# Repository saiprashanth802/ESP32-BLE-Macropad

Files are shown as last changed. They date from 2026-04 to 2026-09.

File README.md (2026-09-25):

# ESP32 BLE HID MacroPad

> An open-source, battery-powered wireless BLE HID macro pad built on ESP32 with NimBLE stack. Hand-wired with a custom FDM-printed enclosure, fully self-contained shortcut controller with an on-device UI — no companion app required.



---

## Versions

Every version lives side by side in this repo — `firmware/v4/`, `firmware/v5/`,
`cad/stl/v5/` and so on. **`main` is always the latest working state**; released
versions are marked with **git tags**, so you can grab any of them:

```bash
git clone https://github.com/saiprashanth802/ESP32-BLE-Macropad.git
git checkout v4.1     # or v5.0 — see Releases for downloadable zips
```

| Version | Tag | Status | Description |
|---|-----|---|---|
| v3 | — | ✅ Complete | 8-button, ST7735 128×160, ESP32-BLE-Keyboard — flagship build |
| v4 | `v4.1` | ✅ Stable | NimBLE stack, ghost connection fix, BUILD MODE |
| v4 + Media Remote | — | 🔬 Testing | Wireless AS5600 scroll wheel via ESP-NOW |
| v5 | `v5.0` | ✅ Built & Running | 12-key MX matrix, ST7789 240×320, multi-host BLE, robot face, Windows companion app |
| v5.1 | `v5.1` | ✅ Current | Local-LLM rewrite menu driven from the pad, wireless encoder puck complete |

---

## v3 — Flagship Build

> Primary portfolio entry. 8-button macro pad with ST7735 display, NimBLE BLE HID, and on-device preset switching with BUILD MODE.

### Build Photos

| | |
|---|---|
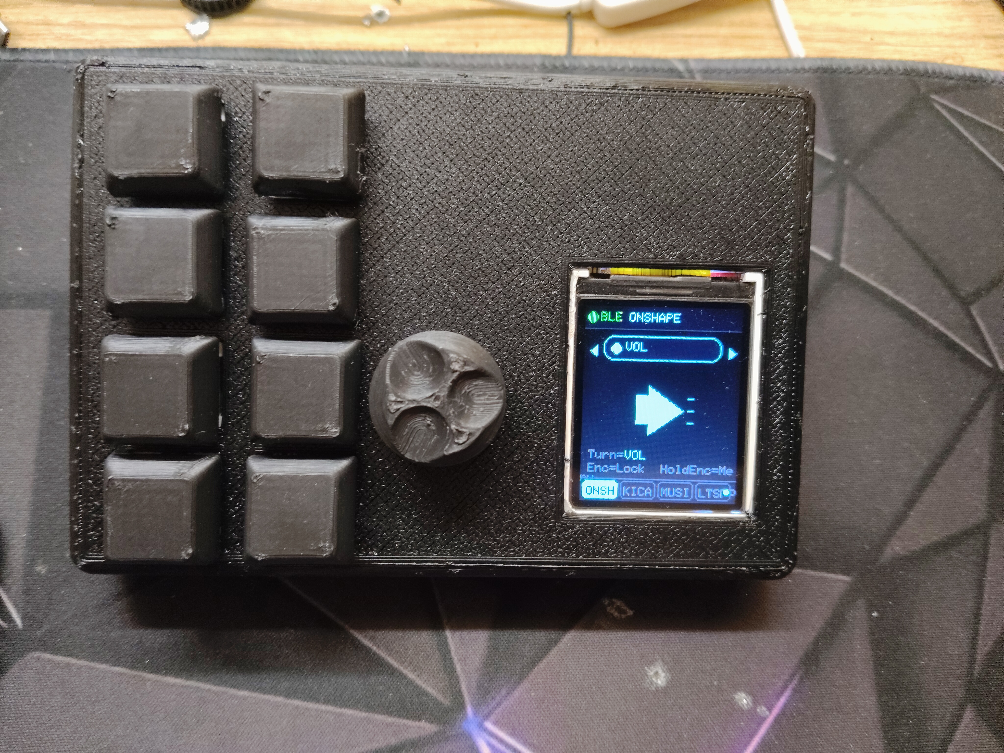
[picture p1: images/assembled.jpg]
Assembled
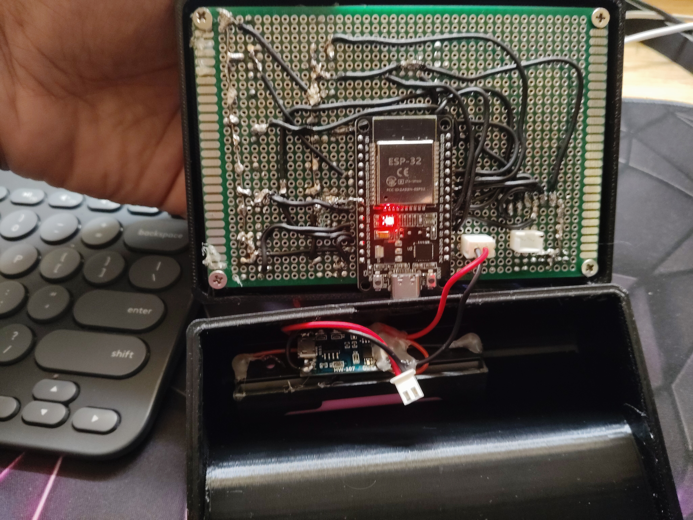
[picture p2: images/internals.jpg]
Internals
|  |  |
| Assembled v3 | Internal wiring |

| | |
|---|---|
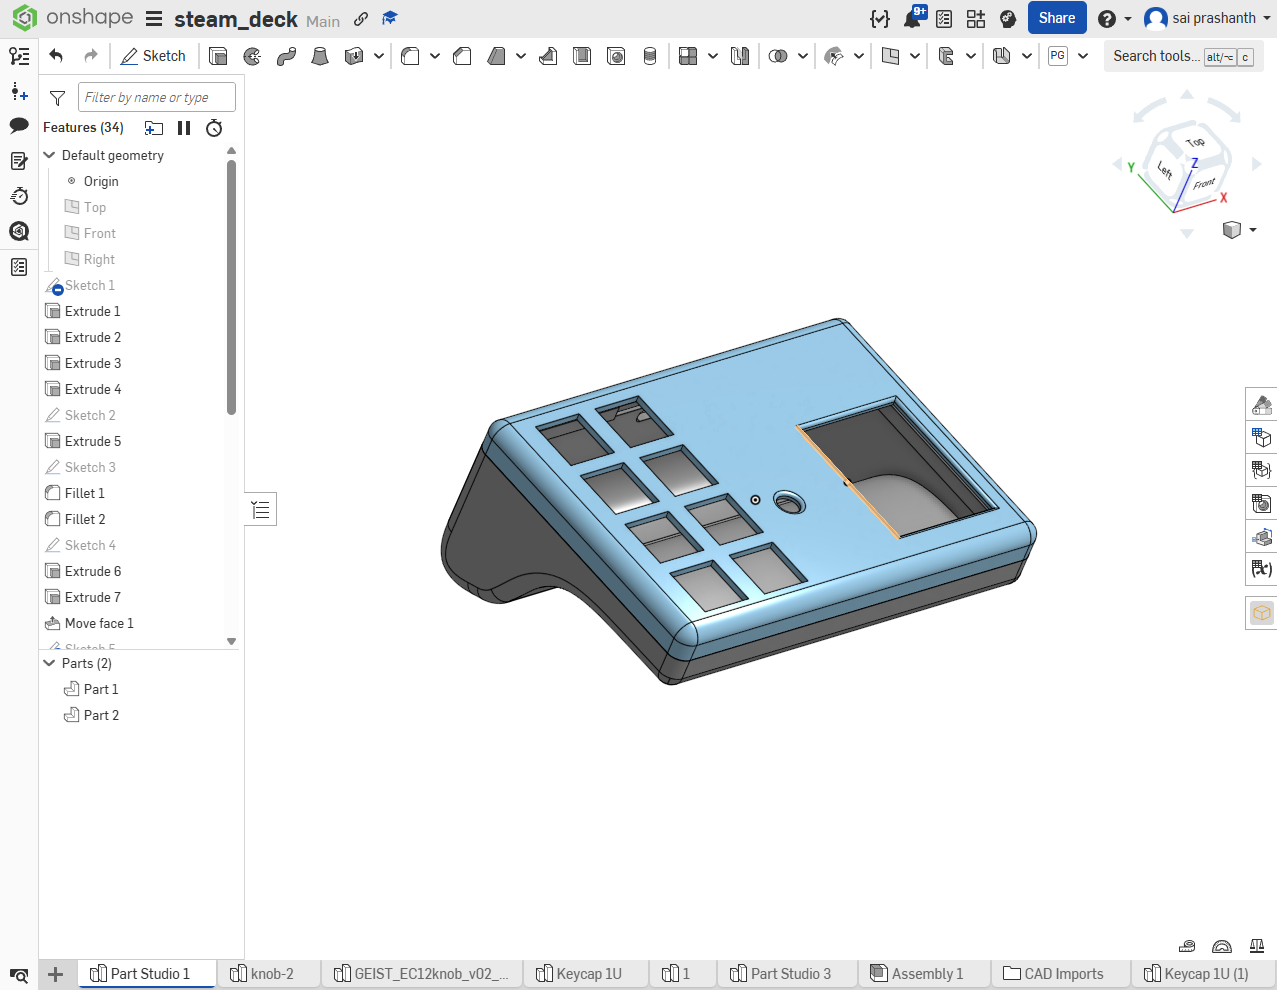
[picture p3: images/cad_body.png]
CAD Body
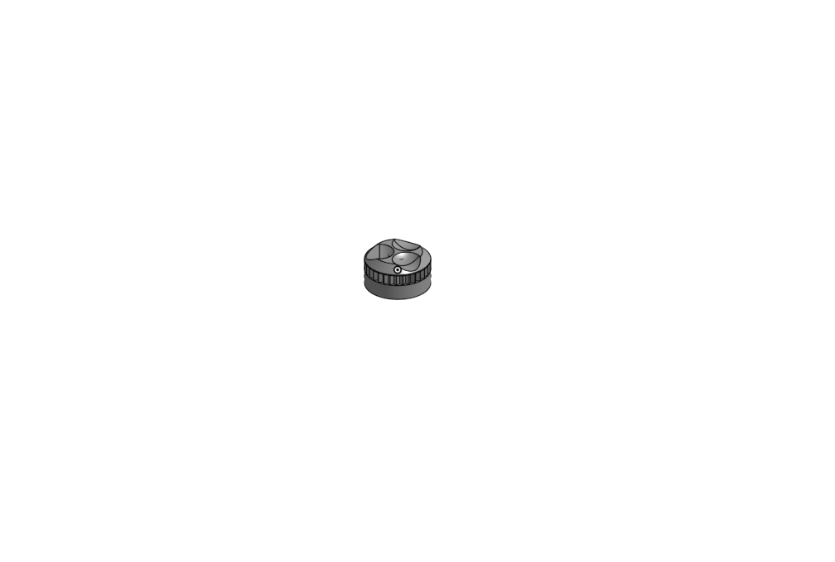
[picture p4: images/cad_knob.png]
CAD Knob
|  |  |
| Enclosure CAD | Encoder knob CAD |

### Hardware
- ESP32 WROOM-32
- ST7735 128×160 TN display
- 8× tactile switches in 4×2 layout
- EC11 rotary encoder + custom skull knob
- TP4056 + 18650 2600mAh battery
- M3 corner studs with heat-set inserts
- Hand-wired, FDM printed enclosure (PLA, 0.2mm, 20% gyroid)

### Features
- 8 presets: OnShape, KiCad, Music, Gaming, LTspice, SYS, DEV, EDIT
- BUILD MODE — remap any button live (hold encoder 1.5s)
- Encoder modes: VOL / SCROLL / ZOOM / ALT-TAB
- Settings menu: brightness, sleep timeout, sensitivity, OS layout
- OS Layout: Windows / Linux — remaps shortcuts live
- RTOS light-sleep with GPIO wakeup
- Wake-key buffer + reconnect HUD
- BLE bond clear (hold encoder 3s)
- Estimated battery life: 3–4 months typical desk use

### GPIO Allocation (v3/v4)

| GPIO | Function |
|---|---|
| 14,13,26,25,22,21,35,19 | 8× buttons |
| 2, 4 | Encoder CLK, DT |
| 15 | Encoder SW |
| 5, 17, 16, 12 | TFT CS, DC, RST, BL |
| 23, 18 | SPI MOSI, SCLK |

---

## v4 — Current Stable

> Migrated to NimBLE-Arduino to fix persistent BLE ghost-connection bug on Windows sleep/wake cycles.

### Key Changes from v3
- NimBLE-Arduino replaces ESP32-BLE-Keyboard
- GAP-layer callbacks for reliable connect/disconnect tracking
- 1N5819 Schottky diode on VIN rail isolating charger from USB supply
- `esp_sleep_disable_wakeup_source()` before re-arming GPIO wakeup each cycle
- `ledcAttach()` called on every wake to restore PWM backlight
- Firmware: `macropad_v4_nimble_espnow.ino`

### TFT_eSPI User_Setup.h

```cpp
#define ST7735_DRIVER
#define TFT_CS   5
#define TFT_DC   17
#define TFT_RST  16
#define TFT_WIDTH  128
#define TFT_HEIGHT 160
#define TFT_MOSI 23
#define TFT_SCLK 18
```

---

## Media Remote — Test Phase

> Standalone wireless scroll wheel using AS5600 magnetic encoder. Connects to v4 macropad via ESP-NOW or directly to PC via BLE HID. Designed for high-resolution smooth scrolling with velocity-based acceleration.

### Hardware
- ESP32 NodeMCU dev board
- AS5600 magnetic rotary encoder (I2C, 12-bit resolution, 4096 steps/rev)
- Custom 3D printed enclosure with bearing-mounted 50mm scroll wheel
- Diametrically magnetized cylinder magnet on axle
- 3× tactile buttons — Play/Pause, Next, Prev

### Design & Prototype

| | |
|---|---|
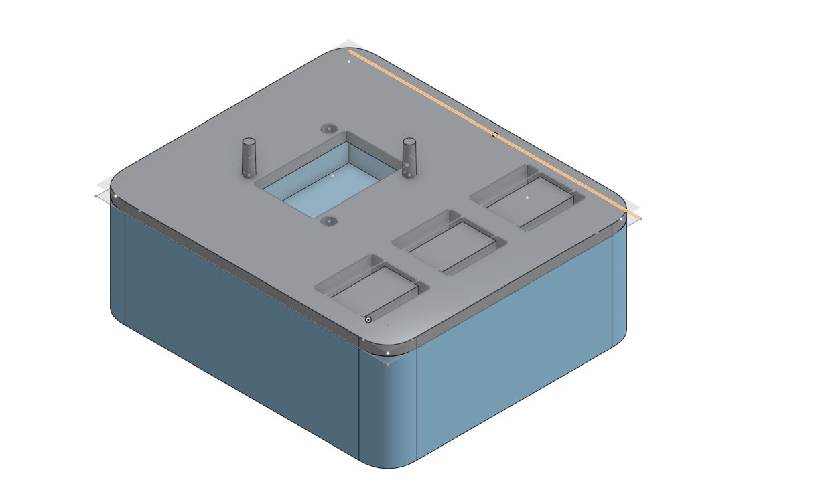
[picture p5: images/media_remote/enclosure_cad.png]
Enclosure CAD
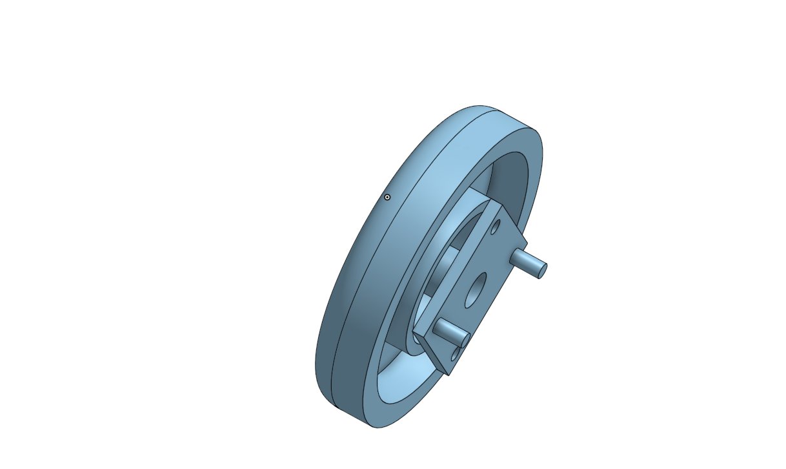
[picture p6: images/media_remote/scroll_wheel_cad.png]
Scroll wheel CAD
|  |  |
| Enclosure CAD | Scroll wheel with bearing mount CAD |

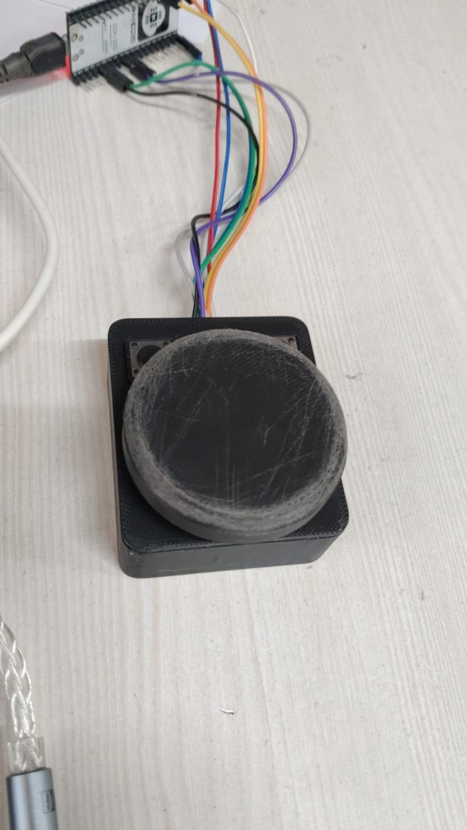
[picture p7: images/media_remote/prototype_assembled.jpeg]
Media remote prototype


*Prototype — printed enclosure with 50mm scroll wheel, AS5600 underneath, wired to NodeMCU ESP32S*

### Features
- Velocity-accelerated volume control — slow turn = fine steps, fast spin = large jumps
- Adjustable sensitivity 1–10, saved to NVS
- Hold Btn1 + turn wheel = adjust sensitivity live
- Hold Btn1 + Btn3 for 1.5s = toggle ESP-NOW ↔ BLE mode
- Mode and sensitivity persist across power cycles
- LED blink feedback: 1 blink = ESP-NOW, 3 blinks = BLE

### Modes

| Mode | Description |
|---|---|
| BLE HID | Connects directly to PC as "MediaRemote" |
| ESP-NOW | Sends to v4 macropad which relays via BLE to PC |

### Wiring

| Pin | GPIO | Function |
|-----|---|---|
| AS5600 SDA | 21 | I2C data |
| AS5600 SCL | 22 | I2C clock |
| BTN1 Play/Pause | 27 | INPUT_PULLUP → GND |
| BTN2 Next | 26 | INPUT_PULLUP → GND |
| BTN3 Prev | 25 | INPUT_PULLUP → GND |
| LED | 2 | Onboard LED |

---

## v5 — Built & Running

> Full redesign, **assembled and working**. 12-key MX mechanical switch matrix (4×3 landscape), ST7789 240×320 IPS display, **multi-host BLE with 3 device slots (Logitech Easy-Switch style)**, a state-reactive robot face with personalities, and a Windows companion app that turns the pad into a Stream Deck.

### Build Photos

| | |
|---|---|
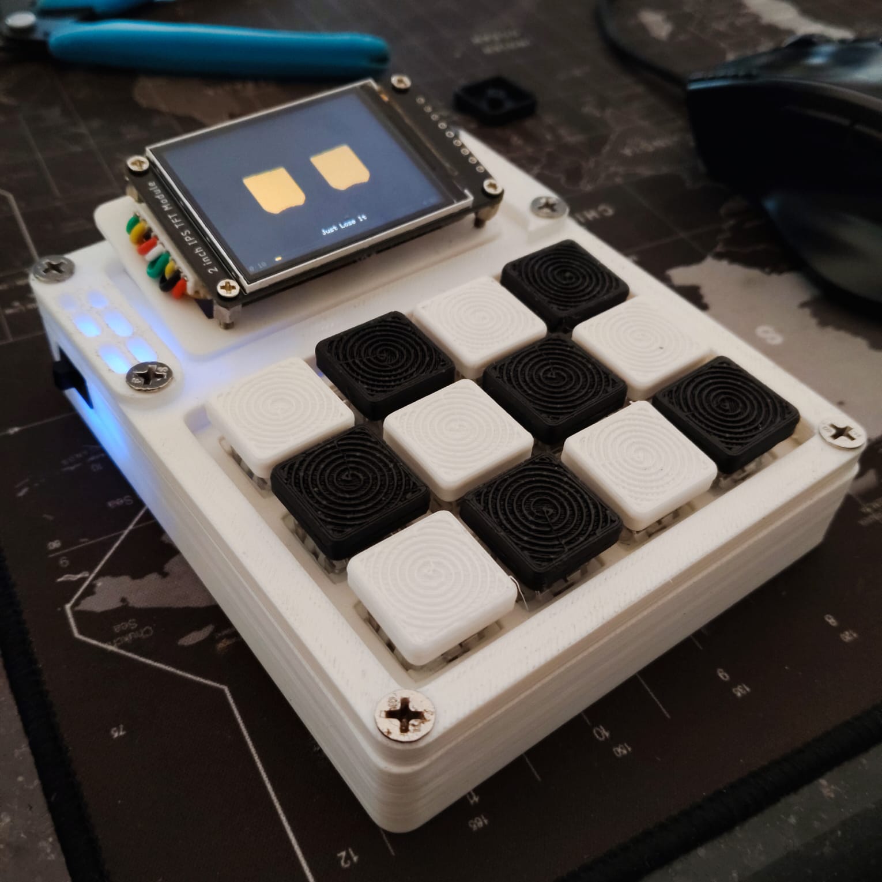
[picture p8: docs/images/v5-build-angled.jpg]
Assembled v5, angled
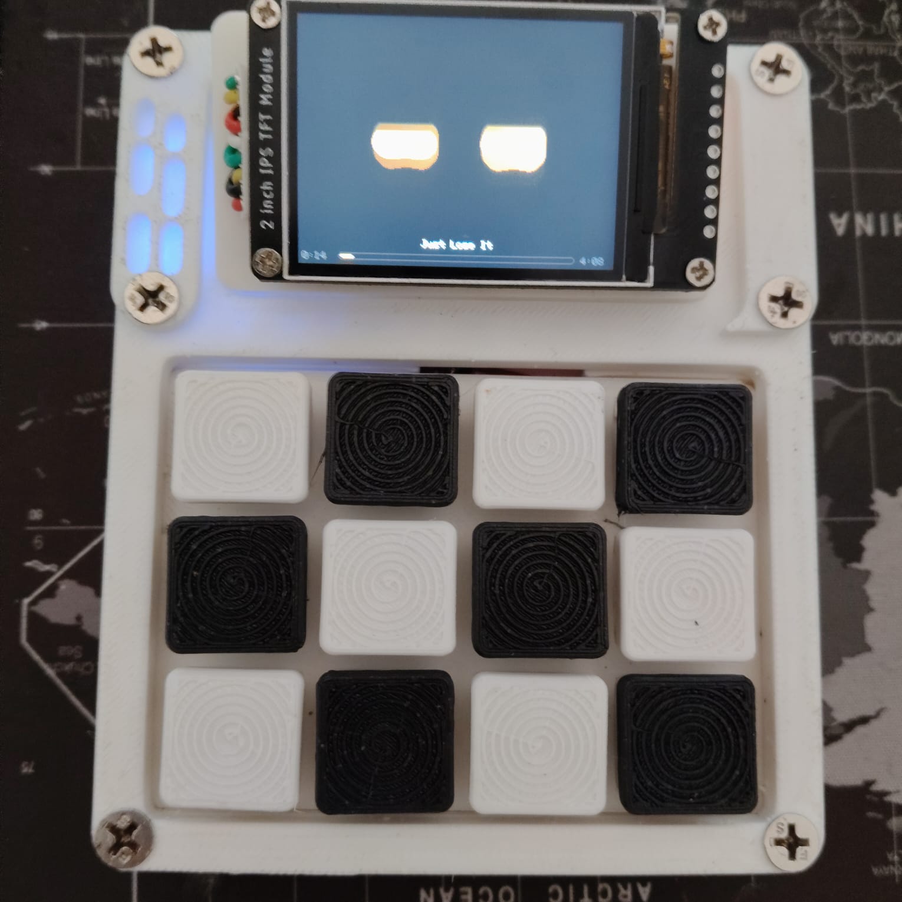
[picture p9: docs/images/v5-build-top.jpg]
v5 from above
|  |  |
| Assembled v5 — printed case, spiral-top keycaps, blue accent lighting | Top-down: 4×3 MX grid and the 2" IPS display |

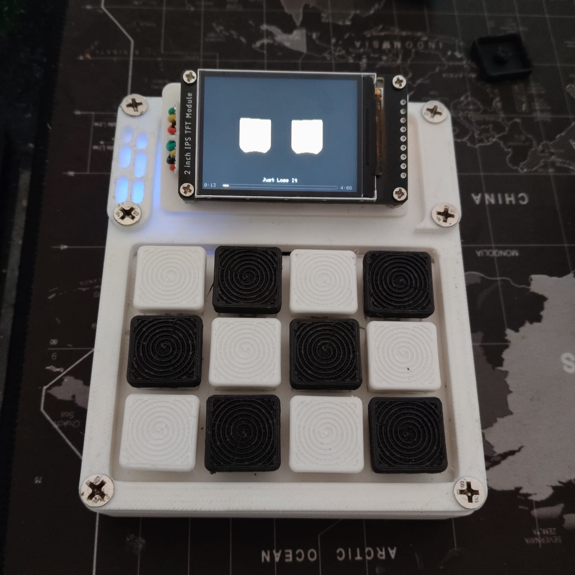
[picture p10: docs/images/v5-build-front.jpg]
v5 front view


*The screen shows the pad's two live features at once: the procedural robot eyes in
their default robotic blue, and the now-playing strip — track title with a progress
bar and elapsed/total time, streamed from the host by the companion app.*

**Print files:** [`cad/stl/v5/`](cad/stl/v5) — three case parts plus the switch plate.

### Multi-Host BLE — use it like a Pebble Keys
- 3 host slots, each remembers one bonded device (NVS persisted across power cycles)
- Hold **FN (K9) 1s** → tap **K1/K2/K3** to jump between paired devices
- Hold the slot key 1.5s instead to (re-)pair that slot with a new device
- **Each slot advertises its own static-random BLE address**, so every host stores an independent bond. This is what makes the slots real: with one shared identity, two OSes dual-booting the same machine present the *same* controller MAC, collapse onto one slot, and each re-pair overwrites the other's link key — the endless forget-and-re-pair loop
- Switching re-advertises **open** (no accept-list — whitelist filtering breaks reconnection from resolvable private addresses); a bonded host that belongs to a different slot is rejected in software
- Status bar shows the three slots like Easy-Switch LEDs (green = connected, amber = waiting, magenta = pairing)
- Firmware: `firmware/v5/macropad_v5.ino` (NimBLE 2.x API, single file)

### Face — state-reactive robot eyes / GIF screensaver
- Procedural eyes that react to device state: blink when idle-connected, dart when disconnected, widen in pairing mode, glance toward the slot on Easy-Switch, droop before sleep
- **Expression packs**: every eye parameter (color, geometry, blink/glance timing) is JSON in the config API — the companion app can generate personalities without reflashing
- Or upload a looping **GIF** (≤ ~700 KB) through the web UI as an ambient screensaver
- Settings → FACE (OFF/IDLE/ALWAYS) and STYLE (EYES/GIF); first press always just wakes, never types
- Custom partition table: dual 1.5 MB OTA slots + 896 KB SPIFFS for animations

### Rewrite Menu — local LLM text tools, driven from the pad
- Select text anywhere, press a key on the pad, pick a style — the pad rewrites it in place
- Styles: formalise, casualise, shorten, clarify, fix spelling/grammar, summarise, expand rough notes into an email, or treat the selection as a prompt and answer it
- Runs against a local **[Ollama](https://ollama.com)** instance, so **nothing leaves the machine** unless a style is deliberately pointed at a hosted model
- Prompts, temperature, reasoning and per-style model live in a **hot-reloaded `styles.json`** — tune them without a rebuild
- Pad shows the style picker, then ACCEPT / REGEN / CANCEL; the side-by-side preview on screen is editable before you accept
- Built entirely on the existing host-link opcodes — **no firmware changes required**
- A **fine-tuned FIX model** was trained for this and measured against the general-purpose
  one across two sizes and four epoch counts. It wins on corrections and speed and loses on
  restraint, which is the axis that decides — so it did not ship, and the lab is in the repo
  anyway: [`ml/`](ml) and [`docs/FIX_MODEL_FINETUNE.md`](docs/FIX_MODEL_FINETUNE.md)
- Full guide: [`docs/REWRITE_MENU.md`](docs/REWRITE_MENU.md) · Linux setup:
  [`docs/LINUX_REWRITE_SETUP.md`](docs/LINUX_REWRITE_SETUP.md)

### Companion App — Windows and Linux

> The pad works standalone. The companion turns it into a Stream Deck: it launches
> and focuses apps from a key press, streams now-playing to the pad's screen,
> switches presets to follow the foreground window, feeds the puck a real volume
> number, and drives the rewrite menu.

- Two front-ends over one shared **.NET 9** core — `MacroPadDeck.Core` holds the wire
  protocol, profiles and orchestration; `MacroPadDeck` is WinRT/SMTC/WPF, and
  `MacroPadDeck.Linux` is BlueZ/MPRIS/X11/GTK3
- **Install, build and run:** [`companion/README.md`](companion/README.md) — .NET 9 SDK
  per platform, the dependencies, pairing, the publish command, and what each failure
  in `deck.log` means

### Config Mode — wireless setup + OTA firmware update
- **Settings → CONFIG (WiFi/OTA)** suspends BLE and raises a WiFi hotspot (`MacroPad-Setup` / `macropad123`, `http://192.168.4.1`)
- Built-in web UI + JSON API to remap keys, edit presets, and change settings — no re-flash needed
- Every key can be a built-in action, an **arbitrary modifier+keycode chord**, a media code, a **type-a-string**, or a **multi-step macro** — the schema a companion app targets
- **OTA firmware update**: upload a new `.bin` from the browser; it flashes the inactive OTA partition and reboots (safe rollback if it fails)
- WiFi and BLE never run at once (WROOM-32 coexistence); entering/leaving Config Mode reboots cleanly
- Full contract: [`docs/CONFIG_API.md`](docs/CONFIG_API.md)

### Wireless Encoder Puck — a dial that isn't attached to anything

| | |
|---|---|
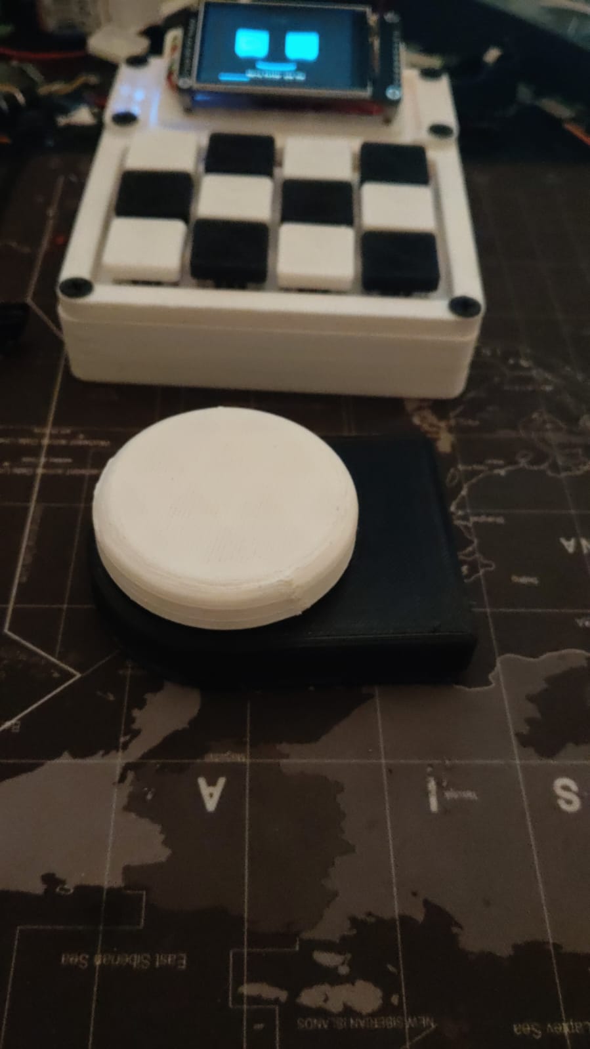
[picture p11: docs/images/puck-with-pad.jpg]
Puck beside the pad
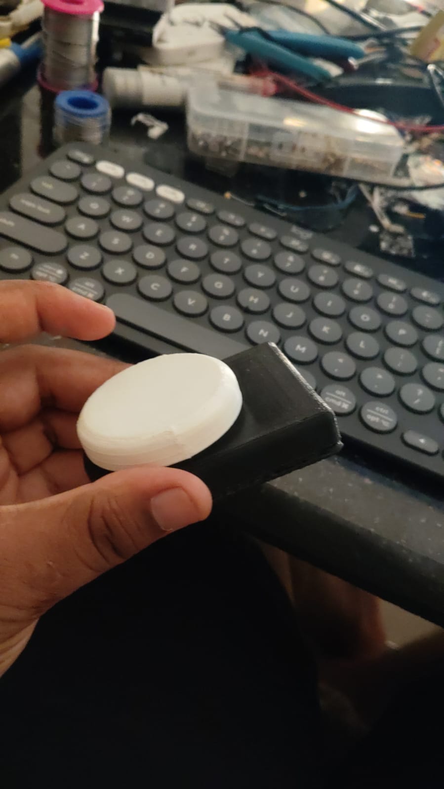
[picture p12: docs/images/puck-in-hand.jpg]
Puck in hand
|  |  |
| The puck beside the v5 — a separate battery-powered device, no cable between them | 50 mm dial in the two-part printed housing |

- **Separate device**, talks to the pad over **ESP-NOW** — no cable, no second BLE connection to manage
- **AS5600 magnetic angle sensor** — 12-bit, contactless, nothing mechanical to wear out. The magnet is diametrically magnetised and sits in a pocket in the dial
- **The pad owns the dial mode** (VOLUME / ZOOM). The puck renders whatever it's told and never self-changes, so a pad key and the puck can't disagree
- **Volume is pushed, never estimated.** BLE HID volume is relative — the pad sends up/down and is never told the level — so the companion reading Windows Core Audio is the only way either device knows a real number
- **Deep sleep when unlinked**, waking on rotation. The AS5600 has no motion interrupt, so waking is timer-poll-and-look with a movement threshold, which stops a knock or thermal drift waking it
- **Sealed housing with no reset button** — spinning the dial a few turns while unlinked reboots it. Gated strictly on being unlinked, since spinning hard is completely ordinary during normal volume use
- Wiring: [`hardware/puck_wiring.md`](hardware/puck_wiring.md) · Protocol: [`docs/PUCK_PROTOCOL.md`](docs/PUCK_PROTOCOL.md) · Print files: [`cad/stl/puck/`](cad/stl/puck)

### Hardware Spec
- NodeMCU ESP32-S V1.1 (WROOM-32) dev board
- ST7789 240×320 IPS display, landscape mount, glass flush-mounted (30.6×40.8mm active area)
- 12× MX compatible mechanical switches, plate mount, 4×3 landscape matrix, 19.05mm pitch
- 12× 1N4148 diodes for n-key rollover (cathode → row line — see `hardware/pin_reference_v5.md`)
- Wireless encoder puck: AS5600 + 50mm bearing-mounted dial, ESP-NOW (separate device — **built and working**; see [`hardware/puck_wiring.md`](hardware/puck_wiring.md) and [`docs/PUCK_PROTOCOL.md`](docs/PUCK_PROTOCOL.md))
- CKCS charge+boost module + 18650 cell
- Custom copper-tape ridge substrate PCB

### Enclosure
- 115×95×30mm main body
- Encoder dial lobe: half-proud right edge, 50mm diameter, 25mm proud (XP-Pen style)
- Screen: 31.0×41.2mm flush glass window, 35.2×48.4mm module ledge 2.1mm deep
- Bottom cover: M3 screws into brass heat-set inserts, 4× corners

### PCB Technique — Copper Tape Ridge Substrate
3D printed plate with elevated ridges as trace isolation guides. A single copper sheet is laid over the entire surface — the ridges act as cutting guides. Scalpel-cut along ridge edges isolates traces. Looks like a real PCB, built from scratch.

### v5 GPIO Allocation

| GPIO | Board Label | Function | Notes |
|---|---|---|---|
| 18 | P18 | TFT SCK | SPI clock |
| 23 | P23 | TFT MOSI | ST7789 SDA |
| 5  | P5  | TFT CS  | |
| 21 | P21 | TFT DC  | |
| 22 | P22 | TFT RST | |
| 19 | P19 | TFT BL  | PWM via LEDC |
| 25 | P25 | Matrix Row 1 | Driven LOW to scan |
| 26 | P26 | Matrix Row 2 | Driven LOW to scan |
| 27 | P27 | Matrix Row 3 | Driven LOW to scan |
| 32 | P32 | Matrix Row 4 | Driven LOW to scan |
| 33 | P33 | Matrix Col 1 | INPUT_PULLUP |
| 13 | P13 | Matrix Col 2 | INPUT_PULLUP |
| 14 | P14 | Matrix Col 3 | INPUT_PULLUP |

> Zero strapping pins used — clean boot every time, no pull resistors needed for boot. No I2C or encoder switch on the main board — the AS5600 puck is wireless. Full details + diode orientation: `hardware/pin_reference_v5.md`.

---

## Repository Structure

```
ESP32-BLE-MacroPad/
├── firmware/
│   ├── v4/macropad_v4_nimble_espnow.ino   — v4 + optional ESP-NOW
│   ├── v5/
│   │   ├── macropad_v5/                   — v5 multi-host firmware + partition table
│   │   ├── puck_encoder/                  — wireless encoder puck (ESP32)
│   │   ├── puck_encoder_8266/             — puck on ESP-12E
│   │   └── User_Setup.h                   — TFT_eSPI config for the ST7789
│   ├── media_remote/                      — BLE + ESP-NOW scroll wheel
│   └── tests/                             — per-peripheral bring-up sketches
├── companion/
│   ├── README.md                          — install / build / run — start here
│   ├── MacroPadDeck.Core/                 — protocol, profiles, controller (net9.0)
│   ├── MacroPadDeck/                      — Windows front-end (WinRT/WPF)
│   └── MacroPadDeck.Linux/                — Linux front-end (BlueZ/MPRIS/GTK3)
├── ml/                                    — the FIX fine-tune lab: data generator,
│                                            eval harness, training configs, runbook
├── cad/stl/                               — print files: v5 case, keycaps, puck
├── hardware/
│   ├── pin_reference_v5.md                — complete v5 GPIO table + diode orientation
│   ├── puck_wiring.md                     — encoder puck wiring
│   ├── kicad/                             — KiCad project + fab gerbers
│   ├── datasheets/                        — ESP-12E
│   └── ESP32_DevKitC_v4.kicad_mod         — custom KiCad footprint
├── docs/
│   ├── CONFIG_API.md                      — host-link opcodes and the JSON config API
│   ├── REWRITE_MENU.md                    — local-LLM text tools
│   ├── LINUX_REWRITE_SETUP.md             — ydotool / Wayland one-time setup
│   ├── FIX_MODEL_FINETUNE.md              — the fine-tune, measured, and why it lost
│   ├── PUCK_PROTOCOL.md                   — ESP-NOW protocol v3
│   └── ROADMAP.md · TESTING_LOG.md
├── scripts/setup-ydotool.sh
└── README.md
```

---

## Dependencies

| Library | Purpose |
|---|---|
| NimBLE-Arduino | BLE HID stack |
| TFT_eSPI | Display driver |
| Preferences | NVS persistent storage |
| Wire | I2C for AS5600 |
| esp_now | ESP-NOW for media remote |

Companion app (see [`companion/README.md`](companion/README.md)):

| Requirement | Purpose |
|---|---|
| .NET 9 SDK | Builds all three companion projects |
| BlueZ / WinRT | BLE host link to the pad |
| GTK3 + libayatana-appindicator | Linux tray and editor |
| MPRIS / SMTC | Now-playing source |
| Ollama (optional) | Local model behind the rewrite menu |

---

## Key Learnings

- **NimBLE vs ESP32-BLE-Keyboard** — NimBLE with GAP callbacks is required for reliable connect/disconnect tracking. The Arduino BLE stack returns false positives after Windows sleep/wake.
- **GPIO 12 strapping pin** — Must read LOW at boot. Avoided entirely in v5 by moving TFT backlight to GPIO 19.
- **LEDC + BLE init order** — BLE radio init resets the LEDC peripheral. Always call `ledcAttach()` after `NimBLEDevice::init()`.
- **WiFi + BLE coexistence** — ESP-NOW and NimBLE share the antenna. Made optional in v4 (toggle in settings) to avoid connection instability.
- **ST7789 RAM constraint** — Full 240×320 16-bit sprite = 153KB, too large for WROOM-32 with BLE active. Solution: direct TFT drawing with small reusable sprites.
- **Input-only GPIOs** — GPIO 34, 35, 36, 39 have no internal pullups. Always use external 10kΩ resistors.

---

## License

**CC BY-NC 4.0** — Free to use and modify for personal and non-commercial purposes only. Commercial use requires explicit written permission from the author.

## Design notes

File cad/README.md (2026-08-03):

# CAD — Print Files

All STL files are export-ready. Slice and print as-is.

## v5 — the built pad (current)

These are the parts in the photos in the main README — 12-key 4×3 layout with a
2" IPS TFT above the grid. **Use these for a v5 build**; the folders below are
the earlier encoder-based design.

```
cad/stl/v5/
├── v5_case_bottom.stl        ← bottom shell (ESP32 + wiring bay)
├── v5_case_top_plate.stl     ← top plate (key openings + display shelf)
├── v5_display_mount.stl      ← display mount (2" IPS TFT carrier)
├── v5_switchplate.stl        ← switch plate (12 × MX cutouts, 19.05mm pitch)
└── v5_keycap_low_profile.stl ← low-profile keycap, print 12×
```

**Stack-up, bottom to top:** case bottom → switch plate (switches clip in) →
top plate → display mount carrying the TFT on the raised shelf. M3 screws pass
through the corner bosses to hold the sandwich together.

### Print settings (as actually printed)

| Part | Qty | Layer | Walls | Infill |
|---|-----|---|---|---|
| Case parts, switch plate | 1 each | 0.2 mm | 3 | 30% adaptive cubic |
| `v5_keycap_low_profile.stl` | 12 | 0.12 mm | 3 | 100% |

White PLA for the case; the build in the photos alternates black and white
keycaps in a checkerboard. The fine layer height plus solid infill is what gives
the keycaps their crisp concentric spiral top surface — the pattern is the
slicer's top-surface path, so **keep the 100% infill and 0.12 mm layers if you
want that look**. The assembled unit is lit by a blue LED strip behind the
left-hand vent slots.

## Encoder puck (wireless dial)

The standalone ESP-NOW knob — see `docs/PUCK_PROTOCOL.md` for the firmware side
and `hardware/puck_wiring.md` for the electronics.

```
cad/stl/puck/
├── puck_dial.stl               ← the knob itself        50 × 50 × 12 mm
├── puck_dial_counterpart_1.stl ← housing body           73 × 55 × 17 mm
└── puck_dial_counterpart_2.stl ← housing lid / plate    73 × 55 ×  7 mm
```

The two counterpart parts share a 73 × 55 mm footprint and stack to 24 mm; the
50 mm dial seats into them. The three files are a **matched set** — don't mix
them with an earlier counterpart export.

> ✅ **Printed and test-fitted (2026-08-03).** The dial spins freely with no
> wobble, both counterpart halves mate, and the **AS5600 magnet pocket worked
> first time** — no tolerance iteration was needed, despite the gap being the one
> dimension the sensor is genuinely fussy about (diametrically magnetised magnet,
> centred on the chip, **0.5–3 mm**). A radial or axially magnetised magnet will
> not work at any gap.

| | |
|---|---|
| Printed puck beside the pad | Printed puck in hand |
| The printed puck beside the v5 | Dial seated in the two-part housing |

The dial is sealed in the housing with no reachable reset button, by design — the
firmware reboots on a fast spin gesture instead. See
[`hardware/puck_wiring.md`](../hardware/puck_wiring.md).

## Earlier design (v2/v3, encoder-based)

```
cad/stl/
├── enclosure/
│   ├── enclosure_top.stl    ← top shell  (buttons + display + encoder cutouts)
│   └── enclosure_base.stl   ← base tray  (PCB + 18650 cell bay)
├── keycap/
│   ├── keycap_v1.stl        ← keycap body (main variant, high detail)
│   ├── keycap_v2.stl        ← keycap variant 2
│   ├── keycap_v3.stl        ← keycap variant 3 (minimal)
│   └── keycap_v4.stl        ← keycap variant 4
└── knob/
    └── encoder_knob.stl     ← EC12 encoder knob (GEIST KLOTZ v4, press-fit D-shaft)
```

## 🖨 Print Settings

| Part | Qty | Layer  | Walls | Infill | Supports |
|---|-----|---|---|---|---|
| enclosure_top.stl | 1 | 0.2mm  | 3 | 20% gyroid | Yes (TFT overhang) |
| enclosure_base.stl | 1 | 0.2mm  | 3 | 20% gyroid | No |
| keycap_v*.stl | 8x  | 0.15mm | 3 | 15% | No |
| encoder_knob.stl | 1 | 0.15mm | 4 | 20% | No |

- Material: PLA (PETG also works for keycaps)
- Bed adhesion: Brim for enclosure parts, Skirt for keycaps/knob
- Keycaps are press-fit over 12x12mm tact switches — no hardware needed
- Encoder knob is press-fit on the EC11/EC12 6mm D-shaft

## 🔧 Assembly Notes

- Print 8 keycaps (same file, plate them in your slicer)
- Enclosure top and base friction-fit or secure with M3 screws through corner bosses
- The TFT module slots into the rectangular window in enclosure_top.stl
- Encoder shaft passes through the circular hole beside the TFT window

## 🛠 CAD Source

Modelled in Onshape (browser-based, free for public projects).
Project name: steam_deck

## v2 -> v3 CAD Improvements Planned
- [ ] Snap-fit lid clips (replace friction fit)
- [ ] Internal standoffs for PCB screw mounting
- [ ] Tighter TFT window clearance
- [ ] Dedicated 18650 retainer in base tray
- [ ] Cable channel for battery wires

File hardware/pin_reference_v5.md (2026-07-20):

# MacroPad v5 — Pin Reference (multihost wiring)

Board: **NodeMCU ESP32-S V1.1** (WROOM-32, no PSRAM). P-label = GPIO number (P18 = GPIO18).
13 pins used: TFT SPI (6) + 4×3 matrix (7). The AS5600 encoder is now a
**separate wireless puck** (ESP12-E + ESP-NOW) — no I2C or encoder switch on
the main board anymore.

## ESP32 GPIO Allocation

| GPIO | Board Label | Function | Direction | Notes |
|---|---|---|---|---|
| 18 | P18 | TFT SCK  | OUTPUT | SPI clock |
| 23 | P23 | TFT MOSI | OUTPUT | SPI data (ST7789 SDA) |
| 5  | P5  | TFT CS | OUTPUT | HIGH at boot — fine |
| 21 | P21 | TFT DC | OUTPUT | |
| 22 | P22 | TFT RST  | OUTPUT | |
| 19 | P19 | TFT BL | OUTPUT | PWM via LEDC (sketch-driven) |
| 25 | P25 | Matrix Row 1 (top) | OUTPUT | driven LOW one at a time |
| 32 | P32 | Matrix Row 2 (mid) | OUTPUT | driven LOW one at a time |
| 33 | P33 | Matrix Row 3 (bot) | OUTPUT | driven LOW one at a time |
| 26 | P26 | Matrix Col 1 | INPUT | INPUT_PULLUP |
| 14 | P14 | Matrix Col 2 | INPUT | INPUT_PULLUP, JTAG-shared (fine) |
| 27 | P27 | Matrix Col 3 | INPUT | INPUT_PULLUP |
| 13 | P13 | Matrix Col 4 | INPUT | INPUT_PULLUP, JTAG-shared (fine) |
| VIN | 5V | Power in  | POWER | From CKCS 5V out |
| 3V3 | 3V3 | 3.3V out | POWER | To TFT VCC |

All matrix inputs use internal pullups — no external resistors needed
(GPIO 34/36/39 input-only pins are no longer used).

## Key Matrix (3 rows × 4 cols = 12 keys) — AS BUILT

**Verified on hardware 2026-07-20 with a pairwise conduction probe** — this
supersedes every earlier pin grouping. The 3 physical rows are the driven
lines; the 4 physical columns are read with `INPUT_PULLUP`.

```
           Col1(26)  Col2(14)  Col3(27)  Col4(13)
Row1(25)     K1        K2        K3        K4
Row2(32)     K5        K6        K7        K8
Row3(33)     K9(FN)    K10       K11       K12
```

Logical key index in firmware: `idx = row*4 + col` — identical to the
landscape grid the display shows. K9 (bottom-left) = FN.

### Diode orientation (verified)

Each switch has a 1N4148 with the **cathode (band) toward the ROW line**
(P25/P32/P33); current flows column → switch → row. The firmware's
row-driven scan matches this as-built orientation.

## Strapping Pins — Avoided

| GPIO | Issue | Status |
|---|---|---|
| 0, 2, 12, 15 | Boot mode / flash voltage | **Not used at all** |

If your board has PSRAM, GPIO 16/17 are reserved — this pinout avoids them
too (standard NodeMCU-32S WROOM-32 has no PSRAM).

## TFT_eSPI configuration

Copy `firmware/v5/User_Setup.h` over
`<Arduino sketchbook>/libraries/TFT_eSPI/User_Setup.h`. It contains the pins
above, `ST7789_DRIVER`, 40MHz SPI and the font loads (`LOAD_GLCD` is
mandatory — text renders blank without it).

## Flashing this specific board (bench NodeMCU-32S, MAC 84:1F:E8:2B:33:48)

Its Boya flash chip (mfr 0x68) **cannot run at the default 80MHz flash clock**
— the 2nd-stage bootloader crash-loops printing only `entry 0x4008059c`.
In Arduino IDE set:

- **Tools → Flash Frequency → 40MHz**  (mandatory)
- **Tools → Upload Speed → 115200**  (921600 aborts with
  "Packet content transfer stopped" on this board/cable)

Also disconnect the display while flashing, and power it from **3V3, never
5V** — an overdriven backlight sags the rail enough to kill flash writes.

## Power Chain

```
USB-C socket → CKCS module USB-C pads (wired)
CKCS B+ / B- → 18650 cell
CKCS 5V out  → ESP32 VIN
ESP32 3V3    → TFT VCC
```

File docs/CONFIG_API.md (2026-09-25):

# MacroPad v5 — Config & OTA API

The device exposes a small HTTP + JSON API used to change layouts, key
assignments, shortcuts and to push firmware updates over the air. This is the
stable contract a companion app or script targets.

## Entering Config Mode

On the device: **Settings → CONFIG (WiFi/OTA)**. This:

1. Tears down BLE (frees the radio + RAM — WiFi and BLE don't coexist well on
   the WROOM-32).
2. Starts a WiFi SoftAP:
   - SSID: `MacroPad-Setup`
   - Password: `macropad123`
   - Device IP: `http://192.168.4.1`
3. Serves a built-in web UI at `/` and the JSON API below.

Exit: tap **Exit** in the web UI (`POST /api/exit`) or **hold FN (K9)** on the
device for ~1.5 s. Either way the device reboots back into keyboard mode.

> While in Config Mode the macropad is **not** a keyboard — it's a WiFi access
> point. This is by design.

## Endpoints

| Method | Path | Purpose |
|---|---|---|
| GET  | `/` | Built-in web config UI (HTML) |
| GET  | `/api/info` | Device/firmware/capability info |
| GET  | `/api/actions`  | Built-in action library (id + label) |
| GET  | `/api/config` | Full config (settings + presets + face) |
| POST | `/api/config` | Apply + persist config (JSON body) |
| POST | `/api/update` | OTA firmware upload (multipart `.bin`) |
| POST | `/api/exit` | Save nothing, reboot to keyboard mode |
| GET  | `/api/anim` | List uploaded GIF animations + storage usage |
| POST | `/api/anim` | Upload a `.gif` (multipart; ≤ ~700 KB free space) |
| POST | `/api/anim/select` | `{"name":"/x.gif"}` — set as active face animation |
| POST | `/api/anim/delete` | `{"name":"/x.gif"}` — delete from storage |

### `GET /api/info`
```json
{ "device":"ESP32 MacroPad", "fw":"v5-multihost", "api":3,
  "keys":12, "presets":8, "slots":3, "macroMax":6, "heap":123456 }
```

### `GET /api/config` / `POST /api/config`
```json
{
  "api": 2,
  "settings": { "brightness":180, "sleepMin":5, "linux":false, "activePreset":0 },
  "presets": [
    { "name":"ONSHAPE", "keys": [ /* exactly 12 key objects */ ] }
  ]
}
```
POST may send a partial document — only the `settings` fields and `presets`
entries present are applied; the rest are left unchanged. Presets and keys are
matched positionally (preset 0..7, key 0..11). Saved to NVS immediately.

### Key object — one of five `type`s

```jsonc
// built-in action from /api/actions (OS-layout aware)
{ "label":"Fit", "type":"builtin", "id":140 }

// arbitrary key chord: mod is a bitmask Ctrl=1 Shift=2 Alt=4 Gui=8
{ "label":"SaveAs", "type":"key", "mod":3, "key":22 }         // Ctrl+Shift+S

// media / consumer usage code
{ "label":"Play", "type":"consumer", "consumer":205 }

// type an ASCII string (max 23 chars)
{ "label":"email", "type":"text", "text":"me@example.com" }

// macro: up to 6 steps, each a chord OR a consumer, with a post delay (×10ms)
{ "label":"Run", "type":"macro", "steps":[
    { "mod":8, "key":21, "delay":30 },   // Gui+R, wait 300ms
    { "mod":0, "key":40 }                // Enter
]}

// host: notify the companion app over the host-link GATT service instead of
// typing. mod/key is an OPTIONAL fallback chord sent when no app is listening.
{ "label":"Steam", "type":"host", "mod":0, "key":0 }
```

- `mod` bitmask: `Ctrl=1 Shift=2 Alt=4 Gui(Win/Cmd)=8` (combine by OR).
- `key` is a **USB HID keyboard usage code** (decimal). e.g. A=4 … Z=29,
  1=30 … 0=39, Enter=40, Tab=43, F11=68, arrows Right/Left/Down/Up=79/80/81/82.
- `consumer` is a **USB HID consumer usage code**: Play/Pause=205, Next=181,
  Prev=182, Mute=226, Vol+=233, Vol−=234.
- An **empty** slot is `{ "label":"", "type":"builtin", "id":0 }` (id 0 = A_NONE).

### `POST /api/update` — OTA
Multipart/form-data with the compiled `firmware.bin` as the file part. On
success the device flashes the inactive OTA partition and reboots into it; on
failure the running firmware is untouched. Build the `.bin` with the exact
board options below or the device won't boot it.

## Face / screensaver ("expression packs")

The device shows a state-reactive robot-eyes face (blinks when idle-connected,
darts when disconnected, widens in pairing, winks toward a slot on Easy-Switch,
droops before sleep) or an uploaded looping GIF. Everything is controlled from
the `face` object in `/api/config`:

```jsonc
"face": {
  "mode":  "idle",        // "off" | "idle" (screensaver) | "always"
  "style": "eyes",        // "eyes" (procedural) | "gif" (uploaded loop)
  "gif":   "/idle.gif",   // active animation (from /api/anim)
  "personality": "calm",  // "calm" | "playful" | "grumpy" | "sleepy"
  "dance": 60,            // face v3: 0 still … ~30 nod … 100 full party
  "flairBars": 8,         // face v3: bars between flair-emote chances, 0 = never
  "eyes": {               // timing + colour; face v3 ignores the size fields
    "color": 0,           // RGB565 eye color; 0 = follow active preset color
    "eyeW": 64, "eyeH": 84, "gap": 44, "round": 18,   // kept for old blobs, unused
    "blinkMinS": 3,  "blinkMaxS": 6,      // idle blink interval (s)
    "glanceMinS": 7, "glanceMaxS": 15,    // idle glance interval (s)
    "pairScalePct": 115,                  // wide-eye scale in pairing mode
    "idleS": 12                           // IDLE: seconds before the face shows
  }
}
```

All eye fields are clamped device-side to renderable bounds. A companion app
"generates a personality" by POSTing a new `eyes` object — no reflash needed.

### Face v3: one visor face, emotes, dance

One look only: glowing eyes and mouth on the dark screen. Both are
signed-distance shapes rendered into a single 240×150 4-bit sprite with a
16-level glow palette, and every shape number is a spring, so any expression
morphs smoothly into any other. `firmware/v5/tools/face-preview.html` runs the
same maths in a browser: tune expressions there, *Copy as C*, paste into
`EXPR[]`.

**Expressions / emote ids** (wire order): `0` neutral, `1` happy, `2` joy,
`3` love, `4` surprised, `5` angry, `6` sad, `7` tired, `8` sleepy,
`9` focused, `10` wink, `11` skeptical, `12` vibing, `13` dizzy. `0xFF` in the
emote map = a random flair emote.

**Resting face** is a point on a valence × arousal mood map: nine cells, each an
expression at a strength (`MOOD_GRID`), blended bilinearly. The pad's own mood
comes from typing rate and link health; the companion leans it with `setMood`
(`0x8D`) and drives the dance with `setBeat` (`0x8E`).

**Pad-side triggers** (wire order, the pad fires these itself): `0` boot,
`1` connect, `2` disconnect, `3` typing burst, `4` idle ≥ 60 s, `5` wake press,
`6` preset picked on the pad, `7` host slot switch, `8` new track, `9` track
favourited, `10` music paused, `11` dance flair. Each has an emote, a chance and
a cooldown; the cooldown is spent on every attempt, won or lost. The table
lives in NVS `emap`, written only when `setEmoteMap` asks to persist.

**Dance** runs on the beat clock while music plays: bob, sway, tilt, side-step,
bounce, and a headbang when arousal is high. `dance` (NVS `dlvl`) picks how
much: 0 still, < 35 bob only, < 70 adds sway and tilt, above that every move.
Moves change every 4 bars; every `flairBars` bars (NVS `dflr`) the flair
trigger gets a roll.

### Personality

`eyes` sets how the face *looks*; `personality` sets how it *behaves*. Each
persona is a tuning table baked into firmware that scales blink and glance
intervals, emote intensity and length, micro-behaviour rates, and a resting mood
bias (face v3 no longer uses the persona rest pose — the mood map owns posture):

| Persona | Feel |
|---|---|
| `calm` | Steady, slightly heavy lids, unhurried glances (default) |
| `playful` | Fast blinks, frequent glances and saccades, big reactions |
| `grumpy`  | Slow, inward-slanted lids, damped reactions |
| `sleepy`  | Half-lidded, rare glances, yawns often |

POST accepts the name (case-insensitive) or the index `0..3`. Unknown names are
ignored rather than clamped, so a typo can't silently change the persona.

On top of the persona, a **mood** drifts on a minutes-long clock: energy tracks
how much you have been typing, valence tracks whether the BLE link is healthy.
Mood biases lid weight and lid angle, so a busy pad looks alert and a neglected
one looks bored, without the persona changing.

The face also **emotes** on events: waking up at boot, a happy bounce when a
host connects, a sad look-around on disconnect, a wink toward the slot on
Easy-Switch, an excited wobble during a fast typing burst, a glance toward the
key you just pressed, and an occasional yawn after a long idle. Emotes are
time-boxed and always yield to pairing mode and the pre-sleep droop, which
report real device state.

### Mode differences

In `"idle"` mode the face is a screensaver: the first press only wakes it and is
never typed. In `"always"` mode the face *is* the main screen — keys type
straight from it with normal tap/hold behaviour, the grid never flashes, and
holding FN opens the SYSTEM menu.

> **Face mode and face screen are different things.** `faceMode` decides whether
> the pad *returns* to the face; `currentScreen` decides what is drawn right now.
> Setting mode `0` over the host link therefore also forces the pad off the face
> screen — without that, a host that turned the face off in order to show the key
> grid would draw its labels behind the eyes, and in `"always"` mode nothing would
> move off the face until a wasted key press woke it. `setPreset`, `setColor` and
> `setStatus` all guard their redraw on the grid being visible, so they are silent
> no-ops while the face is up.

GIF notes: hardware cannot decode MP4/H.264; convert to GIF first
(`ffmpeg -i in.mp4 -vf "fps=12,scale=320:-1" out.gif`). Playback is centered,
looped, ~10–25 fps depending on GIF complexity. While `style` is `"gif"` the
face does not react to state (a canned loop can't); `"eyes"` is the reactive
mode.

On-device controls: **Settings → FACE** cycles OFF/IDLE/ALWAYS, **Settings →
STYLE** toggles EYES/GIF, **Settings → PERSONA** cycles the four personalities.
The config web UI has a Face personality dropdown.

## "Launching apps" — the host-link GATT service

True app-launch happens on the host, not the keyboard. The pad carries a
custom GATT service alongside HID (same bond, same connection) that a
companion app uses for two-way communication. Keys of `type":"host"` send an
*event* over this service instead of typing; the companion decides what to do
(launch, focus, run a script). If no app is subscribed, the key falls back to
its embedded `mod`/`key` chord (if any), so the pad degrades gracefully.

**Service** `6d616372-6f70-6164-0000-000000000001` (ASCII "macropad"):

| Characteristic | UUID suffix | Props | Direction |
|---|---|---|---|
| Events | `...0002` | Notify | device → host |
| Commands | `...0003` | Write (encrypted) | host → device |

Wire format both ways: `[opcode:1][len:1][payload:len]`.

**Events (device → host):**

| Op | Name | Payload |
|----|---|---|
| `0x01` | hello  | `[fwMajor][keys][presets][activePreset][faceMode][persona][faceCaps]` — sent on subscribe; `faceCaps` bit `0x80` = face v3 (understands `0x91`–`0x93`). Face v2 builds sent their feature bitmask here |
| `0x02` | key | `[preset][keyIdx]` — a `host` key was tapped |
| `0x03` | preset | `[preset]` — active preset changed (either side) |
| `0x04` | actions | `[page][totalPages][count]` + `count` × `[id lo][id hi][label 9, null-padded]` — one page of `ACTION_LIB`, in reply to `0x8C` |

**Commands (host → device):**

| Op | Name | Payload | Effect |
|----|---|---|---|
| `0x81` | setLabel  | `[preset][key][utf8 ≤8]` | Live label override (RAM only; persists only if the user saves on-device) |
| `0x82` | setStatus | `[utf8 ≤23]` | Status-bar line on the main grid; empty clears |
| `0x83` | setPreset | `[preset]` | Foreground-follow: switch the pad's preset; echoed back as event `0x03` |
| `0x84` | setFace | `[mode 0-2][persona 0-3]` | Face mode / personality override (RAM only). **Mode 0 also leaves the face screen immediately** — see below |
| `0x8B` | setVolume | `[level 0-100 \| 0xFF unknown][flags: bit0 muted]` | True system volume, relayed to the encoder puck. BLE HID volume is relative, so this is the only way the pad can know the real level |
| `0x8C` | getActions | `[page]` | Ask for one page of the builtin action library; answered with event `0x04` |
| `0x8D` | setMood | `[valence i8 ±100][arousal i8 ±100][weight 0-100][ttl s][flags]` | Face v2: the companion's mood opinion. The pad blends toward it by `weight` over its own mood (typing rate, link health) and eases back to autonomous when `ttl` lapses; weight 0 releases at once. Flags: bit0 late-night (more yawns), bit1 focused (fewer glances, more squints). RAM only |
| `0x8E` | setBeat | `[bpm×10 lo][hi][ms since last beat lo][hi][confidence 0-100]` | Face v2: tempo + phase for the pad's own beat clock (nod on the beat, sway over two). Sent on drift, never per beat. bpm outside 40-240 or no update for 8 s → back to the free-running bob |
| `0x8F` | *(retired)* | — | Face v2 feature bits. Face v3 has one look and ignores it |
| `0x90` | enterConfig | `['C']['F']` | Enter WiFi config mode (BLE drops, `MacroPad-Setup` hotspot up) so the companion's *Update firmware…* can OTA unattended. The two magic bytes stop a stray write from knocking the pad off Bluetooth |
| `0x91` | playEmote | `[emote id][intensity 0-100][hold ×100 ms, 0 = default]` | Face v3: play an emote now (host-side events: music drop, app context, late night; the editor's ▶ buttons). Intensity scales its motion |
| `0x92` | setEmoteMap | `[persist][n]` + n × `[trigger][emote \| 0xFF][chance %][cooldown s]` | Face v3: the pad-side trigger table. ≤ 6 entries per write (the command queue caps a payload at 26 bytes); send `persist=1` only on the last chunk, which writes NVS `emap` |
| `0x93` | setDance | `[level 0-100][flair every N bars, 0 = never][persist]` | Face v3: dance level and flair spacing. `persist=1` writes NVS `dlvl` / `dflr`; the editor's sliders send `persist=0` while dragging |

### Builtin actions over the host link

`setKey` (`0x86`) with `kaType = 0` (`KA_BUILTIN`) **reuses the consumer field as
the action id** — that is how the companion binds a key to one of the pad's own
actions.

The id list is not duplicated in the companion. It is pulled from the firmware's
`ACTION_LIB` with `getActions`, 8 entries per page, because an 86-entry copy in C#
would drift the moment an action is added to the sketch and the failure mode is a
key silently bound to the wrong action.

Notes: commands are queued in the firmware and applied by the display-owning
loop (bursts of 12 `setLabel`s are fine). `setPreset`/`setLabel` deliberately
do **not** write NVS — the companion pushes state every session, and flash
wear matters. Old alternative for scripts without BLE access: bind a
distinctive `key` chord and use a global-hotkey listener.

### Building on the host link

The **rewrite menu** ([`REWRITE_MENU.md`](REWRITE_MENU.md)) is worth reading as a
worked example: it turns a preset into a transient menu using nothing but the
opcodes above — `setKey` without `commit` to claim the keys in RAM, `setLabel` to
switch the menu between stages, `setFace` 0 to make the grid visible, and `0x02`
key events to drive the state machine. No firmware changes were needed to build
it beyond the `setFace` behaviour documented above.

## Build options for OTA `.bin`

The firmware **must** be compiled with these or OTA images won't match the
partition layout / boot:

```
Board:            ESP32 Dev Module   (esp32:esp32:esp32)
Partition Scheme: CUSTOM — firmware/v5/macropad_v5/partitions.csv is picked up
                  automatically by the esp32 core (dual 1.5MB OTA slots +
                  896KB SPIFFS for GIF animations). The menu setting is
                  ignored when that file is present.
Flash Frequency:  40MHz    (this bench board's Boya flash needs it)
Upload Speed:     115200   (USB flashing only; OTA ignores this)
```

> ⚠️ The switch TO this custom table had to be done once over USB — OTA can
> never change the partition table. After that one flash, OTA works normally
> and images must fit the 1.5MB slot.

arduino-cli one-liner (produces `build/.../macropad_v5.ino.bin`):
```
arduino-cli compile \
  --fqbn "esp32:esp32:esp32:FlashFreq=40,PartitionScheme=min_spiffs" \
  --output-dir build firmware/v5/macropad_v5
```
Upload that `.bin` via `POST /api/update`.

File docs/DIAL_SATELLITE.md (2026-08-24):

# Dial Satellite — Design Spec & Link Protocol

Wireless rotary-dial satellite for the MacroPad, linked over ESP-NOW.

- **Status:** design frozen for v1; firmware not yet written.
- **Date:** 2026-07-27
- **Scope of v1:** bare ESP-12E (ESP8266) + AS5600 magnetic encoder, one-way
  link to the pad, volume by default, mode changed from a pad key.
- **Deliberately deferred:** OLED, on-satellite buttons, potentiometer slider,
  battery power.
- **Dropped, not deferred:** microphone — not achievable on the ESP8266. It
  returns only if the satellite moves to the ESP32-S3 (§9).

This document is the stable contract. The slider and mic are expected later and
the packet format is versioned and type-tagged so they can be added without
changing the pad's receive path.

---

## 1. Why a satellite at all

The pad is a 4×3 matrix with no rotary input. A dial is the natural control for
continuous quantities (volume, zoom) that keys handle badly. Putting it on a
separate board rather than on the pad is a deliberate repeat of the decision
already made for the AS5600 puck: different duty cycle, independent failure
domain, and it can sit somewhere on the desk that the pad does not.

## 2. Architecture

```
┌────────────────────────────┐          ┌──────────────────────────────┐
│  Satellite (ESP-12E/8266)  │          │  MacroPad (ESP32 WROOM-32)   │
│                            │  ESP-NOW │                              │
│  AS5600 ──I2C──> tick      │ ───────> │  RX callback → mailbox       │
│           accumulator      │  ch 1    │            ↓                 │
│           ≤40 Hz send slot │  bcast   │  loop(): dialTick()          │
│                            │          │            ↓                 │
│  (no display, no buttons)  │          │  handleDialTicks(delta)      │
└────────────────────────────┘          │            ↓                 │
                                        │  sendConsumer() / sendKey()  │
                                        │            ↓ BLE HID         │
                                        └──────────────────────────────┘
                                                     ↓
                                                    Host
```

The satellite is a dumb sensor. It holds no mode, no configuration, and nothing
worth persisting. **All interpretation lives on the pad.** This is what allows
the dial's behaviour to be changed from a pad key without any back-channel, and
it is why v1 needs no pad→satellite path at all.

### Why one-way

A pad→satellite channel would only be needed to drive a display on the
satellite. v1 has no display, so the link is strictly one-way. Adding the
reverse direction later is additive: it does not invalidate anything here.

## 3. Hardware

### 3.1 Satellite — bare ESP-12E (ESP8266)

**ESP-12E module** + AS5600 (Robu 23×23 mm breakout). USB-powered for the
prototype; battery is out of scope for v1 and must not gate the link working.

The ESP-12E was chosen over the ESP32-S3 SuperMini on cost, and it is the
module the original `CONTEXT.md` puck plan already specified. The trade is
explicit and accepted: **the ESP8266 has one ADC (A0, 0–1 V) and no practical
microphone path.** A slider remains possible on A0 with a divider; a mic does
not. If the mic becomes a real requirement the satellite moves to the S3 — see
§9, where that swap costs one sketch and nothing else.

**Bare module, not a dev kit.** There is no USB, no regulator and no
auto-reset circuit on board; a programming jig has to be built. The module is
also **2 mm pitch**, so it needs an ESP-12 adapter PCB or hand-soldered wires —
it will not sit in a breadboard. Jig wiring, flash procedure and IDE settings
are in `firmware/tests/esp12e_bringup.ino`, which is the first thing flashed.

**Boot-pin biasing (from `CONTEXT.md` §2, unchanged):** EN, RST, GPIO0 and
GPIO2 pulled **up** through 10 kΩ; GPIO15 pulled **down** through 10 kΩ.
**Confirmed unusable:** GPIO9, GPIO10, and the flash-bus SCLK pin.

**Pin map (proposed, pending bench confirmation):**

| AS5600 pin | ESP-12E | Notes |
|---|---|---|
| VCC | 3V3 | **Not 5V.** AS5600 is a 3.3 V part. |
| GND | GND | |
| SDA | **GPIO 4** | `Wire.begin(4, 5)` — software I2C on the ESP8266. |
| SCL | **GPIO 5** | |
| DIR | GND | Fixes rotation polarity. Floating ⇒ direction undefined. |
| OUT | — | Unconnected; the analog/PWM output is unused. |

GPIO 4 and 5 are the conventional ESP8266 I2C pair, have no boot-strapping
role, and are the only two free pins that are unambiguously safe. This is a
deliberate deviation from `CONTEXT.md`, which put the AS5600 on GPIO 12/13 and
reserved 4/5 for the puck's two buttons — v1 has no buttons, so the safer pins
are now free and are used instead. GPIO 12/13/14 remain available if bench
testing gives a reason to move.

I2C on the ESP8266 is bit-banged in software rather than a hardware peripheral.
It is entirely adequate for polling one AS5600, but it is not free: the poll
loop in §4.4 competes with the WiFi stack for CPU, which is a reason to keep
the poll rate modest and let §7.1 confirm it rather than assume.

If the breakout has no onboard I2C pull-ups, add 4.7 kΩ (or the 10 kΩ parts
already on hand) from SDA and SCL to 3V3.

**Power.** Do not run the module from a USB-TTL adapter's 3.3 V pin — those
supply 50–100 mA against an ESP8266 that spikes to 300–500 mA on radio TX. Use
an AMS1117-3.3 off the adapter's 5 V rail, with 10 µF + 100 nF decoupling close
to the module. Brownout presents as random resets and corrupt serial, which is
easily mistaken for a firmware bug; `esp12e_bringup.ino` prints the reset reason
specifically so this gets diagnosed correctly.

**Magnet:** diametrically magnetised, 0.5–3 mm above the AS5600 die, centred on
it. The AS5600 `STATUS` register (0x0B) reports MD/ML/MH — magnet detected, too
weak, too strong. Bench validation must read it rather than assume placement.

Per the project's hardware-first workflow this pin map is **proposed, not
locked**. It is confirmed by the bench step in §7.1 before any link firmware is
written.

### 3.2 Pad

No hardware change. The existing ESP32 WROOM-32 gains a WiFi/ESP-NOW radio path
alongside NimBLE — see §6 for why that is the main risk and how it is bounded.

## 4. Link protocol

### 4.1 Radio configuration

Both ends run `WiFi.mode(WIFI_STA)` with no AP association, on a channel fixed
to **1**. ESP-NOW peers must agree on channel; pinning it removes a whole class
of intermittent-link bugs.

**The two ends use different APIs — this link is cross-family.** The satellite
is an ESP8266 and the pad is an ESP32, so the ESP-NOW setup is not symmetric:

| | Satellite (ESP8266 / ESP-12E) | Pad (ESP32 WROOM-32) |
|---|---|---|
| Header | `espnow.h` (ESP8266 core) | `esp_now.h` (ESP-IDF) |
| Channel | `wifi_set_channel(1)` | `esp_wifi_set_channel(1, WIFI_SECOND_CHAN_NONE)` |
| Role | `esp_now_set_self_role(ESP_NOW_ROLE_CONTROLLER)` | no role call needed |
| Peer | `esp_now_add_peer(mac, ESP_NOW_ROLE_SLAVE, 1, NULL, 0)` | `esp_now_peer_info_t` |
| Callback | `esp_now_register_recv_cb` — not used, TX only | `esp_now_register_recv_cb` |

Cross-family ESP-NOW is supported and works, but it is fussier than
ESP32↔ESP32, and the ESP8266's explicit **role** concept is the usual thing
that gets missed — a controller that never had its self-role set transmits
nothing, silently. Channel disagreement is the second. §7.1 step 3 exists to
prove this link before anything is built on it.

The 12-byte `SatPacket` in §4.3 is well within the ESP-NOW payload limit on
both families, so the packet format itself carries no interop risk.

### 4.2 Addressing — broadcast, not paired MAC

The satellite transmits to the broadcast address `FF:FF:FF:FF:FF:FF`. The pad
accepts any packet whose `magic` and `ver` fields match and ignores everything
else.

This is chosen over hardcoding the pad's MAC because there is no display and no
button on the satellite, so there is no way to run a pairing UI on it, and
hardcoding would require reflashing the satellite whenever the pad changes.
The cost is that the link is unauthenticated and unencrypted — ESP-NOW cannot
encrypt broadcast traffic. For a personal desk peripheral carrying volume ticks
this is an acceptable trade; it is recorded here so the decision is not
mistaken for an oversight. If it ever matters, the upgrade path is a shared
4-byte link ID stored in NVS on both ends, not a change to the packet layout.

### 4.3 Packet format

Fixed 12 bytes, little-endian, ESP-NOW payload. Version 1.

```c
// Sent satellite → pad. Never sent in the other direction in v1.
typedef struct __attribute__((packed)) {
  uint32_t magic;    // 0x3153504D  ('MPS1' LE) — link filter
  uint8_t  ver;      // protocol version; 1
  uint8_t  type;     // SAT_DIAL = 0x01
  uint8_t  seq;      // rolling 0..255, increments per packet
  uint8_t  flags;    // bit0 reserved (low battery), bit1 = first packet since boot
  int16_t  delta;    // signed detent ticks accumulated since last packet
  uint16_t value;    // 0 for SAT_DIAL; absolute value for future sensors
} SatPacket;         // sizeof == 12
```

**Type codes.** `0x01` dial. Reserved for later: `0x02` slider (uses `value` as
absolute 0–1000, `delta` unused), `0x03` mic control events. Codes the pad does
not recognise are dropped silently — that is what makes adding the slider a
satellite-only change.

**`seq`** lets the pad drop duplicates. ESP-NOW does not retransmit at this
layer, but a repeated `seq` with identical contents indicates a duplicate and is
discarded; a gap simply means a lost packet and is not corrected. Losing a
packet costs a few ticks of dial movement, which is not worth retransmitting.

**`flags` bit1** marks the first packet after the satellite boots, so the pad can
reset link state and show a toast rather than treating a large first `delta` as
real movement.

### 4.4 Transmit policy — the rate cap

This is the single most important behavioural rule in the design, for the reason
in §6.

- The satellite polls the AS5600 at ~200 Hz and accumulates detent ticks
  locally. Polling is local I2C traffic and costs the radio nothing.
- It transmits **at most once every 25 ms (≤40 packets/s)**, and only when the
  accumulated tick count is non-zero. The accumulator is zeroed on send.
- **Spinning the dial faster increases `delta`, never the packet rate.** This is
  the property that keeps the link away from the failure mode recorded in
  `ROADMAP.md:79`.
- An idle dial transmits **nothing at all** — no keepalive, no heartbeat.

### 4.5 Tick derivation

The AS5600 reports a 12-bit absolute angle (0–4095) from register 0x0E/0x0F. The
satellite tracks the previous raw angle, computes the shortest-path signed
difference (handling the 4095→0 wrap), accumulates it, and emits one detent tick
per `TICK_THRESHOLD` raw counts. Threshold and any acceleration curve are
satellite-side tuning constants, established on the bench in §7.1 — the pad must
work correctly for any `delta` it receives and must not encode assumptions about
the dial's physical resolution.

## 5. Pad-side integration

### 5.1 Dial modes

```
DIAL_VOL     (default)  ticks → consumer VOLUME_UP / VOLUME_DOWN
DIAL_ZOOM               ticks → Ctrl +  /  Ctrl −      (OS-layout aware)
DIAL_ALTTAB             ticks → Alt+Tab / Alt+Shift+Tab
```

**SCROLL is deliberately absent from v1.** The pad's HID report map is keyboard
(Report ID 1) + consumer control (Report ID 2) only — there is no mouse report,
so there is no wheel to drive. Adding one changes the HID report descriptor,
which risks invalidating existing bonds across all three host slots. That is a
larger change than this feature justifies and is tracked separately.

`dialMode` is a single global, persisted to NVS through the existing
`saveSettings()` path. It is not per-preset: the user asked for volume by
default with the mode changed explicitly, and a global mode means the dial does
not silently change meaning when a preset switches.

### 5.2 Changing the mode

A new entry in `ACTION_LIB`:

```c
{"Dial Mod", A_DIAL_MODE},
```

Tapping a key bound to it cycles VOL → ZOOM → ALT-TAB → VOL and shows a toast
naming the new mode.

This reuses the existing per-preset key assignment, BUILD MODE, and companion
`HCMD_KEY` machinery wholesale. **No new settings screen, no new UI state, no
new persistence path.** The user binds it to whichever key in whichever presets
they want.

### 5.3 Receive path and task safety

The ESP-NOW receive callback runs in the WiFi task. The project's existing rule
— established for `pendingBleEvent` and the `hostCmdQ` mailbox — is that only
the loop task touches the TFT. The dial path follows it exactly:

1. `onEspNowRecv()` validates `magic`/`ver`/`type`/`seq`, adds `delta` into a
   `volatile int16_t` accumulator, stamps `lastDialPacketMs`, and returns. It
   draws nothing and calls no BLE function.
2. `dialTick()`, called from `loop()`, drains the accumulator and calls
   `handleDialTicks(delta)`.
3. `handleDialTicks()` emits HID via the existing `sendConsumer()` / `sendKey()`
   and calls `recordActivity()` so the dial defers the sleep timer.

Output is rate-limited on the pad as well: a large `delta` is emitted as a
bounded burst rather than an unbounded loop, so one lost second of packets
cannot stall the loop task or flood the host.

### 5.4 Link state

`lastDialPacketMs` drives a small indicator in the existing status bar. No
packet for 5 s ⇒ shown as idle. This is presence, not health: an idle dial is
indistinguishable from an absent one by design, since §4.4 forbids keepalives.

### 5.5 Settings toggle

Settings gains **Dial link ON/OFF**, persisted, default ON. Turning it off calls
`esp_now_deinit()` and `WiFi.mode(WIFI_OFF)`, fully releasing the radio and its
RAM.

Note the deliberate difference from v4, which defaulted ESP-NOW **off**
(`TESTING_LOG.md:40`). Here the rate cap in §4.4 is the primary mitigation, so
the link is expected to be safe to leave on; the toggle exists as a one-tap
recovery for a user hitting instability, not as the mitigation itself. If §7.1
step 4 shows BLE disconnects with the cap in place, the default flips to OFF and
the rate cap has failed as a strategy.

## 6. The coexistence risk

The pad's ESP32 has one 2.4 GHz radio shared by BLE and WiFi. The project has
already been here and the evidence is on record:

- `docs/TESTING_LOG.md:39` — "BLE connection instability when WiFi (ESP-NOW)
  active simultaneously." Mitigated in v4 by defaulting ESP-NOW off.
- `docs/ROADMAP.md:79` — "Coexist but cause connection instability **at high
  packet rates**."
- `docs/CONFIG_API.md:11` — Config Mode tears BLE down entirely before starting
  WiFi, because "WiFi and BLE don't coexist well on the WROOM-32."

Two things follow.

**The failure mode is rate, not coexistence per se.** v4's sender transmitted one
packet per tick, so a fast spin produced a burst at whatever rate the encoder
could generate. §4.4 caps the rate at 40 Hz independent of dial speed and sends
nothing when idle. That is the primary mitigation and the reason the transmit
policy is specified as a requirement rather than left to the implementation.

**Heap is the second constraint.** The WiFi stack costs roughly 40–50 KB on top
of NimBLE, and `macropad_v5.ino:845` already notes that a full 320×240 sprite is
"impossible with BLE active". Whether the remaining headroom absorbs WiFi is
unknown and cannot be settled by reading code.

**Therefore §7.1 step 2 is a hard gate.** No feature code is written until a
minimal spike shows the pad can hold a BLE HID connection with ESP-NOW
initialised, with the free-heap numbers recorded. If it fails, the fallback is
decided before any further work. The fallback is routing the satellite to the
**companion app** instead of the pad: the satellite joins WiFi and talks to the
Fedora companion, which drives volume over the existing host-link. This costs
the "works on any paired host" property and only functions where the companion
runs, which is why it is the fallback and not the design.

(An earlier draft named a second ESP8266 as a pad-side ESP-NOW→UART
co-processor. That option is now spent — the ESP-12E on hand is the satellite,
per §3.1.)

## 7. Validation plan

Every step below produces a dated entry in `docs/DIAL_SATELLITE_BUILDLOG.md`
with the actual serial output, not a summary.

### 7.1 Bench sequence

0. **ESP-12E bring-up.** Flash `firmware/tests/esp12e_bringup.ino` over the jig
   in §3.1. Pass = steady 1 Hz heartbeat, and a reset reason of "Power on" or
   "External System" — never WDT or Exception. **This proves the jig and the
   supply before any peripheral is attached**, so later faults can be blamed on
   the right thing. Record the printed STA MAC.
1. **AS5600 read on the ESP-12E.** Adapt `firmware/tests/AS5600_test.ino` to the
   ESP8266 and the §3.1 pin map. Pass = stable angle across a full rotation,
   `STATUS` reporting MD set with ML and MH clear. **This locks the pin map.**
2. **Coexistence gate.** Add `WiFi.mode(WIFI_STA)` + `esp_now_init()` to the
   live v5 firmware and nothing else. Record free heap before and after init.
   Pass = BLE HID still types reliably and heap headroom is sufficient. **No
   further work if this fails** — see §6.
3. **Link up.** Satellite transmits, pad logs `delta` to serial. Pass = ticks
   arrive with correct sign and no duplicates.
4. **Rate ceiling.** Spin the dial as fast as possible for 30 s. Pass =
   measured packet rate stays at or below 40 Hz and BLE stays connected.
5. **Volume end to end.** Pass = host volume tracks the dial with no runaway and
   no stuck keys.
6. **Mode cycling.** Bind `A_DIAL_MODE` to a key; verify all three modes and
   that the mode survives a reboot.
7. **Sleep interaction.** Confirm the documented behaviour in §8 — dial input
   while the pad sleeps is lost, and the pad wakes normally on a key press with
   the dial working immediately after.

### 7.2 Recorded measurements

The build log must carry actual numbers for: free heap before/after ESP-NOW
init, measured peak packet rate, dial-to-host latency, and BLE disconnect count
over a 30-minute soak with the dial in active use.

## 8. Known limitations of v1

These are accepted, not defects.

- **Dial input while the pad is asleep is lost.** Light sleep powers down the
  radio, so a tick cannot wake the pad. Press any key to wake; the dial works
  immediately after. Keeping WiFi alive through sleep would defeat the pad's
  power design.
- **No SCROLL mode** — see §5.1.
- **Link is unauthenticated** — see §4.2.
- **No battery telemetry.** `flags` bit0 is reserved for it; the satellite is
  USB-powered in v1.
- **Lost packets are not retransmitted** — see §4.3.

## 9. Extension path

Nothing here needs revisiting to add the deferred hardware:

- **Slider:** satellite sends `type = 0x02` with `value` = absolute 0–1000. The
  pad adds a handler; the packet layout, addressing and rate cap are unchanged.
  Absolute position has no HID equivalent, so a per-preset assignable slider
  will likely drive the companion app over the existing host-link GATT — a new
  `HEV_` opcode in `CONFIG_API.md`, not a change to this protocol.
- **OLED on the satellite:** requires a pad→satellite path, which is additive.
  The `SatPacket` layout is reusable in reverse with new type codes.
- **Microphone:** not achievable on the ESP8266 and therefore out of scope while
  the ESP-12E is the satellite. Control events would fit `type = 0x03`, but
  **audio streaming does not fit this protocol at all** — 12-byte control
  packets at 40 Hz and an audio stream are different problems. Do not attempt to
  extend this format for it.

- **Swapping the satellite to the ESP32-S3 SuperMini:** the intended path if the
  mic or a second analog input becomes real. Cost is **one sketch**: the pad,
  the packet format, the addressing and the rate cap are all unchanged, because
  §2 puts every decision on the pad and leaves the satellite a dumb sensor. The
  S3 changes are the pin map (`SDA GPIO 8 / SCL GPIO 7` — GPIO 9, the usual S3
  default for SCL, is outside the SuperMini's twelve boot/flash-free pins
  `IO1, IO2, IO4, IO5, IO6, IO7, IO8, IO15, IO16, IO17, IO18, IO21`), hardware
  rather than bit-banged I2C, and the ESP32 ESP-NOW API — which makes the link
  same-family and removes the §4.1 interop risk entirely.

## 10. Deliverables

| Document | Purpose |
|---|---|
| `docs/DIAL_SATELLITE.md` | This spec — frozen decisions and the link contract. |
| `docs/DIAL_SATELLITE_BUILDLOG.md` | Dated engineering log: every bench test, measurement, failure and fix, with real serial output. |
| `docs/DIAL_SATELLITE_BUILD.md` | User-facing build guide: BOM, wiring, flashing, first-run, troubleshooting. |
| §7 results in the build log | Bench validation record: pass/fail per subsystem with numbers. |

## 11. Decision log

| Decision | Rationale |
|---|---|
| Satellite is a dumb sensor; pad owns all interpretation | Lets a pad key change dial behaviour with no back-channel. |
| One-way link in v1 | Nothing on the satellite needs to display state. |
| Broadcast addressing | No display or button on the satellite, so no pairing UI is possible. |
| Rate cap as a spec requirement | v4's per-tick sending is the recorded cause of BLE instability. |
| Global `dialMode`, not per-preset | The dial should not silently change meaning on a preset switch. |
| `A_DIAL_MODE` as an `ACTION_LIB` entry | Reuses all existing assignment/persistence machinery; no new UI. |
| SCROLL deferred | Needs a mouse HID report, which risks existing bonds. |
| ESP-12E as the satellite, not the ESP32-S3 | Cost, and it is the module `CONTEXT.md` already planned for. Accepts losing the mic; §9 keeps the S3 swap to one sketch. |
| AS5600 on GPIO 4/5, not `CONTEXT.md`'s 12/13 | v1 has no buttons, so the conventional boot-free I2C pair is free and is the safer choice. |
| Coexistence spike as a hard gate | Prior bench evidence says this may not work; find out before building on it. |
| Bring-up sketch before any peripheral | A bare module with a hand-built jig fails at the supply far more often than at the code; prove power first so later faults are attributed correctly. |

## 12. History

- 2026-07-27 — spec written. Scope set to dial-only after OLED, slider,
  satellite buttons and mic were deferred out of v1. Rate cap promoted to a
  requirement on the strength of the v4 findings in `TESTING_LOG.md` and
  `ROADMAP.md`. Firmware not yet written.
- 2026-07-27 — **satellite changed from ESP32-S3 SuperMini to bare ESP-12E** on
  cost. Consequences: mic dropped from the roadmap entirely (§9), pin map moved
  to GPIO 4/5 with software I2C (§3.1), a programming jig and bring-up step
  added (§3.1, §7.1 step 0), and cross-family ESP-NOW promoted from a fallback
  caveat to the **primary link path** with an explicit API table (§4.1). The
  pad-side design in §5 is untouched by the swap — which is the intended
  property of §2.

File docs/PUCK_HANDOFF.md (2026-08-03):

# Encoder Puck — Handoff

**Date:** 2026-08-03 · **Branch:** `linux-companion` · **Head `8ce6627`, pushed, tree clean.**

Supersedes the 2026-08-01 handoff, which described the ESP-12 as the active puck,
the C3 as dead, and the AS5600 as never wired. All three are now wrong.

---

## Status in one line

**The puck is finished.** Printed, assembled, and working on hardware — dial,
magnet, sleep cycle, spin-to-reboot and OTA all verified. What remains is a
better power board and one cosmetic check.

---

## Hardware inventory

| Thing | Identity | State |
|---|---|---|
| MacroPad v5 | STA `84:1F:E8:2B:33:48` · BLE `…:4A` · AP `…:49` | Working, current firmware |
| **ESP32-C3 puck** | MAC `88:56:A6:2B:ED:7C`, COM8 | **Active**, in the printed body |
| ESP-12E puck | MAC `E8:68:E7:81:9B:07`, COM15 | Spare. Protocol-synced, no OTA support |
| AS5600 | addr `0x36` | **Wired and working** |
| OLED | SSD1306 128×32 | **Dropped from the design** (`PUCK_OLED 0`) |

### The C3 is not dead

It was written off on 2026-07-31 after a lost decoupling cap left an apparent
0 Ω short on 3V3. That verdict was wrong, or the fault cleared: it enumerated,
flashed, and has been the working puck ever since. Ignore any older note saying
otherwise — including the ESP-12 power-board blocker, which is moot.

---

## Verified on hardware

- **Protocol v3 both directions** — mode switching, and the full volume path
  (Core Audio → companion → GATT → pad → ESP-NOW → puck) tracking in 2% steps
- **Rotation** — the AS5600 drives the whole chain; `PUCK_DIR_INVERT 0` is correct
- **Light sleep genuinely enters** — the C3 fully detaches from USB when no
  monitor is attached, which is the tell
- **Wake on movement** — the pad reads `LINKED` after a turn
- **Spin-to-reboot** and the **sleep cycle** behave on the real device
- **The puck OTA round trip** (2026-08-03), after four separate bugs — below
- **The printed enclosure** — the `(3)` STL set fits: the dial spins freely with
  no wobble, both counterpart halves mate, and the stack matches 24 mm. **The
  AS5600 magnet pocket worked first time**, despite being flagged throughout as
  the fussy dimension

## Not yet verified

- **The face-screen mode label** on the pad — flashed, never eyeballed
- **Any battery figure.** Every runtime number here is modelled, not measured.
  A meter in series with the cell is the only way to settle it, and it cannot be
  done over USB: an attached host suppresses CPU sleep by design

---

## Protocol v3

`docs/PUCK_PROTOCOL.md` is the source of truth. 9-byte struct, duplicated in
three sketches (Arduino folders cannot share a header), all marked `KEEP IN SYNC`.
**Not wire-compatible with v2** — the length check drops short packets before the
version check runs, so a mismatch is total silence with no error at either end.

The pad owns everything stateful: mode, and dial feel. The puck holds no
persistent copy — it boots on compiled defaults and adopts the pad's values on
the first `PK_STATE`.

**Sensitivity** rides as *detents per revolution*, not a raw threshold. Windows
moves volume 2% per `CONSUMER_VOL_UP`, so **50 ticks is the entire range** — which
makes the default of 50/turn "one turn, one sweep", and is the sanity check for
any retuning. `Settings → PUCK` has its own screen with live-pushing SPEED and
ACCEL sliders.

---

## Sleep architecture

Two states in `puck_encoder.ino`:

- **ACTIVE** — radio up, 10 ms encoder polling, 40 ms send coalescing
- **DOZE** — WiFi driver stopped, CPU light-sleeping in 50 ms slices, waking to
  poll the AS5600 over I2C. One full detent promotes back to ACTIVE

An unassociated STA cannot use WiFi modem sleep (no AP beacon to sync against),
so stopping the driver outright is the only way to put the radio down.

The AS5600 drops to **LPM2** while dozing (6.5 mA → 1.8 mA). Its 20 ms internal
polling is still faster than our 50 ms wake, so nothing is lost. `CONF` is
read-modify-written — that register also holds hysteresis and filtering.

`sleepGraceMs` is 30 s after a power-on reset so a serial monitor can attach, and
**0 after a software reset** — a watchdog reboot that then sat awake 30 s would
burn ~1 mAh each time.

### Recovery layers

| Trigger | Response |
|---|---|
| 5 min unlinked | `rebuildEspNow()` — full deinit/stop/start/init/re-peer |
| 30 min unlinked | `ESP.restart()` |
| 1 h unlinked | Deep sleep; spin ~10 s to wake |
| **Spin 2–3 turns while unlinked** | **Immediate reboot** |
| OTA with no upload for 5 min | Restart back into normal ESP-NOW |

**Spin-to-reboot exists because the puck is sealed in a printed body with no
reachable reset** — a hard spin *is* the reset button. Gated strictly on being
unlinked (30 s quiet), because spinning hard is completely ordinary during normal
volume use; that gate is the only thing making it safe.

Deep sleep wakes on a 3 s timer and needs `WAKE_MOVES_NEEDED` (3) consecutive
samples of ≥200 counts (~18°) before booting for real, so a knock or thermal
drift cannot wake it. **The AS5600 has no movement interrupt** — it is a plain
I2C angle sensor — which is why waking on rotation must be timer-poll-and-look.

---

## Power

**Current wiring is a stopgap:** the cell feeds the SuperMini's `5V` pin and its
onboard ME6211-class LDO makes 3V3. The CKCS boost module does charging only.

That change exists because the original chain — LiPo → 5 V boost → AMS1117 — had
two faults:

1. **~57% efficiency.** Boost at ~85%, then a linear regulator at 3.3/5 = 66%.
   Nearly half the pack became heat.
2. **Minimum-load shutdown.** Power-bank boost modules cut output below ~40–70 mA.
   A dozing puck draws single-digit mA, so the module decided nothing was plugged
   in and shut down. **There is no firmware recovery** — with the output off the
   C3 has no power at all, so it cannot pulse the module's button pad or signal
   anything. The interim workaround was a keepalive load pulse (10 s, then 5 s);
   the rewire removed the need and `DOZE_HELLO_MS` is back to 60 s.

⚠ **Two hazards of the direct tap.** Do not leave USB connected with the battery
on the `5V` pin — it ties to VBUS with no isolation on most SuperMini boards; fit
a Schottky (BAT54/1N5819) in the battery lead or unplug the cell to flash. And
confirm the LiPo has its own protection PCB, since tapping B+ may bypass whatever
the CKCS board provided. The C3's brownout detector (~2.98 V) is a crude backstop,
not protection.

### Planned board

One small PCB: **TP4056 (+DW01A/FS8205A protection) + SL7333 or AP2112K 3V3**,
removing the power-bank module entirely.

- `Rprog` 4 kΩ → 300 mA charge (0.5C on a 600 mAh cell)
- **1000 µF low-ESR** on the LDO output — the C3's TX peaks exceed a 250–300 mA
  LDO's rating and the cap rides them out
- **Verify the SOT-23-3 pinout against the vendor datasheet.** Three-pin LDO
  pinouts are not consistent between manufacturers
- **Run the AS5600's VCC from a GPIO.** It draws 6.5 mA, which the C3 sources
  easily, and it is what stops deep sleep being worthwhile today

TX power is capped at 11 dBm (`PUCK_TX_POWER_QDBM 44`) to keep peaks under the
LDO rating. **It resets on every `esp_wifi_start()`**, so it is re-applied in
`setupEspNow()`, `radioOn()` and `rebuildEspNow()`.

### Runtime model

Calibrated against the one real measurement — the original always-on build died
in 3 h on 600 mAh, which the model reproduces at ~200 mA.

| Configuration | Idle | Runtime |
|---|---|---|
| Always-on radio | ~200 mA | 3 h (measured) |
| + sleep firmware | ~39 mA | ~15 h |
| + BMS LEDs killed | ~15 mA | ~37 h |
| + battery-direct (current wiring) | ~2 mA | days |

⚠ **Deep sleep is barely a power win as wired.** C3 deep sleep is ~5 µA, but the
AS5600 still draws ~1.5 mA in LPM3 — the sensor dominates and the CPU being off
hardly registers. Its value today is behavioural. GPIO-powering the AS5600 is
what would turn it into a real saving.

---

## Gotchas that will recur

**A dozing C3 cannot be auto-flashed.** Light sleep powers down USB Serial/JTAG.
Windows keeps the cached descriptor so the port still *appears* and reports
Status OK, but opening it fails with *"A device attached to the system is not
functioning"* and esptool's DTR/RTS reset never lands. **Recovery: unplug, hold
BOOT, plug in, release.** A reset alone is often not enough — the physical
disconnect is what clears the stale device node. Set `PUCK_SLEEP 0` for bench
work if this gets tiresome.

**`RTC_DATA_ATTR` does not survive a software reset** — only deep sleep. The
bootloader reinitialises `.rtc.data` from flash. Use `RTC_NOINIT_ATTR`, and only
trust it when the reset reason is `ESP_RST_SW` or `ESP_RST_DEEPSLEEP`; it is
garbage after a power cycle.

**Never mix raw `esp_wifi_*` with the Arduino `WiFi` wrapper.** The doze cycle
uses `esp_wifi_stop()`/`esp_wifi_start()`; `WiFi.softAP()` goes through
`WiFiGeneric`, which tracks its own idea of whether the driver is started.
Changing that behind its back makes `softAP()` **silently no-op** — ESP-NOW tears
down but no AP appears. OTA reboots into AP mode via an RTC flag so the stack is
cold and coherent.

**`RADIO_LISTEN_MS` must outlast the pad's turnaround.** At 80 ms the pad's reply
routinely arrived after the radio was already down, silently dropping *every*
`PK_STATE` — mode, speed, accel and the OTA request with it. Now 400 ms with an
early exit the moment a reply lands. **If pad→puck settings ever appear to be
ignored, check this first.**

**`PUCK_OTA_PEND_MS` must outlast the puck's keepalive.** A dozing puck is quiet
by design, so "the puck went silent, therefore it acted on the request" is a
false inference — it dropped the latch ~10 s after the keypress, long before the
puck woke. Expiry is time-based only.

**The puck cannot wake a sleeping pad.** `esp_light_sleep_start()` powers down
WiFi on the pad too; packets during its sleep are lost.

**Pad STA MAC ≠ BLE address.** The puck targets `84:1F:E8:2B:33:48`, not the
`…:4A` the companion uses. Wrong one fails completely silently.

**Debug vs Release trap.** A running MacroPadDeck locks its Debug exe, so
`dotnet build` fails MSB3027 and only `-c Release` succeeds; relaunching Debug
then runs stale code and new features look missing.

### The OTA saga — four attempts, four different causes

All fixed, recorded because each presented identically ("no `Puck-Setup` AP"):

1. `RADIO_LISTEN_MS` 80 ms — pad→puck replies dropped wholesale
2. `WiFi.softAP()` silently no-opping from wrapper state desync
3. `RTC_DATA_ATTR` not surviving a software reset, which combined with the pad
   re-asserting its latch produced an **infinite reboot loop**
4. The pad clearing its latch ~10 s in, before a dozing puck could hear it

**Pull the puck's serial log first next time.** It identified causes 2, 3 and 4
within seconds each; re-triggering blind cost a round. The `[PAD]` diagnostic now
prints `ota=` so "did the flag arrive" is a glance, not a round trip.

---

## Build & flash

```bash
arduino-cli compile --fqbn "esp32:esp32:esp32c3:CDCOnBoot=cdc" --libraries C:/Users/gsaip/Documents/Arduino/libraries --output-dir build_puck_c3 firmware/v5/puck_encoder
```

```bash
arduino-cli upload -p COM8 --fqbn "esp32:esp32:esp32c3:CDCOnBoot=cdc" --input-dir build_puck_c3 firmware/v5/puck_encoder
```

```bash
arduino-cli compile --fqbn "esp32:esp32:esp32:FlashFreq=40,UploadSpeed=115200,PartitionScheme=min_spiffs" --libraries C:/Users/gsaip/Documents/Arduino/libraries --output-dir build firmware/v5/macropad_v5
```

Pad OTA: `Settings → CONFIG`, join `MacroPad-Setup` / `macropad123`, then

```bash
curl -s -F "f=@build/macropad_v5.ino.bin;filename=firmware.bin" http://192.168.4.1/api/update
```

Puck OTA: `Settings → PUCK → OTA` on the pad, join `Puck-Setup` / `puck12345`,
then POST the puck binary to `192.168.4.1/api/update`. A dozing puck can take up
to `DOZE_HELLO_MS` to notice. **The AP disappearing is the success signal**, for
both devices.

**Always flash the C3 with `CDCOnBoot=cdc`** — the core defaults to routing
`Serial` to UART0, and the board then runs perfectly while printing nothing.

⚠ Joining `MacroPad-Setup` disconnects Windows from the real network, and it does
**not** auto-reconnect after the pad reboots. Restore with
`netsh wlan connect name="AirFiber-SvnePP"`.

Sizes: puck 79% flash / 11% RAM · pad 69% / 28%.

---

## CAD

`cad/stl/puck/` — revision `(3)`, pushed 2026-08-03, printed and fitted.

| File | Size | Role |
|---|---|---|
| `puck_dial.stl` | 50 × 50 × 12 mm | the knob |
| `puck_dial_counterpart_1.stl` | 73 × 55 × 17 mm | housing body |
| `puck_dial_counterpart_2.stl` | 73 × 55 × 7 mm | housing lid |

The counterparts share a footprint and stack to 24 mm with the dial seating into
them. Binary STL headers are all-zero, so no CAD metadata travels with the files —
**check export timestamps rather than trusting a folder suffix** when a new
revision arrives.

---

## Next steps

1. **Measure the battery** with a meter in series. Every number above is modelled.
2. **Build the power board** — TP4056 + LDO, and put the AS5600 on a GPIO so deep
   sleep is worth having.
3. **Eyeball the face-screen mode label** — the last unexercised feature.
4. Optional: **high-res scrolling**. Answered but not built — needs the HID
   Resolution Multiplier (usage `0x48`) in a logical collection plus a Feature
   report, since the plain wheel field's unit *is* one detent. Costs a Bluetooth
   off/on per host to clear the GATT wedge from adding Report ID 3.

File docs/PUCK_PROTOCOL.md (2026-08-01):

# Encoder Puck — ESP-NOW Protocol

The puck is a standalone wireless knob: an **AS5600** magnetic encoder, a **128×64
SSD1306 OLED**, and a push button on an ESP32-C3/S3. It talks to the MacroPad v5 over
**ESP-NOW**; the pad translates puck input into BLE HID and sends it to whichever host
is currently active.

The pad is the only BLE endpoint. The puck never pairs with a computer.

```
  ┌──────────┐   ESP-NOW    ┌──────────────┐   BLE HID   ┌──────┐
  │  Puck    │ ───────────► │  MacroPad v5 │ ──────────► │ Host │
  │ AS5600   │ ◄─────────── │  (slot 1-3)  │             └──────┘
  │ + OLED   │   PK_STATE   └──────────────┘
  └──────────┘
```

## Wire format

One fixed 9-byte struct, used in both directions. **This table is the source of
truth** — the struct is duplicated in three sketches, because Arduino sketch folders
cannot share a header. All carry a `KEEP IN SYNC` marker:

| Sketch | Chip | Role |
|---|---|---|
| `firmware/v5/macropad_v5/macropad_v5.ino` | ESP32 WROOM-32 | pad (receiver) |
| `firmware/v5/puck_encoder/puck_encoder.ino` | ESP32-C3 / S3 | puck |
| `firmware/v5/puck_encoder_8266/puck_encoder_8266.ino` | ESP-12E / ESP8266 | puck |

The two puck sketches share the protocol and tuning. Only the radio API and pin
numbers differ — plus OTA, which is C3-only. **ESP-NOW interoperates between ESP8266
and ESP32 over the air**, so either puck talks to the same pad firmware.

```c
struct PuckMsg {
  uint8_t ver;    // PUCK_PROTO_VER — receiver drops anything else
  uint8_t type;   // PK_*
  uint8_t mode;   // PM_VOLUME / PM_SCROLL / PM_ZOOM
  int8_t  ticks;  // signed detents in this packet, + = clockwise
  uint8_t btn;    // BTN_NONE / BTN_SHORT / BTN_DOUBLE / BTN_LONG
  uint8_t flags;  // pad → puck only (see below)
  uint8_t vol;    // pad → puck only: 0-100, or 0xFF unknown
  uint8_t speed;  // pad → puck only: detents per revolution, 8-128
  uint8_t accel;  // pad → puck only: acceleration cap, 1 = off, max 8
};
```

`PUCK_PROTO_VER` is currently **3**. Bump it on any field change; both sides reject
mismatched versions rather than misparsing. **v3 is not compatible with v2** — the
struct grew, and the length check drops short packets before the version check ever
runs. Flash both devices together, or the link goes silent with no error anywhere.

v2 added `vol` and moved mode ownership from the puck to the pad.
v3 added `speed`/`accel` and `PK_OTA`, moving dial feel to the pad as well.

| Type | Name | Direction | Meaning |
|---|---|---|---|
| `0x01` | `PK_HELLO` | puck → pad | Sent on boot and every 5 s while idle. Registers the puck and keeps the link indicator alive. |
| `0x02` | `PK_INPUT` | puck → pad | Rotation and/or a button event. `ticks` and `btn` may both be set. |
| `0x03` | `PK_STATE` | pad → puck | Reply to any received packet. Carries `flags`, `vol`, `speed`, `accel`. |
| `0x04` | `PK_OTA` | pad → puck | Tear down ESP-NOW and raise the OTA access point. One-way — see below. |

### Sensitivity (`speed` / `accel`)

Both are owned by the pad, stored in its NVS (`pspd` / `pacc`), and pushed in every
`PK_STATE`. The puck holds no persistent copy: it boots on the compiled defaults and
adopts the pad's values on the first packet. One source of truth, same as mode.

`speed` is **detents per revolution**, not a raw threshold — that is the number a
human can reason about, and it keeps the AS5600's 4096-count resolution an
implementation detail of the puck. The puck derives `threshold = 4096 / speed`.

> **The sanity check that matters:** Windows moves volume **2% per
> `CONSUMER_VOL_UP`**, so **50 ticks is the entire 0→100% range**. That makes
> `speed = 50` "one full turn, one full sweep", and it is why the default is 50.
> Any tuning that puts far more than ~50 ticks in a comfortable revolution feels
> broken. Ticks per revolution is `speed × mult`, so `accel` multiplies this.

`accel` caps the velocity multiplier; `1` disables acceleration entirely. The
multiplier is `constrain(velocity × ACCEL_FACTOR, 1, accel)` with velocity in
counts/ms and `ACCEL_FACTOR = 1.0`, so it reads as "multiplier at 1 count/ms"
(≈90°/sec, a slow deliberate turn, = 1×).

⚠ There was once an extra `× 80.0f` in that expression. It pinned the multiplier at
the cap for **every** human-speed turn — reaching 1× needed a turn slower than
0.55°/sec — and combined with a 20-count threshold it swept the whole volume range
in about 11° of rotation. If the dial ever feels violently oversensitive again, that
expression is the first place to look.

### OTA (`PK_OTA`) — ESP32-C3 only

Sent from `Settings → PUCK → OTA` on the pad. On receipt the puck deinits ESP-NOW,
raises a SoftAP `Puck-Setup` / `puck12345`, and serves an upload page plus
`POST /api/update` at `192.168.4.1`.

**This is a one-way door.** ESP-NOW runs as an unassociated STA pinned to channel 1
and an AP will not come up cleanly underneath it, so the radio is torn down for good;
the only way back to normal operation is the reboot after flashing, or a power cycle.
The pad therefore refuses to send it unless the puck is currently linked, and sends
it three times, because a lost packet here is invisible — the user just sees no AP.

As with the pad's own OTA, **the access point disappearing is the success signal.**

The ESP-12 build has no OTA (no native USB, and the pad's trigger would strand it);
it logs a line to serial and carries on. Flash that board over USB.

### `flags` (pad → puck)

| Bit | Meaning |
|-----|---|
| 0 | Pad's BLE link is up — input will actually reach a host |
| 1 | Pad was built with mouse HID, so `PM_SCROLL` is supported |
| 2 | Pad has the puck **disabled** in Settings (input is being discarded) |
| 3 | `vol` is a real level (the companion app is feeding it) |
| 4 | System is muted |

The puck renders these on the OLED, so a dead knob explains itself instead of just
doing nothing.

## Modes

The knob is modal; a long button press cycles the mode. Which modes actually work
depends on the pad's HID descriptor:

| Mode | Rotation sends | HID used | Works today? |
|---|---|---|---|
| `PM_VOLUME` (0) | Volume up/down | Consumer (Report ID 2) | **Yes** |
| `PM_ZOOM` (2) | `Ctrl` + `+` / `Ctrl` + `-` | Keyboard (Report ID 1) | **Yes** |
| `PM_SCROLL` (1) | Mouse wheel | Mouse (Report ID 3) | **Only if `PUCK_MOUSE_HID 1`** |

Volume and zoom need **no change to the pad's HID descriptor** — they reuse the
keyboard and consumer reports the pad already advertises.

Scroll needs a third HID report. Adding it changes the GATT database, and on Windows
that reliably wedges service discovery with `0x8000FFFF` until you toggle Bluetooth
off and on (see `HARDWARE_HANDOFF.md`). So it is compiled out by default:

```c
#define PUCK_MOUSE_HID 0   // 1 = add Report ID 3 and enable PM_SCROLL
```

With the flag at 0, the pad reports scroll as unsupported via `flags` bit 1 and the
puck skips `PM_SCROLL` when cycling modes, so the knob never lands in a dead mode.

## Mode ownership — the pad decides

**The pad owns the dial mode.** The puck renders whatever arrives in `PK_STATE` and
never changes mode on its own; `m->mode` on a puck→pad packet is deliberately
ignored. This exists so a pad key and the puck's (optional) button can both drive
mode without two copies of the state drifting apart.

- Pad key: bind the **`PuckMode`** action (`A_PUCK_MODE`, id 132) to any key. It
  cycles the mode, toasts the new one, and pushes it down immediately. It works
  with no BLE host connected, since it is a pad-local setting rather than a
  keystroke.
- Puck button: a long press sends `BTN_LONG`, which is a *request*. The pad cycles
  and the new mode comes back in the next `PK_STATE`.

`PM_SCROLL` is skipped while `PUCK_MOUSE_HID` is 0, so cycling can never land on a
mode that silently does nothing.

## Volume readout

`vol` carries the **true system volume**, which neither device can otherwise know:
BLE HID volume is relative, so the pad sends "up"/"down" usages and is never told
the resulting level.

The path is `Windows Core Audio → companion app → HCMD_VOLUME (0x8B) → pad →
PK_STATE → puck`. The companion polls every 150 ms and writes only on change, so a
steady volume produces no BLE traffic. The pad relays immediately on receipt, so the
readout tracks the Windows slider even when the change came from somewhere else.

Without the companion running, `PF_VOL_KNOWN` stays clear and the puck simply shows
the mode name instead of a bar. The puck deliberately does **not** estimate a level
from its own tick count — that desyncs the first time volume changes from anywhere
else, and a confidently wrong number is worse than none.

The puck shows the bar only while the dial is in use (`BAR_HOLD_MS`, 1.5 s after the
last detent) and then reverts to the mode name.

## Button

| Gesture | Action |
|---|---|
| Short click | Play / pause |
| Double click | Next track |
| Long press (≥ 600 ms) | Cycle mode |

Button actions are consumer-control usages and are mode-independent.

## Pairing

The puck hardcodes the pad's **station MAC**. On the v5 bench board that is the base
MAC as printed by `WiFi.macAddress()`:

```
84:1F:E8:2B:33:48
```

Note this is *not* the BLE address the companion app connects to — that one is base
MAC **+ 2** (`84:1F:E8:2B:33:4A`). The two radios have different addresses on the same
chip; using the BLE address here is a silent failure mode.

The pad does **not** hardcode the puck's MAC. It learns the address from
`esp_now_recv_info_t->src_addr` on the first packet and adds it as a peer so it can
reply. Reflashing or replacing the puck therefore needs no pad-side change.

## ESP8266 vs ESP32 — API differences

Both chips speak the same ESP-NOW over the air, but the Arduino APIs are not
source-compatible. If you port changes between the two puck sketches, these are the
four places they diverge:

| | ESP32-C3 | ESP8266 |
|---|---|---|
| Header | `esp_now.h` | `espnow.h` |
| Init success | `== ESP_OK` | `== 0` |
| Role | n/a | `esp_now_set_self_role(ESP_NOW_ROLE_COMBO)` — **required**, and the link silently fails without it |
| Recv callback | `(const esp_now_recv_info_t*, const uint8_t*, int)` | `(uint8_t* mac, uint8_t* data, uint8_t len)` |
| Add peer | `esp_now_add_peer(&peer_info_struct)` | `esp_now_add_peer(mac, role, channel, key, keylen)` |
| Set channel | `esp_wifi_set_channel()` | `wifi_set_channel()` (from `user_interface.h`) |

`COMBO` is the role to use on the 8266: the puck both sends input and receives
`PK_STATE`, and `CONTROLLER`/`SLAVE` are each one-directional.

Pins differ too — the ESP-12 uses `SDA=GPIO4`, `SCL=GPIO5`, `BTN=GPIO13`. GPIO 0, 2
and 15 are strapping pins and are deliberately unused; a peripheral holding one at
the wrong level stops the module booting at all.

## Channel

Both ends pin themselves to **channel 1** (`PUCK_WIFI_CHANNEL`). ESP-NOW peers must
share a channel, and an unconnected station defaults to 1 on both chips — pinning it
explicitly just removes the ambiguity.

## Radio coexistence

This is the one genuine risk in the design. The pad runs **NimBLE and WiFi at the same
time** to receive ESP-NOW, sharing a single antenna. `docs/ROADMAP.md` records this
causing connection instability at high packet rates on v4.

Mitigations, all in the puck:

- Rotation is coalesced and sent at most once per `SEND_INTERVAL_MS` (40 ms), so a
  fast spin is a handful of packets, not hundreds.
- `PK_HELLO` heartbeats stop while the knob is active.
- The pad-side receiver is off by default (`Settings → PUCK`) and stored in NVS, so a
  pad with no puck never brings up the WiFi stack at all.

If BLE gets flaky, raise `SEND_INTERVAL_MS` before suspecting anything else.

## Sleep — a real limitation

**The puck cannot wake a sleeping pad.** The pad's idle timeout calls
`esp_light_sleep_start()`, which powers the WiFi radio down; ESP-NOW packets sent
during that window are simply lost. Waking is GPIO-only, from the key matrix.

So: press any pad key first, then use the knob. Or set `Settings → SLEEP` to `OFF`
if the puck is your main input.

This is not fixable without giving up light sleep. ESP-NOW has no low-power receive
mode in station-idle — staying reachable means keeping the radio on, which is most of
the idle current the sleep timeout exists to save.

On wake, the pad tears ESP-NOW down and re-initialises it rather than trusting state
that survived a radio power cycle. The puck is re-learned from its next packet, which
is at most one heartbeat (5 s) away, or immediate if you touch the knob.

## Config Mode interaction

The pad's Config Mode (`Settings → CONFIG`) tears down BLE and raises a SoftAP for
OTA. ESP-NOW is stopped and the station interface dropped before the AP comes up —
the two cannot share the interface, and leaving ESP-NOW running makes `softAP()` fail
to come up cleanly. Leaving Config Mode reboots the pad, which restores ESP-NOW from
NVS on the next boot.

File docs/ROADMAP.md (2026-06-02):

# MacroPad — Development Roadmap

## v3 (Complete)
- 6→8 button design
- ST7735 128×160 TN display
- ESP32 WROOM-32 bare module
- TP4056 + 18650 battery
- BLE via ESP32-BLE-Keyboard library
- Hand wired, direct GPIO

## v4 (Complete — current stable)
- 8-button layout
- Migrated to NimBLE-Arduino stack
- Fixed ghost BLE connection bug (Windows sleep/wake)
- M3 corner studs with heat-set inserts
- 1N5819 Schottky diode on VIN rail
- `macropad_v4_nimble.ino`

### v4 + ESP-NOW extension (In Testing)
- Optional media remote via AS5600 magnetic encoder
- ESP-NOW receiver built into v4 firmware
- Toggle in settings menu — saves to NVS
- Media remote: play/pause, next, prev, volume wheel
- Dual mode: ESP-NOW (relay via macropad) or direct BLE HID
- Velocity-accelerated smooth scrolling
- Adjustable sensitivity saved to NVS

## v5 (In Development)

### Hardware
- ESP32 WROOM-32 dev board (NodeMCU-32S)
- ST7789 240×320 IPS display (30.6×40.8mm active area)
- 3×4 MX mechanical switch matrix with 1N4148 diodes
- AS5600 magnetic encoder on custom bearing mount (50mm dial)
- EC12 encoder (button only — push switch)
- CKCS charge+boost module
- 18650 cell
- Custom copper-tape ridge substrate PCB
- 3D printed enclosure: 115×95×30mm body + encoder lobe

### Enclosure Design
- Landscape orientation
- Main body: 115×95mm
- Encoder dial lobe: half-proud right edge, 50mm diameter, 25mm proud
- Screen flush-mounted: 31.0×41.2mm glass window, 35.2×48.4mm module ledge
- Bottom cover: M3 screws into brass inserts, 4× corners
- Component cavity on underside: ESP32, CKCS, 18650

### PCB
- Copper tape ridge substrate (top face) — key matrix traces
- KiCad schematic complete
- Gerbers exported
- Ordered from JLCPCB

### Firmware (Planned)
- v5 modular architecture: config.h, types.h, matrix.h, encoders.h, display.h
- NimBLE-Arduino BLE stack
- 4×3 matrix scan with diodes (n-key rollover)
- AS5600 velocity-scaled smooth scrolling
- Settings menu via 12-key grid (each key = one setting)
- Full-screen editors per setting
- NVS persistence for all settings and custom presets
- Direct TFT drawing (no full-screen sprite — RAM constraint)
- Small sprites: 240×24 status bar, 72×60 key cells

### GPIO Allocation (v5)
- Cols: GPIO 13, 14, 25
- Rows: GPIO 26, 32, 33, 34
- EC12 SW: GPIO 39
- AS5600 SDA/SCL: GPIO 21, 22
- ST7789: MOSI=23, SCLK=18, CS=27, DC=17, RST=16, BL=19
- Zero strapping pins used

## Key Learnings

- **NimBLE vs ESP32-BLE-Keyboard**: NimBLE with GAP callbacks is required for reliable connect/disconnect tracking. The Arduino BLE stack returns false positives after Windows sleep/wake.
- **GPIO 12 strapping pin**: Must read LOW at boot. Used as TFT backlight in v4 — requires INPUT_PULLDOWN and active-HIGH wiring. Avoided entirely in v5.
- **LEDC + BLE init order**: BLE radio init resets LEDC peripheral. Always call `ledcAttach()` AFTER `NimBLEDevice::init()` — otherwise PWM backlight control is lost.
- **WiFi + BLE coexistence**: ESP-NOW (WiFi) and NimBLE (BT) share the antenna but use different protocols. Coexist but cause connection instability at high packet rates. Mitigated by making ESP-NOW optional (off by default).
- **ST7789 RAM constraint**: Full 240×320 16-bit sprite = 153KB — too large for WROOM-32 with BLE active. Solution: direct TFT drawing with small reusable sprites (status bar 240×24, key cell 72×60).
- **Input-only GPIOs**: GPIO 34, 35, 36, 39 have no internal pullups. Always use external 10kΩ resistors on these pins.
- **NVS via Preferences**: Use for all persistent settings — survives power cycles and firmware updates (unless flash is erased).

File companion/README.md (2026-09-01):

# MacroPad Deck — the companion app

The pad works on its own. The companion is what turns it into a Stream Deck: it
launches and focuses apps from a key press, pushes now-playing to the pad's
screen, follows the foreground window to switch presets, feeds the encoder puck
a real volume number, drives the local-LLM rewrite menu, and gives you a GUI
editor instead of hand-editing JSON.

Two front-ends over one shared core:

| Project | Target | What it is |
|---|---|---|
| `MacroPadDeck.Core` | `net9.0` | Wire protocol, profiles, Feishin client, `DeckController`, the platform interfaces. **No OS-specific code goes here.** |
| `MacroPadDeck` | `net9.0-windows10.0.19041.0` | Windows front-end — WinRT/SMTC, Core Audio, Win32, WPF |
| `MacroPadDeck.Linux` | `net9.0` | Linux front-end — BlueZ, MPRIS, X11/Wayland, GTK3 |

`GattSpike/` is a throwaway BLE probe, not part of the solution.

---

## 1. Install the .NET 9 SDK

The SDK, not just the runtime — you are building from source.

**Fedora / RHEL**
```bash
sudo dnf install -y dotnet-sdk-9.0
```

**Debian / Ubuntu**
```bash
sudo apt update && sudo apt install -y dotnet-sdk-9.0
```
On older releases that package does not exist; add Microsoft's feed first
(`packages-microsoft-prod.deb` from `packages.microsoft.com`) or use the
[install script](https://dot.net/v1/dotnet-install.sh).

**Arch**
```bash
sudo pacman -S dotnet-sdk
```

**Windows** — `winget install Microsoft.DotNet.SDK.9`, or the installer from
<https://dotnet.microsoft.com/download/dotnet/9.0>.

**Any OS, no root** — `curl -sSL https://dot.net/v1/dotnet-install.sh | bash -s -- --channel 9.0`,
then put `~/.dotnet` on your `PATH`.

Verify — the first line of output must start with `9.`:

```bash
dotnet --list-sdks
```

## 2. Install the platform dependencies

### Linux

```bash
# Fedora
sudo dnf install -y bluez NetworkManager gtk3 libayatana-appindicator-gtk3 \
                    wmctrl xdotool

# Debian / Ubuntu
sudo apt install -y bluez network-manager gtk3 libayatana-appindicator3-1 \
                    wmctrl xdotool

# Arch
sudo pacman -S bluez bluez-utils networkmanager gtk3 libayatana-appindicator \
               wmctrl xdotool
```

On GNOME the tray needs the AppIndicator host extension — KDE needs nothing:

```bash
sudo dnf install -y gnome-shell-extension-appindicator
gnome-extensions enable appindicatorsupport@rgcjonas.gmail.com
```

`wmctrl` and `xdotool` are X11-only; window-snap actions and foreground-follow
do nothing under Wayland without them, and foreground-follow needs a further
step there (see §6).

### Windows

Nothing beyond the SDK. WinRT, SMTC and Core Audio ship with the OS.

## 3. Pair the pad — do this before the first run

The host-link command characteristic is an **encrypted** write, so a BLE bond
must already exist. This is the single most common first-run failure: the app
connects, then every write silently fails.

```bash
bluetoothctl
  power on
  scan on          # wait for the pad to appear, then:
  pair  <MAC>
  trust <MAC>
  scan off
  quit
```

The pad advertises on its **base MAC + 2**. On Windows, pair it once through
Settings → Bluetooth as an ordinary keyboard.

## 4. Build and run

**Build the project, not the solution.** `dotnet build MacroPadDeck.sln` fails
on Linux with `error NETSDK1100: To build a project targeting Windows on this
operating system…` — the Windows front-end cannot be built there at all.

**Linux**
```bash
cd companion/MacroPadDeck.Linux
dotnet run
```

**Windows**
```powershell
cd companion\MacroPadDeck
dotnet run
```

First run writes `~/MacroPadDeck/profiles.json` (`%USERPROFILE%\MacroPadDeck\`
on Windows) and logs to `deck.log` beside it. Keep the log open — it is how you
debug everything:

```bash
tail -f ~/MacroPadDeck/deck.log
```

Set `deviceAddress` in `profiles.json` to your pad's address **without colons**
and restart.

Useful flags:

```bash
dotnet run -- --editor      # open the GTK editor directly, no tray
```

That is the way in on GNOME/Wayland before the AppIndicator extension is
registered, since without it there is no tray icon to click.

## 5. Install it properly

Publish a self-contained single file — no SDK needed on the target, and nothing
to break when a runtime updates.

**Linux**
```bash
cd companion/MacroPadDeck.Linux
dotnet publish -c Release -r linux-x64 --self-contained true \
               -p:PublishSingleFile=true -o out
./out/MacroPadDeck.Linux
```

**Windows**
```powershell
cd companion\MacroPadDeck
dotnet publish -c Release -r win-x64 --self-contained true `
               -p:PublishSingleFile=true -o out
```

> **Stop the running instance before republishing.** A live process holds the
> executable open and the publish fails, or worse, half-succeeds.

To start it at login on Linux, drop a `.desktop` file in
`~/.config/autostart/` pointing at the published binary.

## 6. Optional — the local-LLM rewrite menu

Select text anywhere, press a pad key, pick a style, and the rewrite is pasted
back over the selection. It needs a local model server, and on Linux it needs
one more thing.

```bash
# a model server
sudo dnf install -y ollama          # or your distro's package
sudo systemctl enable --now ollama
ollama pull qwen3:8b                # whatever `model` in styles.json names
```

On Linux the app has to synthesise Ctrl+C and Ctrl+V *into another application*.
Wayland forbids that by design and no compositor flag changes it, so both X11
and Wayland go through `ydotool` and a `/dev/uinput` virtual device:

```bash
sudo ./scripts/setup-ydotool.sh     # from the repo root; read it first
# then log out and back in for the new group to apply
```

Skip this and the rest of the app is unaffected — pressing a rewrite key just
reports `NOTHING SELECTED`.

Full guides: [`../docs/REWRITE_MENU.md`](../docs/REWRITE_MENU.md) ·
[`../docs/LINUX_REWRITE_SETUP.md`](../docs/LINUX_REWRITE_SETUP.md) ·
model choice and the fine-tune that did not ship:
[`../docs/FIX_MODEL_FINETUNE.md`](../docs/FIX_MODEL_FINETUNE.md)

## 7. Verify it works

| # | Check | Expected | Log line |
|---|---|---|---|
| 1 | Tray icon | keyboard icon in the top bar | `tray: no libayatana…` if the lib is missing |
| 2 | Pad connects | top menu item reads "● Pad online (fw v5…)" | `ble: UP`, then a hello |
| 3 | Key press | an app launches or focuses | `action: …` |
| 4 | Foreground-follow | focusing a mapped app switches preset | (preset echo) |
| 5 | Now-playing | title and progress appear on the pad | `mpris: push '…'` / `media: push …` |
| 6 | Editor | tray → Open editor → change a colour → Save | `editor: … pushed` |
| 7 | Firmware update | tray → Update firmware… (pad in CONFIG mode only) | `firmware: …` |

## Troubleshooting

**`ble: UP` but no hello, and nothing the app writes lands.** The bond is
missing or BlueZ never fired the pad's subscribe. Re-pair (§3); if it persists,
cycle notifications off and on after subscribing.

**`ble: device … not known yet`.** BlueZ has no cached record — it is not
paired. Back to §3.

**No tray icon.** In order: is `libayatana-appindicator3` installed
(`ldconfig -p | grep appindicator`), is the GNOME extension **enabled**
(`gnome-extensions list --enabled`), and did you log out and back in. Meanwhile
use `--editor`.

**Presets do not follow focus.** `x11: XOpenDisplay failed` means you are on
Wayland; that watcher is X11-only. The Wayland path polls the Focused Window
D-Bus GNOME extension instead, and either way it stays inert until each
profile's `appMatch` in `profiles.json` is actually filled in — an empty
`appMatch` matches nothing.

**Window-snap keys do nothing.** `wmctrl` / `xdotool` / `xrandr` missing, or
Wayland.

**Media never appears on Linux.** Check what your player exposes with
`playerctl metadata`; MPRIS variant unboxing is the fragile part.

**Firmware update cannot join the pad's hotspot.** SSID `MacroPad-Setup`,
password `macropad123`. Join it once by hand; the saved connection makes it
reliable afterwards.

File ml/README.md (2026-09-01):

# `ml/` — the FIX fine-tune lab

The pad's rewrite menu has a **FIX** style: select text, press the key, get the
spelling and grammar corrected in place and nothing else touched. It runs on a
local model. This directory is the experiment that asked whether a small
fine-tuned model should replace the general-purpose one, and answered it with
numbers.

**Verdict: it should not — keep `qwen3:8b` with `"think": false`.** The full
argument and every measurement is in [`../docs/FIX_MODEL_FINETUNE.md`](../docs/FIX_MODEL_FINETUNE.md).
Read that first; this file is only how to re-run the work.

---

## What is here

| | |
|---|---|
| `make_fix_data.py` | Builds the train/eval pairs — takes clean sentences and corrupts them, deterministically |
| `check_data.py` | Pre-flight: leakage between splits, near-duplicate overlap, clean-pair share |
| `score_fix.py` | Scores any Ollama model against the frozen eval — corrections, spurious changes, exact match, latency |
| `build_real_eval.py` | Builds a second eval from hand-written real-register snippets |
| `configs/` | Soup training configs — the sweep that was actually run |
| `RUNBOOK.md` | The raw lab record: every command, every result table, every dead end |
| `HANDOFF.md` | The problem statement and design rationale written before the sweep |

## What is deliberately not here

**The corpus, the datasets, the scored results and the model weights.** The
training pairs were generated from the author's private hardware-handoff notes,
so `data/`, `results/`, `output/` and `corpus/` are gitignored. The generator is
committed and deterministic, which is the part that matters: give it your own
documents and it rebuilds an equivalent set.

The exported GGUFs are ~1–3 GB each and belong nowhere near a git repo.

## Rebuilding the data

Any directory tree of `.md` files works as a corpus. Prose beats reference
tables — the generator mines sentences, so bullet soup gives it little to work
with.

```bash
cd ml
python make_fix_data.py --docs-root ~/my-notes --docs-root ~/more-notes
python check_data.py
```

Defaults: 6 documents held out **whole** for the eval split (never sentence-wise
— an eval sentence must not have a near-twin in training), 3 corrupted variants
per clean segment, 5% clean pairs, `seed=20260816`. Same inputs give the same
files.

`check_data.py` is the go/no-go. It fails on exact leakage and reports the worst
near-duplicate overlap; the original run passed at 14%.

> **Freeze the eval before you look at a single result.** `data/fix-eval.jsonl`
> was pinned at `cdbfa3a0…` and every number in the runbook is against that
> hash. If the eval changes after results have been seen, the scoreboard is void
> — regenerate everything or change nothing.

## Training

The training stack needs Python 3.12 and a CUDA GPU. On 8 GB you are limited to
4-bit; see the VRAM section of `RUNBOOK.md` for why bf16 does not fit a 1.5B
here despite the arithmetic suggesting it should.

```bash
curl -LsSf https://astral.sh/uv/install.sh | sh
uv venv --python 3.12 .venv && source .venv/bin/activate
uv pip install soup-cli
uv pip install "soup-cli[train]"
soup doctor                                   # only meaningful after [train]
soup train --config configs/probe-1.5b-4bit-e6.yaml --yes
```

`--yes` is not optional in a non-interactive shell. Without it `soup train`
prints `Start training? [Y/n]: Aborted.` and **exits 0**, so a backgrounded run
looks like it started and silently did nothing.

`configs/probe-1.5b-4bit-e6.yaml` is the best model this project produced.
`soup-0.5b.yaml` / `soup-1.5b.yaml` are the original pair and the 1.5B one does
not run on 8 GB — they are kept because the runbook's early tables refer to them.

## Scoring

`score_fix.py` talks to Ollama at `temperature: 0`, so runs are greedy and
repeatable.

```bash
python score_fix.py --model qwen3:8b --think off --out results/baseline.json
python score_fix.py --model soup-macropad-fix-1.5b-4bit-e6:latest --out results/ft-e6.json
```

It reports four things. Only one of them decides anything:

- **corrections** — of the errors that were planted, how many came back fixed
- **spurious changes** — edits made that the reference did not ask for. **This is
  the ship criterion.** A FIX key that quietly rephrases your sentence is worse
  than one that misses a typo, because you will not notice
- **exact match** — whole output identical to the reference
- **latency** — median and p95, per case

## Using a fine-tune anyway

Nothing stops you. Export to GGUF, register it with Ollama, and name it in the
FIX entry of `~/MacroPadDeck/styles.json` (`%USERPROFILE%\MacroPadDeck\` on
Windows) — that file hot-reloads, so the pad picks it up in under a second with
no rebuild. See [`../docs/REWRITE_MENU.md`](../docs/REWRITE_MENU.md).

Set `"think": false` on the FIX style whichever model you use. That one line was
worth more than the entire training sweep.

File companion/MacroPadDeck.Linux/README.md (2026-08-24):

# MacroPad Deck — Linux

The Linux front-end of the MacroPad companion. It shares all wire-protocol,
profile, Feishin and orchestration logic with the Windows build via
`MacroPadDeck.Core`; only the platform edges differ.

| Concern | Windows | Linux (this project) |
|---|---|---|
| Pad link (BLE GATT) | WinRT | **BlueZ** over D-Bus (`Linux.Bluetooth`) |
| Now-playing | SMTC | **MPRIS** over D-Bus (`Tmds.DBus`) |
| Foreground-follow | `SetWinEventHook` | **X11** `_NET_ACTIVE_WINDOW` polling |
| Key actions / window snap | Win32 | **wmctrl / xdotool / xdg-open** |
| Master volume (puck readout) | Core Audio | **pactl** (PulseAudio / PipeWire) |
| Rewrite: key injection | `SendInput` | **ydotool** (uinput) — X11 *and* Wayland |
| Rewrite: clipboard | WinForms Clipboard | **wl-clipboard** / **xclip** |
| Rewrite: preview window | WPF | **GTK3**, non-focusable under Wayland |
| Firmware Wi-Fi join | `netsh` | **nmcli** |
| Tray | WinForms NotifyIcon | **Ayatana AppIndicator** (SNI) + GTK3 menu |
| Editor | WPF | **GTK3** (`GtkSharp`) |
| Autostart | Run registry key | `~/.config/autostart/*.desktop` |

Everything else — pad protocol, profiles, presets, Feishin, the encoder puck's
volume stream, the pad-fetched action picker, and the whole rewrite state
machine — is shared `MacroPadDeck.Core` code, identical on both platforms.

## Requirements

**Display server:** works under both, with one gap. Foreground-follow (profile
auto-switching) and the window actions (snap/maximise/next-monitor) use
X11/EWMH, so they are inert under Wayland; everything else — pad link, key
launches, media, volume, editor, firmware, and the rewrite menu — works on
either. Run an Xorg session if you want profile auto-follow.

**Runtime libraries / tools** (install names shown for Debian/Ubuntu):

- .NET 9 runtime (`dotnet-runtime-9.0`) — or publish self-contained
- `bluez` + a working BLE adapter, and the pad **paired once** so BlueZ knows it
- GTK3 runtime + **libayatana-appindicator3** (the tray). Fedora:
  `sudo dnf install gtk3 libayatana-appindicator-gtk3`
- `wmctrl`, `xdotool`, `xrandr` — window actions
- `pactl` (`pulseaudio-utils` / `pipewire-pulse`) — master volume for the puck
- `NetworkManager` (`nmcli`) — firmware-update hotspot join
- An MPRIS-capable player for now-playing (Spotify, most browsers, native players)
- **Rewrite menu only:** `ydotool` + a running `ydotoold`, and `wl-clipboard`
  (Wayland) or `xclip` (X11), plus a local Ollama. One-time setup:
  `sudo ./scripts/setup-ydotool.sh` — see
  [docs/LINUX_REWRITE_SETUP.md](../../docs/LINUX_REWRITE_SETUP.md). Skipping this
  leaves every other feature working; `write` keys just report
  `NOTHING SELECTED`.

> **GNOME note (Fedora Workstation default):** the tray uses AppIndicator/SNI,
> which GNOME shows only via an extension. Install and enable it once:
> ```bash
> sudo dnf install gnome-shell-extension-appindicator
> gnome-extensions enable appindicatorsupport@rgcjonas.gmail.com   # then log out/in
> ```
> KDE Plasma shows SNI tray icons natively — no extension needed.

## Build & run

```bash
cd companion/MacroPadDeck.Linux
dotnet run
```

Self-contained single build to copy to another machine:

```bash
dotnet publish -c Release -r linux-x64 --self-contained true \
  -p:PublishSingleFile=true -o out
./out/MacroPadDeck.Linux
```

## Configuration

Same as Windows: `~/MacroPadDeck/profiles.json`, hot-reloaded on save, log at
`~/MacroPadDeck/deck.log`. First run writes a starter config (edit the `firefox`/
`code` sample bindings in the DECK preset to taste). Set `deviceAddress` to the
pad's BLE address (base MAC **+2**). Edit via the tray's **Open editor**, or
**Edit profiles.json**, or any text editor.

Rewrite styles live alongside it in `~/MacroPadDeck/styles.json` (tray → **Edit
styles.json**), same format and defaults as Windows.

The editor's key types include `padAction` — the pad's own builtin actions,
fetched live over the link, so the picker always matches the firmware actually
flashed — and `write`, which opens the rewrite menu.

## Troubleshooting

Things to watch for in `deck.log`:

- `ble: device … not known yet — scanning` → pair the pad once (`bluetoothctl`)
- `x11: XOpenDisplay failed` → you're on Wayland; profile auto-follow and window
  actions are inert, everything else still works
- window actions doing nothing → install `wmctrl`/`xdotool`
- `volume: pactl …` → no `pactl` on PATH; the puck falls back to showing mode only
- `capture: could not synthesise Ctrl+C — is ydotoold running?` →
  `systemctl --user status ydotoold`, and check you logged out and back in after
  `setup-ydotool.sh` added you to the `ydotool` group
- `capture: preview window took focus` → you clicked the preview; under Wayland
  that costs the paste target, so the paste is refused rather than misaimed

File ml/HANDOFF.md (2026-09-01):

# soup-lab — fine-tuning a local FIX model for the macropad

Handoff written 2026-08-16. **Updated 2026-08-16 (later, on Linux): both models are
now trained, exported, deployed and scored. The result is negative — do not ship.**
See the RESULT section at the top of `RUNBOOK.md` for the numbers; the summary is:

- ft 1.5B-4bit ties the incumbent on corrections (78.6% vs 79.1%) and is 1.8x faster,
  but **doubles the spurious-change rate (0.50 vs 0.26/case)** — the metric this
  document names as the one that decides shipping. ft 0.5B-4bit is worse still (0.70).
- **Then epochs turned out to be a real lever** (2026-08-17). At **6 epochs** the 1.5B
  reaches **82.4% corrections — beating the incumbent's 79.1%** — with spurious down to
  0.38; at 12 epochs, 81.3% / 0.36 / 64.0% exact (vs the incumbent's 63.0%), ~2x faster
  throughout. The trend plateaus at ~6; **do not escalate epochs further.** The
  `epochs: 2  # 3 overfits` comment in the shipped configs is refuted — it was an
  assumption and it cost performance.
- So the fine-tune now **wins on corrections, ties on exact match, wins on speed, and
  loses only on restraint** (0.36 vs 0.26 spurious, 3/5 vs 5/5 clean left alone).
  Narrow enough that this is no longer a dead end — but restraint is the ship
  criterion, so the recommendation still holds.
- Both regress on leaving clean text alone (3/5 vs the incumbent's 5/5).
- **The recommendation is unchanged and is now the measured best option: keep
  `qwen3:8b` and flip `"think": false`.** No training required.
- The open question below about loss masking is **resolved: masking works** (verified
  directly — only the assistant response is in the loss). It is not the explanation
  for the spurious-change rate.

Everything else below is as originally written — either measured on hardware or
explicitly marked as unverified.

Source of truth for commands: `RUNBOOK.md` beside this file.

---

## Problem

The pad's rewrite menu sends every style to `qwen3:8b` via Ollama except EMAIL and
ASK, which go to `gpt-oss:120b-cloud`. FIX was believed to be the slowest style at
~17 s, because it runs `"think": true` in `styles.json`.

The goal was a small task-specific model that does FIX offline in well under a
second, and — more importantly — a proving run for a pipeline that later covers a
router, the tone styles, and distilling the cloud model.

FIX was chosen first because it is the **only** style whose training data can be
generated programmatically with perfect ground truth: corrupt clean text, and
`(corrupted → clean)` is the pair. No hand-written judgement calls.

## Constraints

- **Windows box cannot train.** Default Python is 3.14 (too new for the stack); the
  only other interpreter is a Microsoft Store 3.12, a poor venv base. Hence Linux.
- Laptop RTX 4060, **8 GB VRAM**, 74 GB free on C:.
- Deployment must not require an app rebuild — rebuilds are the risky path.
  `styles.json` has a per-style `model` field and hot-reloads, so the ship step is
  one line and the rollback is `"model": ""`.
- The corpus is the user's own private prose (`hardware-handoffs`, memory files,
  `project-ideas`). It stays local. Generated pairs are the only thing training needs.

## Investigation

### What was built (all verified working)

| File | What it does |
|---|---|
| `make_fix_data.py` | Corruption generator. Stdlib only, deterministic (`seed=20260816`). Runs fine on Python 3.14. |
| `check_data.py` | Pre-flight: schema, exact leakage, shingle near-dup leakage, clean-pair share, eval hash. |
| `score_fix.py` | Eval harness against Ollama. Reports corrections and spurious changes **separately**. |
| `soup-0.5b.yaml` / `soup-1.5b.yaml` | Training configs. Differ **only** in `base` and `output`. |

Output: **1074 train rows, 100 eval rows.** Pre-flight PASS.
Hashes — eval `cdbfa3a074cff0a3…`, train `2ff886e51138743b…`.

### The leakage trap in this corpus, and the fix

Splitting train/eval **by document is not sufficient here.** The memory files are
mirrors of the handoff docs (that is what `sync-memory.sh` does), the two copies
have drifted by a few words, and exact-match dedup lets the near-twins through.

`check_data.py` caught it on the first run: one eval row shared >50% of its 5-word
shingles with training. `drop_leaks()` now filters eval segments against training
text at a 0.3 threshold; worst remaining overlap is 14%.

**This will recur** if the corpus is extended. Always run `check_data.py`.
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

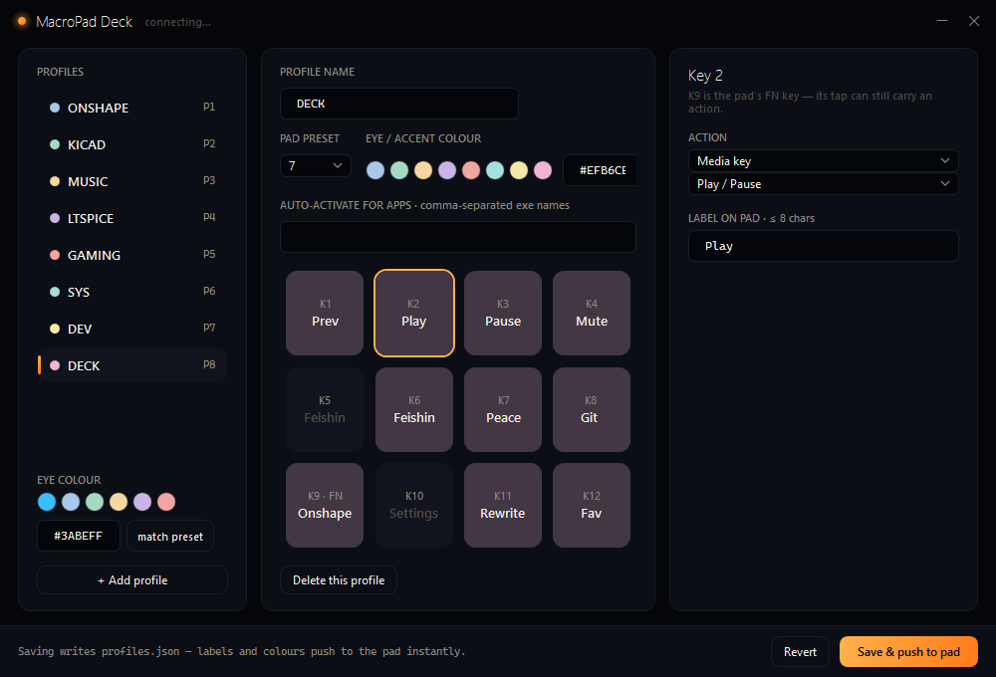
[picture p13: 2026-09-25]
companion/screenshots/void-deck-editor-2026-09-15.png

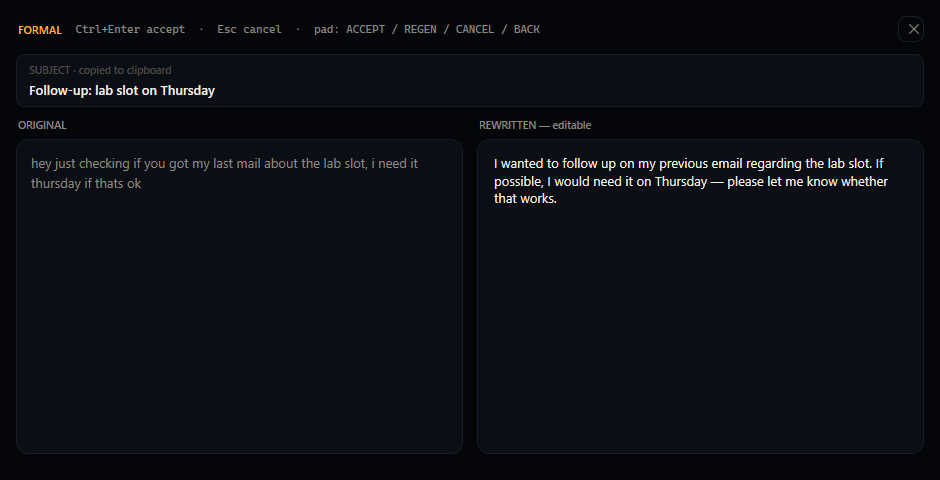
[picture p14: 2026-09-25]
companion/screenshots/void-deck-rewrite-2026-09-15.png

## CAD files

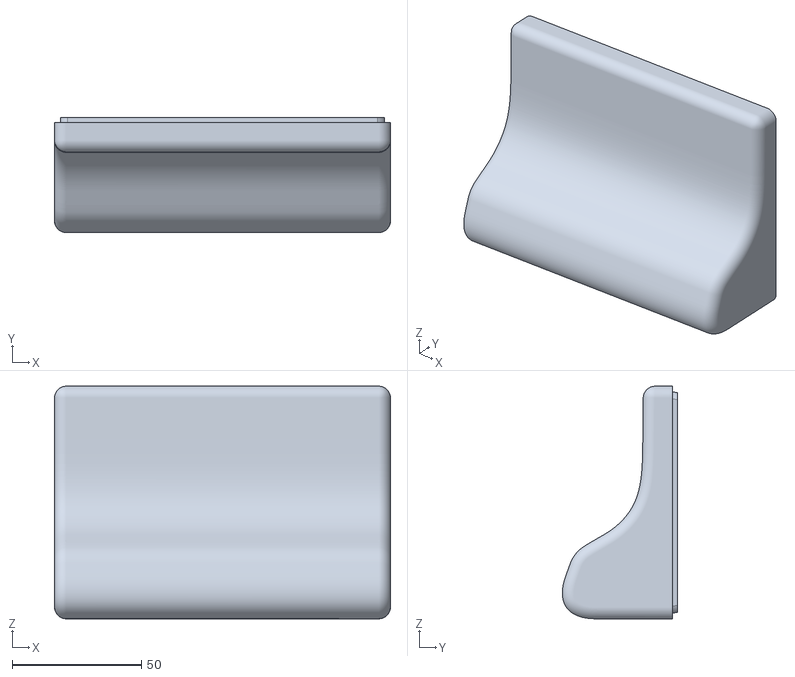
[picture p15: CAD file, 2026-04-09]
cad/stl/enclosure/enclosure_base.stl
130.0 x 44.6 x 90.0

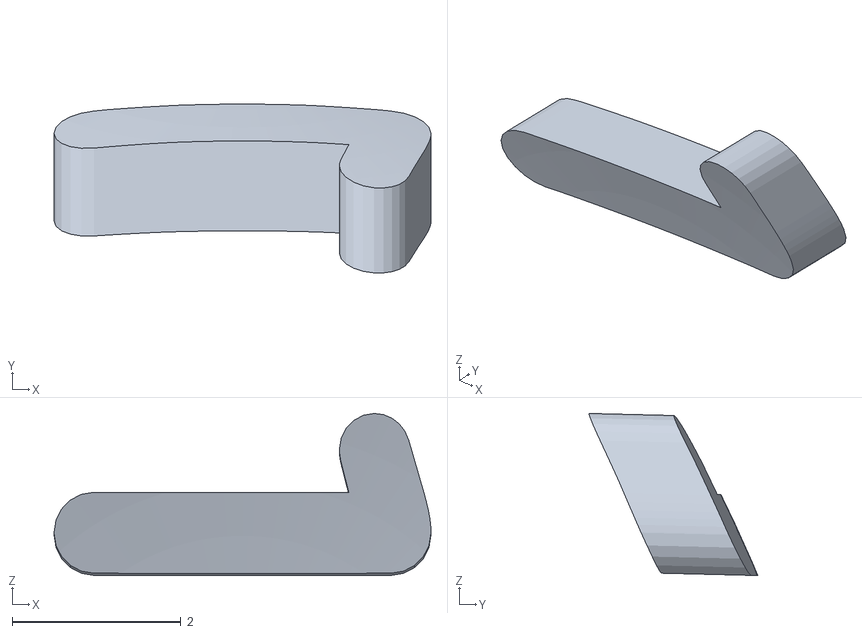
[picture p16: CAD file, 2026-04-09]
cad/stl/keycap/keycap_v4.stl
4.47 x 2.00 x 1.92

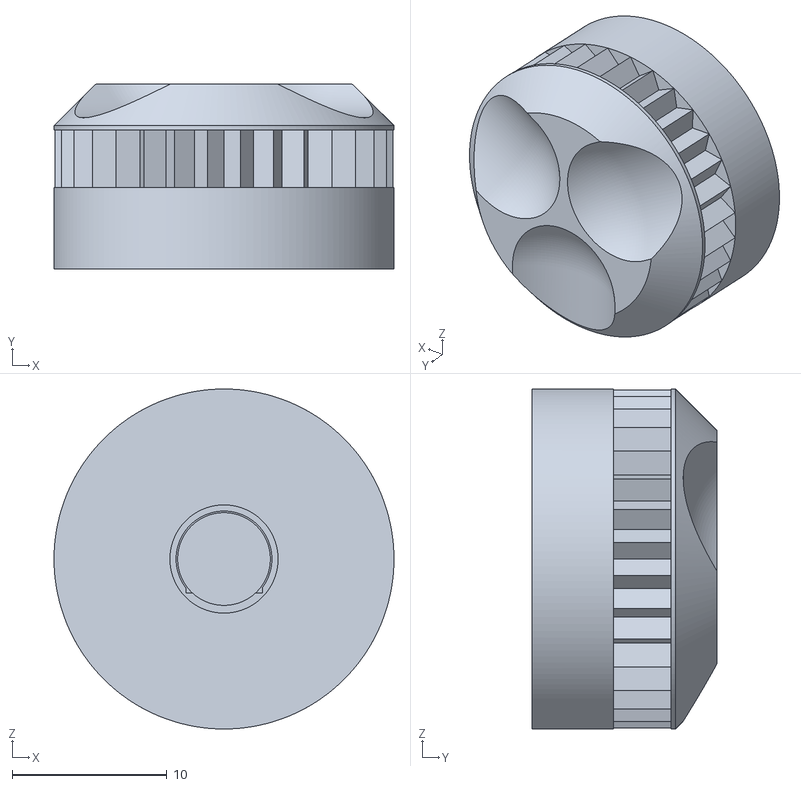
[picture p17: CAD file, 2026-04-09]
cad/stl/knob/encoder_knob.stl
22.0 x 12.0 x 22.0

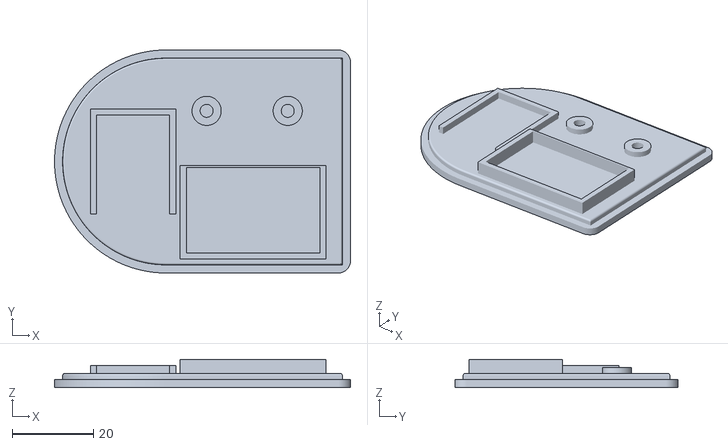
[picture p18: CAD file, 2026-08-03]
cad/stl/puck/puck_dial_counterpart_2.stl
73.0 x 55.0 x 7.00

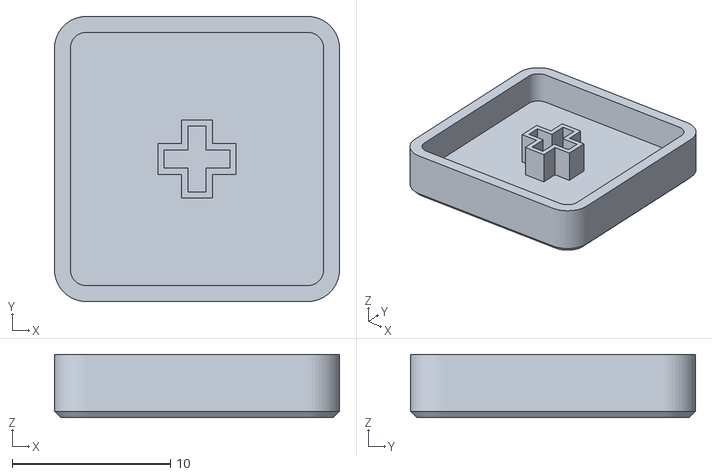
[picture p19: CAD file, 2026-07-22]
cad/stl/v5/v5_keycap_low_profile.stl
18.0 x 18.0 x 4.00

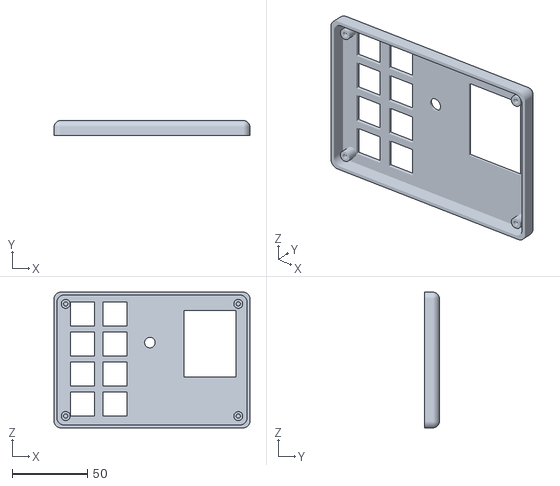
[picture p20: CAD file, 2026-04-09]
cad/stl/enclosure/enclosure_top.stl
130.0 x 10.0 x 90.0

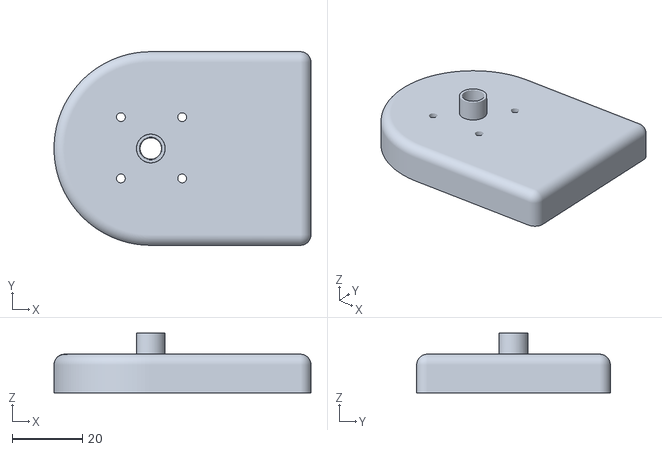
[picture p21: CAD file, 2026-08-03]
cad/stl/puck/puck_dial_counterpart_1.stl
73.0 x 55.0 x 17.0

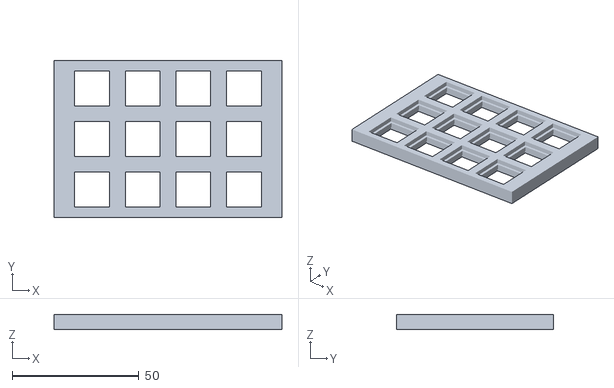
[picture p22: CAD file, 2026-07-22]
cad/stl/v5/v5_switchplate.stl
90.0 x 62.0 x 6.00

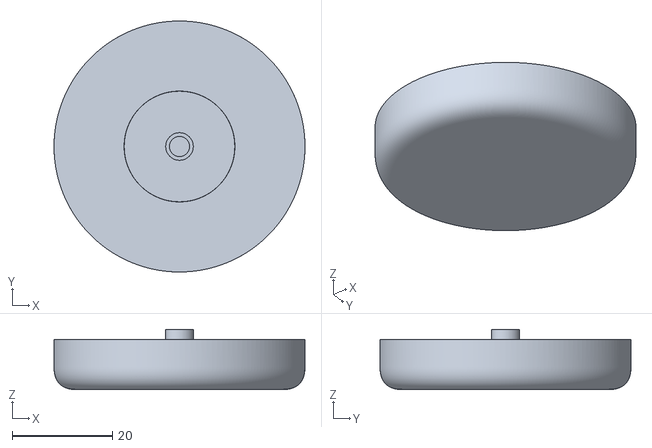
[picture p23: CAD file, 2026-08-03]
cad/stl/puck/puck_dial.stl
50.0 x 50.0 x 12.0

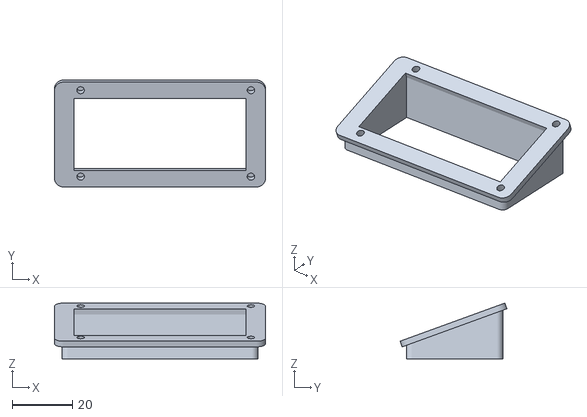
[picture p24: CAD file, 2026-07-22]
cad/stl/v5/v5_display_mount.stl
70.0 x 35.5 x 18.5

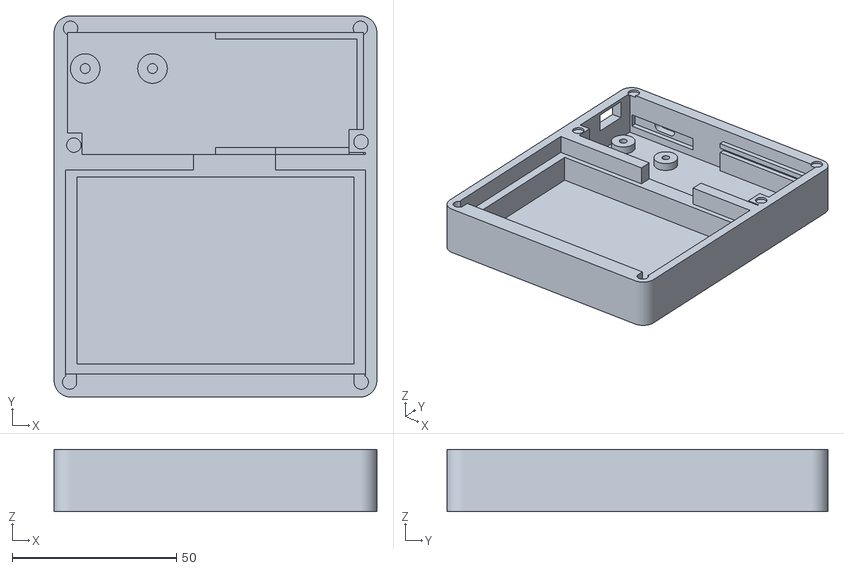
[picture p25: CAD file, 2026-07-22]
cad/stl/v5/v5_case_bottom.stl
98.2 x 116.0 x 19.0

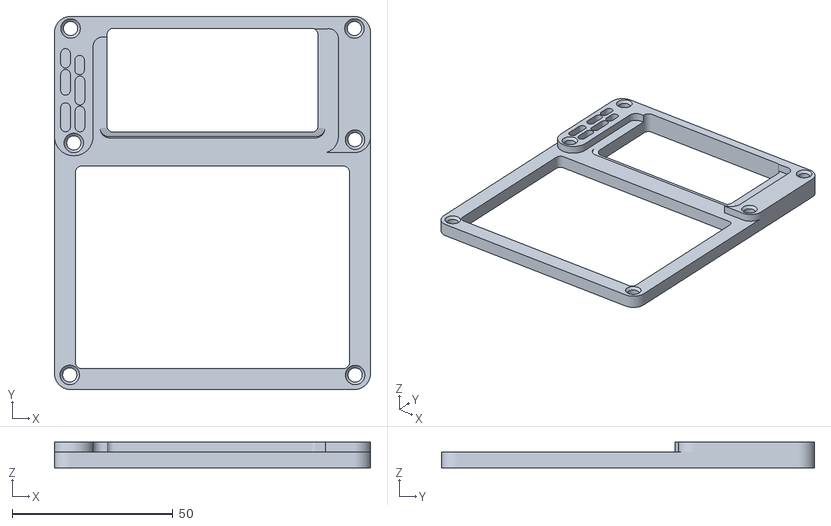
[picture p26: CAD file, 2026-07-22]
cad/stl/v5/v5_case_top_plate.stl
98.2 x 116.0 x 8.00

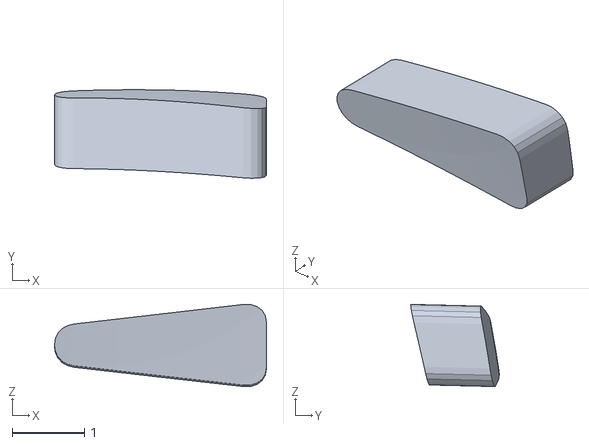
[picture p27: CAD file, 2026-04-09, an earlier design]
cad/stl/keycap/keycap_v2.stl
2.94 x 1.23 x 1.14

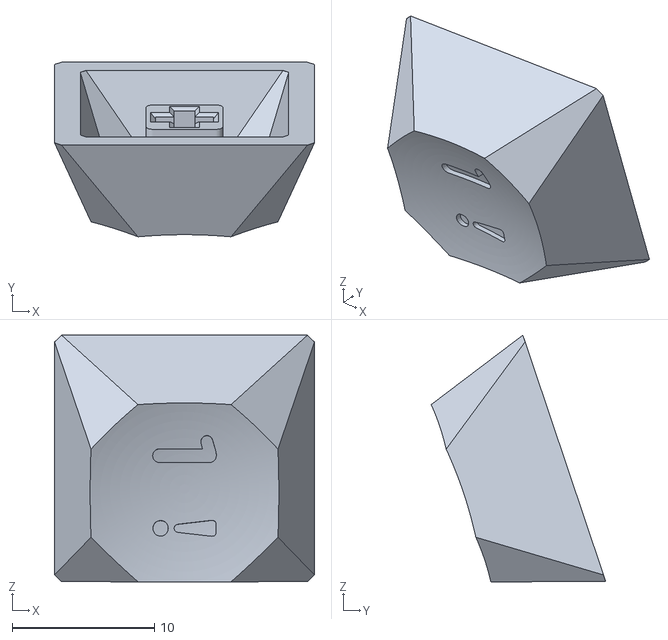
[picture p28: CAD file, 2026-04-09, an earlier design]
cad/stl/keycap/keycap_v1.stl
18.2 x 12.3 x 17.3

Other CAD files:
cad/stl/keycap/keycap_v3.stl

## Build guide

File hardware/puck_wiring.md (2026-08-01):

# Encoder Puck — Wiring Reference

Companion device for the MacroPad v5. A knob with a screen that talks to the pad
over ESP-NOW. Protocol: `docs/PUCK_PROTOCOL.md`. Firmware:
`firmware/v5/puck_encoder/puck_encoder.ino`.

## Bill of materials

| Part | Notes |
|---|---|
| ESP32-C3 SuperMini (or ESP32-S3 mini) | Set `BOARD` at the top of the sketch |
| AS5600 breakout | I2C address `0x36`, fixed — not selectable |
| SSD1306 OLED, I2C | **As built: 0.91" 128×32.** Address `0x3C` (some are `0x3D`) |
| Diametrically magnetised magnet | 6×2.5 mm typical. **Radial magnets do not work.** |
| Momentary push button | Any SPST |
| Knob / shaft / bearing | Mechanical, your choice |

## Connections — ESP32-C3 SuperMini

Both I2C devices share one bus. Different addresses, so no conflict, and they
wire in parallel.

```
   ESP32-C3 SuperMini
   ┌───────────────┐
   │ 3V3 ──────────┼──┬──────────────┬─────────── AS5600 VCC
   │               │  │              └─────────── OLED   VCC
   │ GND ──────────┼──┼──┬───────────┬─────────── AS5600 GND
   │               │  │  │           └─────────── OLED   GND
   │               │  │  └───────────────────────  button leg B
   │ GPIO5 (SDA) ──┼──┼─────────────┬───────────── AS5600 SDA
   │               │  │             └───────────── OLED   SDA
   │ GPIO6 (SCL) ──┼──┼─────────────┬───────────── AS5600 SCL
   │               │  │             └───────────── OLED   SCL
   │ GPIO4 ────────┼──┼───────────────────────────  button leg A
   └───────────────┘
```

| Signal | C3 pin | S3 mini pin |
|---|---|---|
| I2C SDA | GPIO5 | GPIO35 |
| I2C SCL | GPIO6 | GPIO36 |
| Button | GPIO4 | GPIO2 |

**Why not the Arduino-default 8/9 on the C3:** GPIO2, 8 and 9 are strapping pins —
their level at boot selects boot mode. On the SuperMini specifically, GPIO8 also
drives the onboard LED, which hangs across the rail as a stray pullup. GPIO5/6/4 are
plain GPIOs with none of that. If you have already wired to 8/9 it will probably
work, but this is the first thing to suspect if the board boots erratically.

**Pull-ups:** most AS5600 and SSD1306 breakouts have 4.7 kΩ pull-ups fitted. Two
boards in parallel gives ~2.4 kΩ, which is fine at 400 kHz. Do not add more.

**Power:** both modules are 3V3. The AS5600 is not 5V tolerant on its I2C lines.

## Magnet placement

This is the part that most often goes wrong.

- The magnet must be **diametrically** magnetised (N and S across the diameter, not
  through the thickness). A radial/axial magnet reads as noise or a dead knob.
- Centre it on the AS5600 chip — not the board, the chip.
- Air gap **0.5–3 mm**. Closer is not better; saturation degrades the reading.
- The magnet must rotate with the knob and stay concentric. Wobble reads as jitter.

The firmware checks the AS5600 `MD` status bit at boot and every 5 s. **If the magnet
is missing or misplaced, the OLED shows `! NO MAGNET`** — you do not have to guess.

## First power-on

1. Flash the puck. **`CDCOnBoot=cdc` is not optional** — see below:
   ```bash
   arduino-cli compile --fqbn esp32:esp32:esp32c3:CDCOnBoot=cdc --libraries C:/Users/gsaip/Documents/Arduino/libraries --output-dir build_puck firmware/v5/puck_encoder
   ```
   ```bash
   arduino-cli upload -p COM8 --fqbn esp32:esp32:esp32c3:CDCOnBoot=cdc --input-dir build_puck firmware/v5/puck_encoder
   ```
2. Open Serial at 115200. Boot prints the puck's own MAC, the pad MAC it targets,
   and whether the magnet was found.

> **USB CDC gotcha — cost us a silent-serial dead end on 2026-07-30.**
> The C3 core defaults to `cdc_on_boot=0`, which maps `Serial` to **UART0 on
> GPIO20/21**, not to the native USB port. Flash without `CDCOnBoot=cdc` and the
> board runs fine, enumerates fine, uploads fine — and prints absolutely nothing
> to the USB serial monitor. In the Arduino IDE this is
> *Tools → USB CDC On Boot → Enabled*. The pad's WROOM-32 has no such issue
> because its serial goes through a real CH340/CP2102 UART bridge.
3. The OLED should show `NO PAD` and a hollow link dot.
4. On the pad: **Settings → PUCK** to toggle it on. The pad brings up ESP-NOW
   immediately, and the cell reads `ON`.
5. Turn the knob. The pad toasts `PUCK LINKED`, its Settings cell changes to
   `LINKED`, and the puck's OLED header changes to `LINKED` with a filled dot.
6. Press SAVE on the pad so the setting survives a reboot.

## Troubleshooting

| Symptom | Cause |
|---|---|
| OLED blank, serial says `NOT WIRED` | Module is at `0x3D`, or SDA/SCL swapped, or no power |
| **Image cropped, doubled, or only half the screen used** | **`OLED_H` doesn't match the panel.** 0.91" = `32`, 0.96" = `64`. |
| `! NO MAGNET` on the OLED | Wrong magnet type, off-centre, or gap too large |
| OLED fine, `NO PAD` forever | Pad's PUCK setting is off, or `PAD_MAC` is wrong — see below |
| `PAD: NO BLE` | Link is fine; the pad just isn't connected to a host |
| `PAD: OFF` | Pad heard you but has the puck disabled in Settings |
| Knob jitters ±1 constantly | Magnet wobble, or `THRESHOLD` too low |
| Too sensitive / too coarse | `THRESHOLD` in the sketch — higher is coarser |
| Pad's BLE drops while spinning | Raise `SEND_INTERVAL_MS` (radio coexistence) |
| SCROLL mode does nothing | Expected — needs `PUCK_MOUSE_HID 1` on the pad |

**Wrong `PAD_MAC` is the classic failure.** The puck must target the pad's **station
MAC** (`84:1F:E8:2B:33:48`), not the BLE address the companion app uses
(`84:1F:E8:2B:33:4A`, base + 2). Same chip, two radios, two addresses. Using the BLE
one fails completely silently — ESP-NOW just sends into the void.

To confirm the pad's real station MAC, enable PUCK in Settings and watch its serial:
`[PUCK] listening, this pad's STA MAC: ...`

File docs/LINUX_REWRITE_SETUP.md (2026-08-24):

# Rewrite menu on Linux — one-time setup

The local-model rewrite menu (see [REWRITE_MENU.md](REWRITE_MENU.md)) reads the
selection out of whatever app is focused and pastes the rewrite back over it.
On Windows that is a single `SendInput` call. On Linux it needs two things the
distro does not set up for you.

Everything else in the companion works without this. If you skip it, the pad
reports `NOTHING SELECTED` when you press a `write` key and the rest of the app
carries on normally.

## 1. A local model server

The flow talks to Ollama on `http://localhost:11434` by default (override with
`llmUrl` in `styles.json`).

```bash
sudo dnf install -y ollama            # or your distro's package
sudo systemctl enable --now ollama
ollama pull qwen2.5:7b-instruct       # whatever `model` in styles.json names
```

`styles.json` lives next to `profiles.json` — the tray's **Edit styles.json**
opens it. The tray's **Load write model** / **Unload write model** items let you
park the model in VRAM before a writing session and hand it back before a game.

## 2. Key injection that Wayland accepts

The companion has to synthesise Ctrl+C and Ctrl+V *into another application*.

- **X11** allows this through XTEST, which is what `xdotool` drives.
- **Wayland does not.** A client cannot inject input into another client, by
  design. No compositor flag changes this.

The way through on both is [ydotool](https://github.com/ReimuNotMoe/ydotool),
which writes to a `/dev/uinput` virtual device. The compositor sees an ordinary
USB keyboard and cannot tell the difference — which is exactly why it needs
permission to create one.

```bash
sudo ./scripts/setup-ydotool.sh
```

That script is short and worth reading before running as root. It:

1. installs `ydotool`, plus `wl-clipboard` (Wayland) or `xclip` (X11);
2. creates a `ydotool` group and adds you to it;
3. drops a udev rule giving that group access to `/dev/uinput`;
4. installs a **user** systemd unit for `ydotoold` and starts it.

The daemon runs as your user, not as root — it only needs the uinput device,
and a root daemon holding a world-writable socket would be a keylogger with
extra steps.

**Log out and back in** afterwards so the new group membership applies. Verify:

```bash
systemctl --user status ydotoold      # active (running)
id -nG | tr ' ' '\n' | grep ydotool   # ydotool
```

Then test injection into a text editor — click into it first, so it has focus:

```bash
sleep 3; ydotool type "hello from ydotool"
```

If nothing is typed, the daemon is not reachable. Check `YDOTOOL_SOCKET`:
packagings disagree on where the socket lives. The companion honours an explicit
`YDOTOOL_SOCKET` and otherwise looks for `$XDG_RUNTIME_DIR/.ydotool_socket`,
which is what the unit installed by the script uses.

## How the Wayland flow differs from Windows

Two behavioural differences fall out of the compositor's restrictions. Both are
in `LinuxTextCapture` and `GtkRewritePreview`.

**The preview window never takes focus.** Wayland offers no way to hand focus
back to the app the selection came from, so instead focus is never taken away:
the preview is mapped non-focusable and the target app keeps the keyboard for
the whole flow. This suits the feature — WriteFlow's premise is that the pad is
the input device and the monitor is only the display.

**The preview is therefore read-only under Wayland.** Editing needs focus.
Accept the rewrite as generated, press REGEN for another pass, or paste and edit
in place afterwards. Under X11 the window is focusable and editable, matching
the Windows build, and `Ctrl+Enter` / `Esc` work.

If you click the preview window anyway, it will take focus, and the companion
will *refuse to paste* rather than fire Ctrl+V at whatever is focused now — the
pad reports `PASTE FAILED`. Pasting a rewritten paragraph into the wrong
application is far worse than doing nothing.

## Clipboard

The selection travels via the clipboard, so the companion briefly overwrites it
and puts the old value back afterwards. Only the text flavour is preserved — a
clipboard holding an image or files can't be round-tripped this way.

Under Wayland `wl-copy` forks a small server to own the selection, so you may
see a stray `wl-copy` process after a rewrite. That is normal; it exits when
something else claims the clipboard.

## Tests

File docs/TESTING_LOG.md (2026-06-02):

# Testing Log

## AS5600 Magnetic Encoder
- **Board**: NodeMCU ESP32S v1.1
- **Status**: ✓ Working
- **Notes**:
  - Angle reads 0–4095 correctly
  - Velocity calculation working
  - Wraparound at 0/4095 boundary handled
  - AGC value ~50–100 = good air gap
  - Diametric cylinder magnet required
  - Wire: SDA→D2(GPIO4), SCL→D1(GPIO5) on ESP8266 NodeMCU

## ST7789 240×320 Display
- **Board**: NodeMCU ESP32S v1.1
- **Module**: SmartElex 2" IPS (R257748 robu.in), driver ST7789P3
- **Status**: ✓ Working
- **Notes**:
  - 9 pins: VCC GND SDA SCL CS DC RST EN TE
  - EN = backlight enable (not BL PWM) — wire to 3.3V for always-on
  - TE = tearing effect — leave unconnected
  - No BL pin — backlight controlled via EN
  - Full 240×320 confirmed working with 4-band colour test
  - RAM too small for full sprite (153KB) — use direct drawing
  - Small sprites OK: 240×24 status bar, 72×60 key cells
  - Library: TFT_eSPI, ST7789_DRIVER
  - Pins: MOSI=23, SCLK=18, CS=27, DC=17, RST=16
  - EN: PWM via ledcAttach GPIO19 or direct 3.3V

## MX Mechanical Switches
- **Type**: Cherry MX compatible, plate mount 3-pin
- **KiCad footprint**: Button_Switch_Keyboard:SW_Cherry_MX_1.00u_PCB
- **Spacing**: 19.05mm standard MX pitch
- **Status**: PCB ordered, not yet tested on hardware

## Media Remote (ESP-NOW + BLE dual mode)
- **Status**: In development
- **Issues**:
  - BLE connection instability when WiFi (ESP-NOW) active simultaneously
  - Solution: ESP-NOW off by default, toggle in settings
  - Input-only GPIO pins (34,35,39) need external pullups — or use GPIO 25,26,27
  - Reconnected button pins to GPIO 25, 26, 27 (internal pullup capable)

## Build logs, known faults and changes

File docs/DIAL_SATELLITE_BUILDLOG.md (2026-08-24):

# Dial Satellite — Engineering Build Log

Dated record of every bench session on the dial satellite: what was tried,
what the instruments actually said, what failed and why. Design and frozen
decisions live in `DIAL_SATELLITE.md`; this file is the history.

Rule for this log: **record measurements, not impressions.** If a claim has no
observation behind it, it does not belong here.

---

## 2026-07-27 — Session 1: ESP-12E bring-up (BLOCKED)

**Goal:** §7.1 step 0 — flash `firmware/tests/esp12e_bringup.ino` onto a bare
ESP-12E and confirm a steady heartbeat.

**Outcome: blocked.** No firmware was flashed. Blocked on the USB-serial path,
not on the module. Full detail below because the failure was expensive and the
diagnosis is worth not repeating.

### Hardware configuration

- Bare ESP-12E module (2 mm pitch, hand-wired — no adapter PCB).
- Boot-pin biasing per `CONTEXT.md` §2: EN/RST/GPIO0/GPIO2 pulled up 10 kΩ,
  GPIO15 pulled down 10 kΩ.
- Powered from an ESP32 dev board's 3V3 rail (shared ground).
- Serial attempted via two adapters over the session — see below.

### What was established (evidence-backed)

| Finding | Evidence |
|---|---|
| ESP-12E is powered, resets, and boots | Onboard LED (GPIO2 = UART1 TX) flickers on every RST tap. |
| The module reached download mode at least once | An early `esptool chip_id` succeeded, before the wiring was disturbed. |
| **The PL2303 adapter is dead or counterfeit** | `bcdDevice 3.00` (PL2303HXA, discontinued 2012, heavily counterfeited). Driver binds and the port enumerates, but a loopback with its own TX shorted to its own RX returned **0 bytes on 5/5 trials**. |
| The CP2102 adapter is functional | Received a continuous stream from the attached ESP32 all session; went to **exactly 0 bytes** once the ESP32's EN was jumpered to GND. |
| ESP-12E TX never reached any adapter RX | 25 s capture at **74880 baud** (native ROM rate) across multiple RST taps: **0 bytes**. Silence, not garbage — which rules out a baud mismatch, since a wrong baud yields corrupt bytes rather than none. |

### The expensive mistake — port identity

Two USB-serial adapters were connected simultaneously:

- `/dev/ttyUSB0` — PL2303 (Prolific)
- `/dev/ttyUSB1` — CP2102 (Silicon Labs)

Which adapter served which board was misidentified **twice**, and several rounds
of rewiring were spent probing the ESP32's port while believing it was the
ESP-12E's. The ESP32 was running firmware and streaming continuously, so its
port produced endless deterministic garbage that was repeatedly misread as a
signal from the ESP-12E.

Compounding it, the ports **renumbered mid-session** when the PL2303 was
unplugged — the CP2102 moved from `ttyUSB1` to `ttyUSB0`.

**Rules adopted for future sessions:**

1. **Connect one adapter at a time.** If two must be present, identify them by
   unplugging one and observing which node disappears — before any probing.
2. **Re-check the port node after any replug.** Numbering is not stable.
3. Identify by `udevadm info -q property -n <dev> | grep ID_MODEL` and record
   the mapping in this log at the start of the session.

### Diagnostic technique worth keeping

- **Silence vs. garbage is the key discriminator.** A wrong baud rate produces
  corrupt bytes; a disconnected line produces nothing. `0 bytes` at 74880 with
  a confirmed-booting chip is proof of an open TX path, not a config error.
- **Reading the ROM banner at 74880** identifies boot mode directly
  (`boot mode:(1,x)` = UART download, `(3,x)` = flash boot). `stty` cannot set
  74880; `scratchpad/read74880.py` does it via the `TCSETS2` ioctl with
  `BOTHER`. Note the PL2303 cannot do 74880 at all; the CP2102 can.
- **Loopback with the adapter's own TX shorted to its own RX** is the cleanest
  bisect available — it tests the adapter, driver and cabling with the target
  removed entirely. Both adapters were tested this way. It is the test that
  condemned the PL2303.
- **An ESP32 dev board can serve as a USB-serial bridge** by jumpering `EN` to
  `GND`, which parks the ESP32 and frees its adapter. Verified working: the
  line went from flooded to completely silent. Non-destructive and reversible —
  nothing is flashed or erased.

### Unresolved at session end

The ESP-12E's TX (GPIO1) does not reach any adapter RX. Remaining candidates,
none yet distinguished:

- Cold or open solder joint on the module's TX pad (2 mm castellations lift
  easily; a joint can look sound while sitting on lifted copper).
- Wrong pad on the module.
- The ESP32 board's `TX0`/`RX0` header pins not being the CP2102's data lines —
  a loopback between those two header pins also returned 0 bytes, despite the
  CP2102 being known-good.

**Software probing is exhausted here.** Every remaining hypothesis is about
whether one piece of copper connects to another, which only a continuity meter
can answer. No further rewiring should be attempted blind.

### Next session — do these in order

1. **Continuity-check with a multimeter**: ESP-12E TX pad → adapter RXD pin,
   and ESP-12E RX pad → adapter TXD pin. This is the measurement that would
   have replaced most of this session.
2. **Use a purpose-built USB-TTL dongle** (genuine CH340 or CP2102). The
   ESP32-as-bridge route works but adds an `EN` jumper and header-pin ambiguity
   to a system that already had too many unknowns.
3. Only then retry §7.1 step 0.

### Cost

One full session, no firmware flashed. Root cause of the *lost time* was not
the hardware fault itself but **debugging two unknowns at once** — an
unverified serial adapter and an unverified module — with an unstable port
mapping between them. Verify the adapter alone, first, next time.

---

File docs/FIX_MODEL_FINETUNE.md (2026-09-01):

# Fine-tuning a FIX model for the pad — and why it did not ship

The rewrite menu's **FIX** style has the narrowest job on the pad: correct
spelling, grammar and punctuation in the selected text, and change *nothing
else*. It is also the style most likely to be pressed on a MAC address, a file
path or a `snake_case` identifier, where a helpful rewrite is a corruption.

That narrowness is exactly the shape a small fine-tune is supposed to win: one
task, a fixed system prompt, no need for world knowledge. So it was tried
properly — a matched sweep across two model sizes and four epoch counts, scored
against a frozen eval, with the incumbent measured first as the bar to beat.

**It lost, on one axis, and that axis is the one that decides.** The lab is in
[`../ml/`](../ml); this page is the result.

---

## The bar: the incumbent, measured

`qwen3:8b` through Ollama, 100 frozen eval cases:

| | think = on | **think = off** |
|---|---|---|
| cases scored | 83 (17 timed out at 180 s) | 100 |
| corrections | 71.6% | **79.1%** |
| spurious changes / case | 0.78 | **0.26** |
| exact match | 39.8% | **63.0%** |
| clean text left alone | 1/3 | **5/5** |
| latency median / p95 | 21.1 s / 49.8 s | **3.3 s / 4.6 s** |

**Turning reasoning off improved every axis at once** — more accurate, far more
restrained, 6× faster. Three defects belong to thinking-on specifically:

1. `/think` leaked into the *visible output* in 23 of 83 responses. That string
   would be pasted straight into the document on a FIX press.
2. 17 cases blew a 180 s timeout — three minutes to fix a typo in one sentence.
   They are excluded from the column, so the true think-on numbers are worse
   than shown: it was scored on the easier 83.
3. On `"load-dump lcamp"` (should be `clamp`) it emitted `"load-dump load-dump"`
   — a hallucinated correction, not a missed one.

> This contradicts an earlier planted-typo measurement that had reasoning
> catching 13/13 typos against 4/13 with it off. The two tests are not
> comparable — that one used a long document, this one uses 1–4 sentence
> segments — and Ollama moved a version between them. Treat neither as settled;
> `docs/REWRITE_MENU.md` still carries the older note.

So the target became **79.1% corrections at 0.26 spurious changes per case and
3.3 s** — much harder than the ~17 s figure the project was originally scoped
against, and hard enough that a fast small model is no longer obviously a win.

## The sweep

`Qwen2.5-0.5B-Instruct` and `-1.5B-Instruct`, LoRA (r=16, α=32), 4-bit, 1074
training pairs, identical data and hyperparameters across every run — only the
base model and the epoch count move.

| | ft 0.5B @2ep | ft 0.5B @6ep | ft 1.5B @2ep | **ft 1.5B @6ep** | ft 1.5B @12ep | incumbent |
|---|---|---|---|---|---|---|
| corrections | 64.1% | 69.2% | 78.6% | **82.4%** | 81.3% | 79.1% |
| **spurious / case** | 0.70 | 0.62 | 0.50 | 0.38 | 0.36 | **0.26** |
| exact match | 36.4% | 44.0% | 52.0% | 60.0% | **64.0%** | 63.0% |
| clean left alone | 3/5 | 2/5 | 3/5 | 3/5 | 3/5 | **5/5** |
| latency median | 0.82 s | 0.81 s | 1.85 s | 1.73 s | **1.64 s** | 3.3 s |
| train time | — | 8 min | 7 min | 22 min | 44 min | — |

**The best model in the project is the 1.5B at 6 epochs.** It beats the
incumbent on corrections, ties it on exact match, and is 2× faster.

### Epochs were a real lever, and the default was wrong

The shipped configs carried `epochs: 2  # 3 overfits to the corruption script's
habits`. That comment was an assumption, never measured, and it cost real
performance: going 2 → 6 improved corrections **and** spurious changes together
(+3.8 pts, −0.12), which is not what overfitting looks like on the metric even
though train loss fell to 0.0028.

Doubling again to 12 bought nothing worth 22 extra minutes. **The lever is
exhausted at ~6** — do not escalate further.

### The 0.5B is capacity-limited, not epoch-limited

Epochs move it in the same direction and it never arrives: 10 points behind the
incumbent on corrections and 2.4× its spurious rate. Its only advantage is
0.81 s median latency, and FIX does not need sub-second when the alternative is
1.7 s and considerably more accurate. **The 0.5B is out.**

## Why it still loses

The failure is not missed typos. A word-level diff of prediction against
reference buckets almost everything as **substitution** — 54 of 60 for the 1.5B:
`will`→`may`, `is`→`are`, `sits`→`weighs`, `set a DTC`→`steal DTCs`. Nothing is
truncated. The model is not failing to fix; it is **paraphrasing**.

Per defect class it has plainly learned the mechanical work:

| defect class | incumbent | ft 1.5B |
|---|---|---|
| case | 19/19 | 19/19 |
| dropped / doubled letter | 4/4 | 4/4 |
| punctuation | 32/33 | **33/33** |
| homophone / word choice | 48/60 | 48/60 |
| transposition | **39/52** | 37/52 |
| apostrophe | **1/4** | 0/4 |

So it is competitive at fixing and loses purely on **restraint**.

Three explanations were tested. Two are dead:

- **Loss masking is fine.** Verified directly on a training row — 163 of 192
  tokens masked, and the 29 in-loss tokens decode to exactly the assistant
  response. The alarming `return_assistant_tokens_mask` warning in the log is a
  preferred path falling back to a working one, not a defect.
- **Sampling noise is ruled out.** Every number above is greedy decoding —
  `score_fix.py` calls Ollama at `temperature: 0`.

The surviving explanation is the **training distribution**: 95.6% of the pairs
contain an error, so the model learns that an edit is nearly always required.
Train loss at 0.0009 means it memorised the set and *still* would not hold back,
which says the behaviour is in the data, not in the fitting.

That is the one untested fix and it is a data change, not a training change:
raise the clean-pair share from 4.4% to ~20% **in the train split only**, keep
`fix-eval.jsonl` and its hash frozen, re-run at 6 epochs.

## The verdict

**Keep `qwen3:8b` and set `"think": false` on the FIX style.**

Restraint is the ship criterion. A FIX key that misses a typo is a minor
annoyance; one that quietly rephrases your sentence is a defect you will not
notice until the text is already sent. The incumbent wins there 0.26 to 0.38 and
5/5 to 3/5, and it costs one line of JSON and no GPU.

The margin is narrow enough that this is not a dead end — the fine-tune already
wins on corrections and speed and is one dataset rebalance away from a real
decision. It is just not, today, the better FIX key.

### Caveats, in order of how much they could matter

- **The eval is 100% dense technical documentation prose.** A 6-case hand probe
  at the register FIX actually gets — short notes and messages — had both 6- and
  12-epoch models perfect: clean sentences untouched 3/3, `A4:C1:38:9F:2B:11`
  and `/srv/media/music` preserved, typos corrected to the reference exactly.
  n=6 proves nothing, which is why ~20 real-register snippets are the highest
  value outstanding item. Against that, spurious changes are broken out by input
  length in the runbook and the fine-tunes lose in **every** band including the
  shortest — so "wrong register" does not obviously rescue them.
- **`clean left alone` is n=5.** Far too small to conclude from, either way.
- Both fine-tunes are 4-bit; the bf16 configs never ran (8 GB VRAM — see the
  runbook, a 1.5B + LoRA should fit and does not, because the base loads fp32).
- Export is f16 GGUF rather than q8_0, which is the lower-error choice and so
  does not disadvantage the fine-tunes.
- Latency columns cross machines and Ollama versions. The correction and
  spurious counts are text diffs and are unaffected.

### What this machine is actually running

`~/MacroPadDeck/styles.json` currently names
`soup-macropad-fix-1.5b-4bit-e12:latest` as the **top-level** model, so every
style runs on the fine-tune, not just FIX. That was set to get the rewrite path
working end-to-end when `qwen3:8b` turned out not to be pulled — it predates
this verdict and contradicts it. Change the model back, or keep it knowingly.

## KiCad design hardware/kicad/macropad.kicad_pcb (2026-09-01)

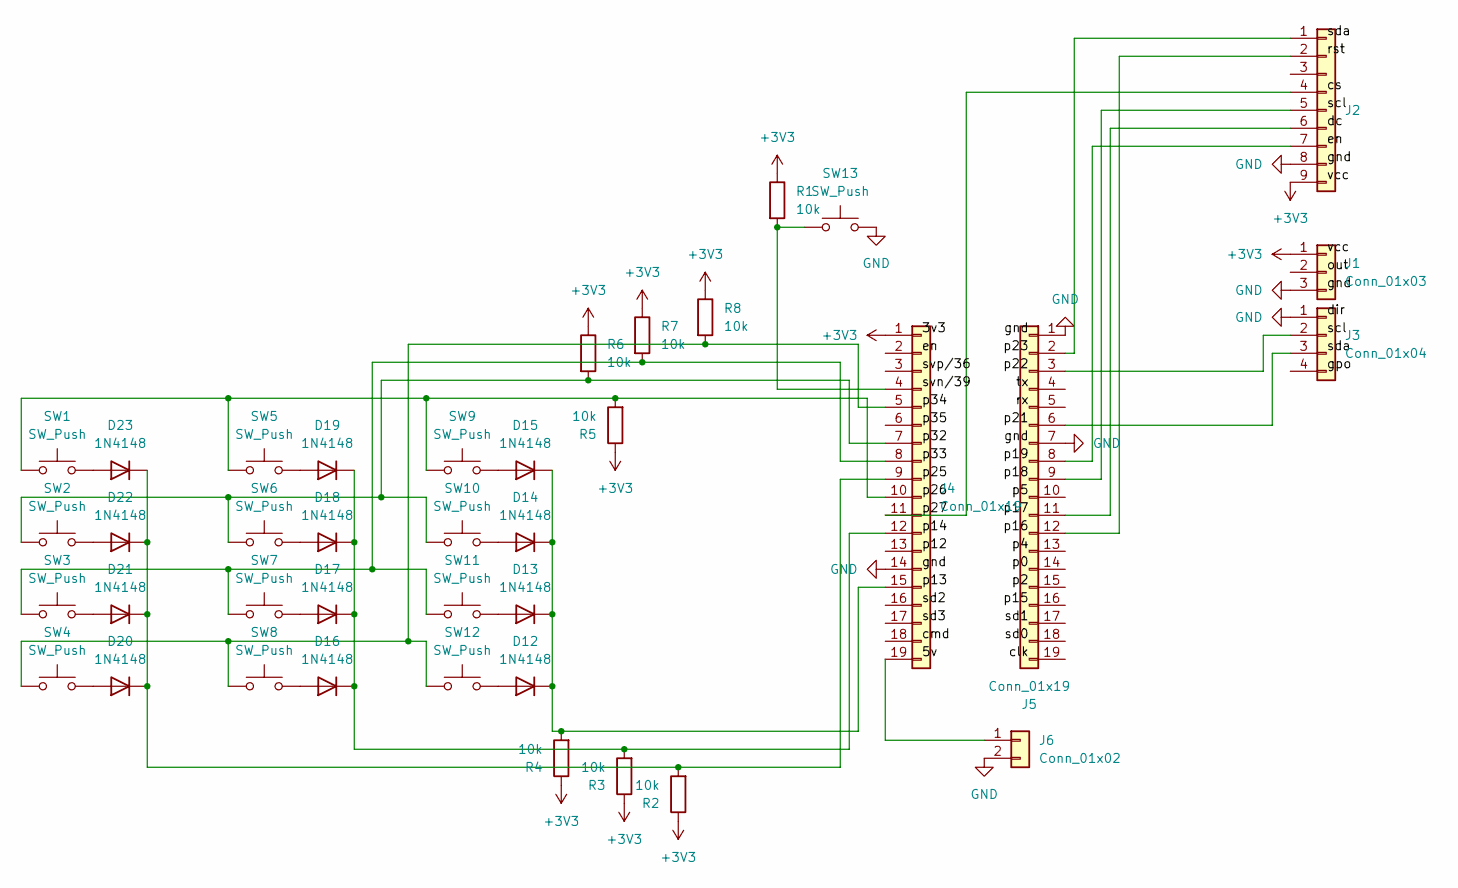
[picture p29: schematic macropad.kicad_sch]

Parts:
D12, D13, D14, D15, D16, D17, D18, D19, D20, D21, D22, D23: 1N4148; D_DO-35_SOD27_P7.62mm_Horizontal
J1: Conn_01x03; PinHeader_1x03_P2.54mm_Vertical
J2: Conn_01x09; PinHeader_1x09_P2.54mm_Vertical
J3: Conn_01x04; PinHeader_1x04_P2.54mm_Vertical
J4, J5: Conn_01x19; PinHeader_1x19_P2.54mm_Horizontal
J6: Conn_01x02; PinHeader_1x02_P2.54mm_Horizontal
R1, R2, R3, R4, R5, R6, R7, R8: 10k; R_Axial_DIN0207_L6.3mm_D2.5mm_P7.62mm_Horizontal
SW1, SW2, SW3, SW4, SW5, SW6, SW7, SW8, SW9, SW10, SW11, SW12: SW_Push; SW_Cherry_MX_1.00u_PCB
SW13: SW_Push; SW_PUSH_6mm_H4.3mm

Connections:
+3V3: J1.1, J2.9, J4.1, R1.1, R2.1, R3.1, R4.1, R5.1, R6.1, R7.1, R8.1
/p27: J2.4, J4.11
GND: J1.3, J2.8, J3.1, J4.14, J5.1, J5.7, J6.2, SW13.2
unnamed: D12.2 (A), SW12.2
unnamed: D12.1 (K), D13.1 (K), D14.1 (K), D15.1 (K), J4.15, R4.2
unnamed: D13.2 (A), SW11.2
unnamed: D14.2 (A), SW10.2
unnamed: D15.2 (A), SW9.2
unnamed: D16.2 (A), SW8.2
unnamed: D16.1 (K), D17.1 (K), D18.1 (K), D19.1 (K), J4.12, R3.2
unnamed: D17.2 (A), SW7.2
unnamed: D18.2 (A), SW6.2
unnamed: D19.2 (A), SW5.2
unnamed: D20.2 (A), SW4.2
unnamed: D20.1 (K), D21.1 (K), D22.1 (K), D23.1 (K), J4.9, R2.2
unnamed: D21.2 (A), SW3.2
unnamed: D22.2 (A), SW2.2
unnamed: D23.2 (A), SW1.2
unnamed: J2.1, J5.2
unnamed: J2.2, J5.12
unnamed: J2.5, J5.9
unnamed: J2.6, J5.11
unnamed: J2.7, J5.8
unnamed: J3.2, J5.3
unnamed: J3.3, J5.6
unnamed: J4.4, R1.2, SW13.1
unnamed: J4.5, R8.2, SW4.1, SW8.1, SW12.1
unnamed: J4.7, R6.2, SW2.1, SW6.1, SW10.1
unnamed: J4.8, R7.2, SW3.1, SW7.1, SW11.1
unnamed: J4.10, R5.2, SW1.1, SW5.1, SW9.1
unnamed: J4.19, J6.1

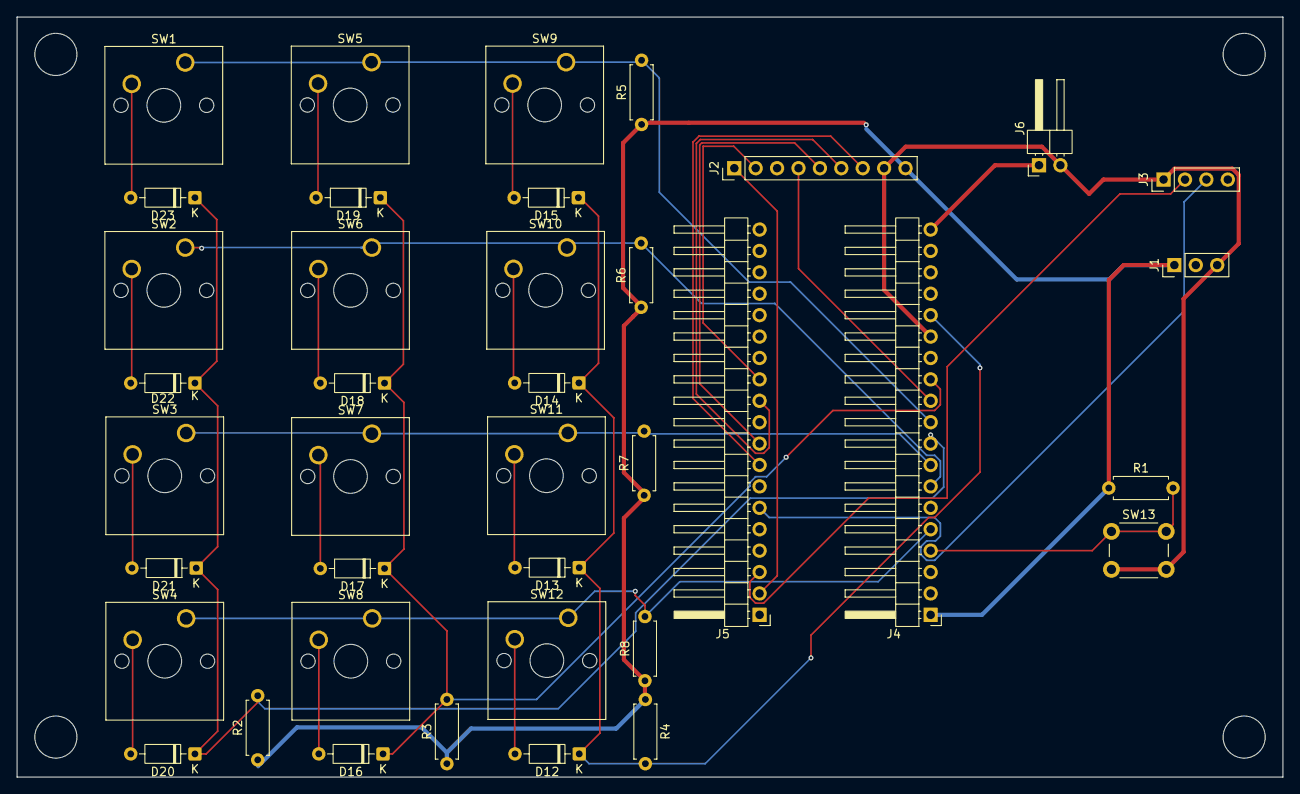
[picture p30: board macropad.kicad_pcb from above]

Board: 2 copper layers, 150.2 x 90.2 mm, 39 parts (0 on the bottom side), 31 nets.

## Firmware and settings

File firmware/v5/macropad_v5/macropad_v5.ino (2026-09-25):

/*********************************************************************
 * ESP32 BLE HID Macro Pad — v5 MULTIHOST (NimBLE)
 *
 * Hardware : NodeMCU ESP32-S V1.1 (WROOM-32, no PSRAM)
 *            ST7789 240×320 IPS, landscape mount (320×240)
 *            12× MX switches, 4×3 electrical matrix, 1N4148 diodes
 *            (AS5600 encoder puck is a separate ESP-NOW device — NOT
 *             handled by this firmware yet)
 *
 * Wiring (P-label = GPIO) — AS BUILT, verified by pairwise probe:
 *   TFT  : SCK=P18  MOSI=P23  CS=P5  DC=P21  RST=P22  BL=P19 (LEDC PWM)
 *   Matrix rows, driven LOW one at a time (top→bottom): P25 P32 P33
 *   Matrix cols, INPUT_PULLUP readers (left→right)    : P26 P14 P27 P13
 *   Diodes: cathode faces the ROW line (current col → switch → row)
 *
 * Key grid (logical, landscape, 4 wide × 3 tall):
 *   K1  K2  K3  K4        idx 0..3   = drive row d, read col j
 *   K5  K6  K7  K8        idx 4..7     maps as  idx = d*4 + j
 *   K9  K10 K11 K12       idx 8..11    (K9 = FN, bottom-left)
 *
 * ── PEBBLE-KEYS-STYLE MULTI-HOST BLE ─────────────────────────────
 *   3 host slots, each remembers one bonded device (NVS persisted).
 *   Switching re-advertises filtered to that slot's bonded host, so
 *   only the selected device reconnects — like Logitech Easy-Switch.
 *
 * ── CONTROLS ─────────────────────────────────────────────────────
 *   K9 (FN) tap          : fire its macro (like any key)
 *   K9 (FN) hold 1s      : SYSTEM menu, then while it is open:
 *       K1/K2/K3 tap     :   switch to device slot 1/2/3
 *       K1/K2/K3 hold 1.5s:  (re-)pair that slot with a new device
 *       K4               :   preset picker
 *       K8               :   settings  (brightness / sleep / OS /
 *                            devices+bond management)
 *       K12              :   BUILD mode (remap any key live)
 *       release FN       :   cancel
 *
 * Gotchas honoured (from CONTEXT.md §3 / v4 learnings):
 *   ▸ NimBLE init BEFORE ledcAttach — radio init resets LEDC
 *   ▸ BlueZ needs adv flags 0x06 rebuilt on EVERY adv restart
 *   ▸ ledcAttach again after light-sleep — LEDC silently dropped
 *   ▸ strapping pins 0/2/12/15 completely unused
 *********************************************************************/

// Network stack FIRST — TFT_eSPI (SMOOTH_FONT) includes <FS.h> and trips its
// include guard, which would hide the global `FS` alias WebServer.h needs.
#include <WiFi.h>
#include <esp_now.h>       // encoder puck link — see docs/PUCK_PROTOCOL.md
#include <esp_wifi.h>      // esp_wifi_set_channel, to pin the ESP-NOW channel
#include <esp_mac.h>       // esp_read_mac — base for the per-slot BLE addresses
#include <FS.h>
#include <SPIFFS.h>
#include <WebServer.h>
#include <Update.h>
#include <ArduinoJson.h>
#include <AnimatedGIF.h>
#include <NimBLEDevice.h>
#include <NimBLEHIDDevice.h>
#include <TFT_eSPI.h>
#include <SPI.h>
#include <Preferences.h>
#include <driver/gpio.h>

// ════════════════════════════════════════════════
//  CONFIG / OTA — versioned contract for the companion app
//  Config Mode (Settings → CONFIG) suspends BLE, raises a SoftAP web
//  server exposing a JSON config API + firmware upload. WiFi and BLE
//  never run at once (WROOM-32 coexistence is unstable), so entering
//  and leaving Config Mode both go through a clean reboot.
// ════════════════════════════════════════════════
#define FW_VERSION   "v5-multihost"
#define CONFIG_API   3            // bump when the JSON schema changes
#define AP_SSID      "MacroPad-Setup"
#define AP_PASS      "macropad123" // WPA2 needs >=8 chars; changeable via API
#define AP_IP_STR    "192.168.4.1"

// ════════════════════════════════════════════════
//  PALETTE (RGB565)
// ════════════════════════════════════════════════
#define C_BG       0x0841
#define C_SURF     0x10A3
#define C_SURF2    0x18E6
#define C_BORDER   0x2965
#define C_DIM      0x4A69
#define C_WHITE    0xFFFF
#define C_CYAN     0x07FF
#define C_AMBER    0xFD20
#define C_MAGENTA  0xF81F
#define C_GREEN    0x07E0
#define C_RED      0xF800
#define C_YELLOW   0xFFE0
#define C_PINK     0xFBB7
#define C_LTBLUE   0x3D9F
#define C_ORANGE   0xFC60
#define C_BUILD    0x9F1F

// RAM (not const): the companion app may recolor presets live over the
// host-link (HCMD_COLOR). Not persisted — the app re-pushes every session.
uint16_t PRESET_COLORS[8] = {
  C_CYAN, C_GREEN, C_AMBER, C_MAGENTA,
  C_ORANGE, C_LTBLUE, C_PINK, C_YELLOW,
};

// ════════════════════════════════════════════════
//  PINS  (NodeMCU ESP32-S V1.1 — see header)
// ════════════════════════════════════════════════
#define TFT_BL 19
// AS-BUILT wiring (verified with pairwise diagnostic 2026-07-20):
// 3 physical rows are the DRIVEN lines (diode cathodes face them),
// 4 physical columns are the READ lines. Key idx = row*4 + col.
const uint8_t DRIVE_PINS[3] = {25, 32, 33};     // rows top→bottom, driven LOW
const uint8_t READ_PINS[4]  = {26, 14, 27, 13}; // cols left→right, INPUT_PULLUP

#define NUM_KEYS   12
#define KEY_FN      8          // bottom-left key (K9)

// ════════════════════════════════════════════════
//  KEY MODEL  (defined up here so Arduino's auto-generated prototypes,
//  inserted before the first function, can see these types)
// ════════════════════════════════════════════════
// Rich key model. `type` defaults to KA_BUILTIN (0) so the existing
// aggregate initializers {"Label", A_ID} still compile and behave exactly
// as before — everything past `id` zero-initializes.
enum KAType : uint8_t {
  KA_BUILTIN = 0,   // fire ACTION_LIB entry `id` (OS-layout aware)
  KA_KEY,           // single chord: mod + key
  KA_CONSUMER,      // single media/consumer usage code
  KA_MACRO,         // ordered sequence of chord steps with delays
  KA_TEXT,          // type an ASCII string
  KA_HOST,          // notify the companion app over GATT (mod/key = HID
                    // fallback chord for when no app is listening)
};

#define MACRO_MAX 6
struct MacroStep {
  uint8_t  mod;       // modifier bitmap (0 if this step is a consumer)
  uint8_t  key;       // HID keycode  (0 => use `consumer`)
  uint16_t consumer;  // consumer usage (used when key==0)
  uint8_t  delayCs;   // post-step delay in centiseconds (×10ms)
};

struct KeyAction {
  char      label[9];
  int16_t   id;                 // KA_BUILTIN action id
  uint8_t   type;               // KAType
  uint8_t   mod;                // KA_KEY
  uint8_t   key;                // KA_KEY
  uint16_t  consumer;           // KA_CONSUMER
  uint8_t   nSteps;             // KA_MACRO step count
  MacroStep steps[MACRO_MAX];   // KA_MACRO
  char      text[24];           // KA_TEXT
};
struct Preset    { char name[10]; KeyAction keys[NUM_KEYS]; };

// ════════════════════════════════════════════════
//  TUNING
// ════════════════════════════════════════════════
int           backlightBrightness = 180;
unsigned long sleepTimeoutMs      = 300000UL;   // 0 = no sleep
bool          linuxLayout         = false;      // false=Windows, true=Linux

const uint16_t KEY_DEBOUNCE_MS   = 25;   // raised: bench keys were sticking
const uint16_t KEY_SCAN_INTERVAL_MS = 5; // fixed scan cadence, not every loop

// ── FACE / screensaver ──────────────────────────
// faceMode:  0=OFF  1=IDLE (screensaver after idle)  2=ALWAYS (default view)
// faceStyle: 0=procedural robot eyes  1=uploaded GIF loop (falls back to eyes)
uint8_t faceMode  = 1;
uint8_t faceStyle = 0;
char    faceGif[32] = "";                 // selected SPIFFS path, e.g. "/idle.gif"
// IDLE threshold comes from faceCfg.idleS (configurable, default 12s).
const unsigned long FACE_ALWAYS_MS = 2000;  // ALWAYS: return to face after this

// Expression pack — every visual parameter of the eyes, uploadable as JSON
// via the config API so the companion app can "generate" personalities.
struct FaceCfg {
  uint16_t color;        // RGB565 eye color; 0 = follow active preset color
  uint8_t  eyeW, eyeH;   // eye size at rest (px)
  uint8_t  gap;          // horizontal gap between the eyes (px)
  uint8_t  rnd;          // corner radius (px)
  uint8_t  blinkMinS, blinkMaxS;    // idle blink interval range (seconds)
  uint8_t  glanceMinS, glanceMaxS;  // idle glance interval range (seconds)
  uint8_t  pairScalePct; // pairing-mode wide-eye width scale (percent)
  uint8_t  idleS;        // IDLE mode: seconds of no input before face shows
  uint8_t  mouthOn;      // 0 = eyes only (the original look)
  uint8_t  mouthW;       // mouth width at rest (px)
  uint8_t  mouthThick;   // stroke thickness (px)
};
// color 0x3DFF = robotic blue (#3ABEFF) — the default face. Set to 0 to
// follow the active preset's accent instead (app: "match preset").
FaceCfg faceCfg = { 0x3DFF, 64, 84, 44, 18, 3, 6, 7, 15, 115, 12, 1, 76, 6 };

// ── Personality ─────────────────────────────────
// One renderable posture. Everything the face can express reduces to these
// eight numbers, so emote keyframes, persona resting poses and the mood
// engine all speak the same language and can be blended by the frame loop.
struct EyePose {
  uint8_t openPct;      // 0-100 lid opening (scales eyeH)
  uint8_t lidTopPct;    // 0-100 top lid coverage — sleepy/heavy when high
  int8_t  lidTopAngle;  // -100..100: + outer-deep (sad), - inner-deep (angry)
  uint8_t lidBotPct;    // 0-100 bottom crescent — the happy squint
  uint8_t wPct, hPct;   // eye size scale, 100 = rest (surprised goes ~115)
  int8_t  gx, gy;       // glance bias (px)
  // ── Mouth ── deliberately appended last: every existing keyframe table
  // uses aggregate init, so older rows zero-fill these and keep working.
  uint8_t mouthWPct;    // width scale; 0 means "default" (=100), not "hidden"
  int8_t  mouthCurve;   // -100 frown … 0 flat … +100 smile
  uint8_t mouthOpenPct; // 0 = closed line, 100 = fully open (yawn, gasp)
  // ── Brows ── appended after the mouth for the same reason: rows written
  // before brows existed zero-fill to a level brow at rest height.
  int8_t  browY;        // -100 lowered … 0 rest … +100 raised (surprise)
  int8_t  browTilt;     // + inner end down (angry), − inner end up (worried)
};
const EyePose POSE_NEUTRAL = { 100, 0, 0, 0, 100, 100, 0, 0, 100, 0, 0, 0, 0 };

// ── Face v3 types ───────────────────────────────
// Declared up here, before any function, so the Arduino prototype generator
// never emits a prototype that names a type it hasn't seen yet.
//
// One visor face. Eyes and mouth are signed-distance shapes whose every
// number is spring-driven, so any expression morphs into any other. The
// browser reference firmware/v5/tools/face-preview.html runs the same maths:
// tune there, and keep EXPR / EMOTES / MOOD_GRID here identical to it.
struct EyeP   { float w, h, r, lidT, lidA, lidB, cres, heart, hollow, dx, dy; };
struct MouthP { float mw, curve, thick, open, depth, wedge, skew, round, rO, my; };
struct FaceP  { EyeP L, R; MouthP m; };          // floats only: springs walk it as an array
struct FaceXf { float tx, ty, sx, sy, rot; };    // whole-face transform (dance, emote motion)
struct FRect  { int16_t x0, y0, x1, y1; };       // sprite-space dirty rect, x1 < x0 = empty
typedef float (*SdfFn)(float x, float y, const void* ctx);
struct EyeCtx   { const EyeP* e; float cx, cy, inner, blink; };
struct MouthCtx { const MouthP* m; float cx, cy; };
struct ZCtx     { float zx, zy, sz, a; };

// Expression ids — also the emote ids on the wire (HCMD_EMOTE, emote map)
enum : uint8_t { EX_NEUTRAL, EX_HAPPY, EX_JOY, EX_LOVE, EX_SURPRISED, EX_ANGRY, EX_SAD,
                 EX_TIRED, EX_SLEEPY, EX_FOCUSED, EX_WINK, EX_SKEPTICAL, EX_VIBING,
                 EX_DIZZY, EX_COUNT };
#define EMOTE_RANDOM 0xFF                 // map entry: pick a flair emote at random

// Pad-side triggers: events the pad sees itself, so they work with no PC.
// Host-side ones (drop, game/code app, late night) live in the companion and
// arrive as HCMD_EMOTE. Order is wire format — append only.
enum : uint8_t { TRG_BOOT, TRG_CONNECT, TRG_DISCONNECT, TRG_TYPING, TRG_IDLE, TRG_WAKE,
                 TRG_PRESET, TRG_SLOT, TRG_TRACK, TRG_FAVE, TRG_PAUSE, TRG_FLAIR,
                 TRG_PAD_N };
struct EmoteMapE { uint8_t ex, chance, cooldownS; };   // chance 0 = off
// NVS "emap" (whole table), written only when the companion's editor saves
EmoteMapE emoteMap[TRG_PAD_N] = {
  { EX_HAPPY,     100,   0 },   // boot
  { EX_HAPPY,     100,   5 },   // connect
  { EX_SAD,       100,   5 },   // disconnect
  { EX_FOCUSED,    60,  20 },   // typing burst
  { EX_SLEEPY,     60, 120 },   // idle (≥ 60 s untouched)
  { EX_SURPRISED, 100,   0 },   // wake press
  { EX_WINK,       70,  10 },   // preset picked on the pad
  { EX_WINK,      100,   0 },   // host slot switch
  { EX_SURPRISED,  80,  20 },   // new track
  { EX_LOVE,      100,   0 },   // favourited
  { EX_NEUTRAL,     0,  30 },   // paused
  { EMOTE_RANDOM,  70,   0 },   // dance flair
};
uint8_t danceLevel = 60;          // NVS "dlvl": 0 off, ~30 bob only, 100 full party
uint8_t flairBars  = 8;           // NVS "dflr": bars between flair chances, 0 = never
#define FACE_CAPS 0x80            // hello byte 6: face v3 engine (emote/map/dance cmds)
#ifndef FACE_PROFILE              // -DFACE_PROFILE=1: log worst updateFace time + mood every 5 s
#define FACE_PROFILE 0
#endif

// Persona = a tuning table. Percentages scale the faceCfg intervals and the
// emote amplitudes, so one enum changes how the whole face carries itself.
struct Personality {
  char    name[8];
  uint8_t blinkPct, glancePct;              // 100 = faceCfg timings as-is
  uint8_t emotePct;                         // emote amplitude scale
  uint8_t timePct;                          // emote playback stretch (100 = as written)
  uint8_t saccadePct, dblBlinkPct, yawnPct; // micro-behaviour likelihoods
  uint8_t squintPct;                        // idle thoughtful-squint likelihood
  int8_t  energyBias, valenceBias;          // resting mood offsets (-100..100)
  EyePose rest;                             // posture with nothing happening
};
const Personality PERSONAS[] = {
  // After the eye fields: mouth width%, curve, open%; then brow height, tilt.
  // timePct stretches emote playback per persona, on top of EMOTE_TIME_PCT.
  // name      blink glance emote time sacc dbl yawn sqnt  eBias vBias  rest pose
  { "CALM",     120,  110,   70, 105,   30,  10,  15,  20,   -10,   10, { 100,  8,   0,  0, 100, 100, 0, 0, 100,  18, 0,   0,   0 } },
  { "PLAYFUL",   70,   60,  130,  85,  100,  40,  10,  25,    25,   25, { 100,  0,   0,  8, 100, 100, 0, 0, 106,  46, 0,  12,   0 } },
  { "GRUMPY",   140,  130,   60, 115,   20,   5,   5,  50,   -15,  -30, {  92, 18, -35,  0, 100, 100, 0, 0,  88, -40, 0, -10,  45 } },
  { "SLEEPY",   170,  150,   50, 145,   15,  10,  60,  30,   -40,    0, {  80, 35,  20,  0, 100,  96, 0, 2,  84,  -8, 0, -15,   0 } },
};
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
void loop() {
  unsigned long now = millis();

  // ── Config Mode: WiFi/HTTP only, BLE is torn down ──
  // Hold FN (K9) ~1.5s to leave and reboot back into keyboard mode.
  if (configMode) {
    server.handleClient();
    static unsigned long fnDown = 0;
    bool fn = (scanMatrixRaw() >> KEY_FN) & 1;
    if (fn) { if (fnDown == 0) fnDown = now; else if (now - fnDown > 1500) ESP.restart(); }
    else fnDown = 0;
    delay(2);
    return;
  }

  // Companion-app link: hello + queued commands (loop owns the TFT)
  hostLinkTick();

  // Encoder puck: drain the ESP-NOW mailbox (loop owns the TFT + NimBLE)
  puckTick();

  // BLE events from callback context → UI feedback (loop owns the TFT)
  if (pendingBleEvent != EVT_NONE) {
    uint8_t evt = pendingBleEvent;
    pendingBleEvent = EVT_NONE;
    if (evt == EVT_PAIRED) {
      char msg[24];
      snprintf(msg, sizeof(msg), "PAIRED SLOT %d", activeSlot + 1);
      redraw();
      showToast(msg, C_GREEN, 1500);
    }
  }
  if (pendingBondSnap >= 0) {
    int n = pendingBondSnap;
    pendingBondSnap = -1;
    snapshotSlotBond(n);
  }

  // Connection state change → redraw (+ fire buffered wake-key)
  if (bleConnected != lastBleConn) {
    lastBleConn = bleConnected;
    // The face reacts to the link coming and going — queued, so it plays
    // whether the event lands on the grid or with the eyes already up
    if (bleConnected) { faceTrigger(TRG_CONNECT); moodValence = min(1.0f, moodValence + 0.20f); }
    else              { faceTrigger(TRG_DISCONNECT); moodValence = max(0.0f, moodValence - 0.25f); }
    if (bleConnected) {
      if (wakeKeyPending && wakeKeyIdx != WAKEKEY_NONE) {
        wakeKeyPending = false;
        delay(150);
        lastFlashKey = wakeKeyIdx; flashUntil = now + FLASH_MS;
        drawMain();
        fireKeyAction(presets[activePreset].keys[wakeKeyIdx], wakeKeyIdx);
        wakeKeyIdx = WAKEKEY_NONE;
      } else redraw();
    } else {
      if (wakeKeyPending && wakeKeyIdx != WAKEKEY_NONE)
        drawReconnectHUD(presets[activePreset].keys[wakeKeyIdx].label);
      else redraw();
    }
  }

  // Pairing-state change (from BLE callbacks) → status bar refresh
  if (pairingMode != lastPairingUi) {
    lastPairingUi = pairingMode;
    if (currentScreen == SCR_MAIN || currentScreen == SCR_DEVICES) redraw();
  }

  // Reconnect HUD animation + timeout
  if (!bleConnected && wakeKeyPending && wakeKeyIdx != WAKEKEY_NONE) {
    static unsigned long lastHud = 0;
    if (now - lastHud > 400) {
      lastHud = now;
      if (now - wakeTimeMs < RECONNECT_TIMEOUT_MS)
        drawReconnectHUD(presets[activePreset].keys[wakeKeyIdx].label);
      else { wakeKeyPending = false; wakeKeyIdx = WAKEKEY_NONE; redraw(); }
    }
  }

  // Toast expiry
  if (toastUntil != 0 && now >= toastUntil) { toastUntil = 0; redraw(); }

  // Key flash expiry
  if (lastFlashKey >= 0 && now >= flashUntil) {
    int k = lastFlashKey; lastFlashKey = -1;
    if (currentScreen == SCR_MAIN) {
      KeyAction& ka = presets[activePreset].keys[k];
      // kaEmpty, not id==A_NONE: rich key types (host/key/text/…) all have
      // id 0 — the old test blanked their cells after every flash
      if (kaEmpty(ka)) drawCellEmpty(k);
      else drawCell(k, ka.label, nullptr, PRESET_COLORS[activePreset], false);
    }
  }

  // ── Matrix scan with per-key debounce + tap/hold events ──
  // Fixed cadence: scanning every loop pass made keys feel sticky on the
  // bench; 5ms polling + 25ms debounce filters contact bounce cleanly
  static unsigned long lastScanMs = 0;
  if (now - lastScanMs < KEY_SCAN_INTERVAL_MS) { maybeEnterSleep(); delay(1); return; }
  lastScanMs = now;
  uint16_t raw = scanMatrixRaw();
  static uint16_t lastRawDbg = 0;
  if (raw != lastRawDbg) {           // bench debug: print electrical position
    for (int d = 0; d < 3; d++) for (int j = 0; j < 4; j++) {
      uint16_t m = 1u << (d * 4 + j);
      if ((raw & m) && !(lastRawDbg & m))
        Serial.printf("[MX] DOWN row=P%d col=P%d  -> key idx %d\n",
                      DRIVE_PINS[d], READ_PINS[j], d * 4 + j);
    }
    lastRawDbg = raw;
  }
  for (int i = 0; i < NUM_KEYS; i++) {
    bool r = (raw >> i) & 1;
    if (r != keyRaw[i]) { keyRaw[i] = r; keyChangeMs[i] = now; }
    if ((now - keyChangeMs[i]) >= KEY_DEBOUNCE_MS && r != keyStable[i]) {
      keyStable[i] = r;
      if (r) {
        keyDownMs[i] = now;
        keyHoldFired[i] = false;
        recordActivity();
        // Typing burst → the face gets visibly excited and stays perkier
        if (moodKeyCount < 255) moodKeyCount++;
        if (now - typeBurstStart > 4000) { typeBurstStart = now; typeBurstCount = 0; }
        if (++typeBurstCount == 5) {
          faceTrigger(TRG_TYPING);
          moodEnergy = min(1.0f, moodEnergy + 0.15f);
        }
        // IDLE: the face is a screensaver — the first press only wakes it
        // (consumed, never typed) and hands the grid back.
        if (currentScreen == SCR_FACE && faceMode != 2) {
          keyFiredOnDown[i] = true;
          faceGifStop();
          if (faceStyle == 0) faceWake();       // happy squint flash
          else screenDirty = true;
          currentScreen = SCR_MAIN;
          drawMain();
          Serial.printf("[FACE] wake by K%d (mode=%d)\n", i + 1, faceMode);
        }
        // ALWAYS mode and the grid share one path: the face is just the
        // main screen wearing a different skin, so keys keep full tap/hold
        // semantics and ALWAYS never bounces through the grid to type.
        // Instant fire on press for keys with no hold action on this
        // screen — firing on release made keys feel laggy ("hanging")
        else if (holdThresholdFor(i) == 0) {
          keyFiredOnDown[i] = true;
          onKeyTap(i);
        } else keyFiredOnDown[i] = false;
      } else {
        onKeyUp(i, now - keyDownMs[i]);
      }
    }
    // In-flight hold detection (FN menu, slot pairing, bond wipe)
    if (keyStable[i] && !keyHoldFired[i]) {
      unsigned long th = holdThresholdFor(i);
      if (th != 0 && (now - keyDownMs[i]) >= th) {
        keyHoldFired[i] = true;
        onKeyHold(i);
      }
    }
  }

  // ── Face: idle entry + animation tick ──
  if (faceMode != 0 && currentScreen == SCR_MAIN &&
      toastUntil == 0 && !wakeKeyPending && lastFlashKey < 0) {
    unsigned long th = (faceMode == 2) ? FACE_ALWAYS_MS
                                       : (unsigned long)faceCfg.idleS * 1000UL;
    // MUST be a fresh millis(): recordActivity() may have run later in this
    // very pass than the loop-top `now`, and unsigned (now - lastActivityMs)
    // would wrap to ~4e9 → face re-entered on the same pass as the wake press
    if (millis() - lastActivityMs > th) {
      Serial.println("[FACE] enter");
      currentScreen = SCR_FACE; faceEnter();
    }
  }
  if (currentScreen == SCR_FACE) {
    if (faceStyle == 1) faceGifTick(now);
    else {
      updateFace(now);
      puckLabelTick(now);       // dial mode above the eyes, while the puck is up
      mediaStripTick(now);      // now-playing title + timeline under the eyes
    }
  }

  maybeEnterSleep();
  delay(3);
}

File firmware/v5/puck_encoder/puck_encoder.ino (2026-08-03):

/*********************************************************************
 * Encoder Puck — AS5600 + SSD1306 OLED, ESP-NOW sender for MacroPad v5
 *
 * A standalone wireless knob. Rotation and button gestures go to the pad
 * over ESP-NOW; the pad turns them into BLE HID. The puck never pairs
 * with a computer itself.
 *
 * Hardware : ESP32-C3 SuperMini  (or ESP32-S3 mini — see BOARD below)
 *            AS5600 magnetic encoder on I2C, addr 0x36
 *            SSD1306 128x64 OLED  on I2C, addr 0x3C  (same bus)
 *            Momentary button to GND
 *
 * Wiring (C3 SuperMini defaults — change the PIN block for other boards):
 *   AS5600  SDA -> GPIO5    SCL -> GPIO6    VCC -> 3V3   GND -> GND
 *   OLED    SDA -> GPIO5    SCL -> GPIO6    VCC -> 3V3   GND -> GND
 *   Button  one leg -> GPIO4, other leg -> GND   (internal pullup, active LOW)
 *
 *   Both I2C devices share one bus — different addresses, no conflict.
 *   The AS5600 needs a diametrically magnetised magnet 0.5-3mm above the
 *   chip, centred on it. A radially magnetised magnet reads as noise.
 *
 * Controls:
 *   Rotate         mode-dependent (volume / scroll / zoom)
 *   Short click    play / pause
 *   Double click   next track
 *   Long press     cycle mode
 *
 * Protocol : docs/PUCK_PROTOCOL.md  — read that before changing PuckMsg
 *
 * Libraries: Adafruit_SSD1306, Adafruit_GFX, Wire, esp_now, WiFi (all stock)
 *
 * Build:
 *   arduino-cli compile --fqbn esp32:esp32:esp32c3 \
 *     --libraries C:/Users/gsaip/Documents/Arduino/libraries \
 *     firmware/v5/puck_encoder
 *********************************************************************/

#include <Wire.h>
#include <WiFi.h>
#include <esp_now.h>
#include <esp_wifi.h>
#include <esp_sleep.h>
#include <WebServer.h>
#include <Update.h>

// The OLED was removed from this build (the design is dial-only now). Set to 1
// and rewire SDA/SCL to bring it back — all the drawing code is still here,
// just compiled out. Leaving it off also buys ~35 KB of flash, which is what
// makes room for the OTA web server below.
#define PUCK_OLED 0

#if PUCK_OLED
  #include <Adafruit_GFX.h>
  #include <Adafruit_SSD1306.h>
#endif

// ── Board select ─────────────────────────────────────────────────────
// 0 = ESP32-C3 SuperMini, 1 = ESP32-S3 mini (Lolin S3 Mini pin numbering)
#define BOARD_C3   0
#define BOARD_S3   1
#define BOARD      BOARD_C3

#if BOARD == BOARD_C3
  // NOT the Arduino default 8/9: on the C3, GPIO2/8/9 are strapping pins, and
  // on the SuperMini GPIO8 also drives the onboard LED (which sits across the
  // rail as a stray pullup). 5/6/4 are plain GPIOs with none of that.
  #define PIN_SDA   5
  #define PIN_SCL   6
  #define PIN_BTN   4
#else
  // Lolin S3 Mini breaks out I2C on 35/36. A generic S3 devkit uses 8/9 —
  // if the OLED never appears, this block is the first thing to check.
  #define PIN_SDA   35
  #define PIN_SCL   36
  #define PIN_BTN   2
#endif

// ── Pad's station MAC ────────────────────────────────────────────────
// The v5 bench board. NOT the BLE address (which is this + 2) — see the
// pairing section of docs/PUCK_PROTOCOL.md.
static uint8_t PAD_MAC[6] = { 0x84, 0x1F, 0xE8, 0x2B, 0x33, 0x48 };

#define PUCK_WIFI_CHANNEL 1

// WiFi TX power, in quarter-dBm (esp_wifi_set_max_tx_power's unit). 44 = 11 dBm
// against a 20 dBm default. The puck sits a metre or two from the pad, so the
// extra 9 dB buys nothing but current: full power peaks around 335 mA, which
// overruns a 250-300 mA LDO and shows up as random brownout resets during
// transmission — a fault that reads like a firmware bug and wastes a day.
// Raise it if the link ever gets unreliable at range.
#define PUCK_TX_POWER_QDBM 44

// Which way the knob counts. Depends purely on how the magnet ends up facing
// once the dial is assembled, so it is a build-time property of the physical
// puck, not a preference. 1 = reverse the sense of rotation.
//
// The AS5600 also has a hardware DIR pin for this (tie to GND or VCC), but the
// SuperMini wiring leaves it grounded, so flipping it in firmware avoids
// touching the board.
// Verified on the assembled dial 2026-08-02: 0 is the correct sense.
#define PUCK_DIR_INVERT 0

// ════════════════════════════════════════════════════════════════════
//  WIRE PROTOCOL — KEEP IN SYNC with macropad_v5.ino and PUCK_PROTOCOL.md
// ════════════════════════════════════════════════════════════════════
// v2 added the volume byte and moved mode ownership to the pad.
// v3 added the sensitivity bytes and PK_OTA, so the pad owns dial feel too.
// v3 is NOT wire-compatible with v2 — the struct grew. Flash both ends.
#define PUCK_PROTO_VER 3

#define PK_HELLO  0x01   // puck -> pad, boot + idle heartbeat
#define PK_INPUT  0x02   // puck -> pad, rotation and/or button
#define PK_STATE  0x03   // pad  -> puck, authoritative mode + volume + flags
#define PK_OTA    0x04   // pad  -> puck, drop ESP-NOW and raise the OTA SoftAP

#define PM_VOLUME 0
#define PM_SCROLL 1
#define PM_ZOOM   2
#define PM_COUNT  3

#define BTN_NONE   0
#define BTN_SHORT  1
#define BTN_DOUBLE 2
#define BTN_LONG   3

#define PF_BLE_UP     0x01   // pad's BLE link is connected
#define PF_SCROLL_OK  0x02   // pad has mouse HID compiled in
#define PF_DISABLED   0x04   // pad has the puck switched off in Settings
#define PF_VOL_KNOWN  0x08   // vol byte is real (companion app is feeding it)
#define PF_VOL_MUTED  0x10
// A dozing puck has its radio off and will miss a one-shot PK_OTA entirely, so
// the pad also latches the request into every PK_STATE. The puck picks it up on
// the next keepalive burst — worst case DOZE_HELLO_MS away.
#define PF_OTA_PEND   0x20

#define PUCK_VOL_UNKNOWN 0xFF

struct PuckMsg {
  uint8_t ver;
  uint8_t type;
  uint8_t mode;    // puck->pad: ignored. pad->puck: authoritative mode.
  int8_t  ticks;
  uint8_t btn;
  uint8_t flags;
  uint8_t vol;     // pad->puck: 0-100, or PUCK_VOL_UNKNOWN
  uint8_t speed;   // v3, pad->puck: detents per revolution, PUCK_SPEED_MIN..MAX
  uint8_t accel;   // v3, pad->puck: acceleration cap, 1 = off
};
// ════════════════════════════════════════════════════════════════════

// Sensitivity is expressed on the wire as **detents per revolution**, not as a
// raw threshold. That is the number a human can reason about ("one turn = 50
// clicks"), it fits a byte across the whole useful range, and it keeps the
// AS5600's 4096-count resolution an implementation detail of this file.
#define PUCK_CPR         4096          // AS5600 counts per revolution
#define PUCK_SPEED_MIN   8             // very slow — 8 clicks per full turn
#define PUCK_SPEED_MAX   128           // very fast — a click every 2.8 degrees
#define PUCK_SPEED_DEF   50            // ~one full volume sweep per revolution
#define PUCK_ACCEL_MIN   1             // 1 = acceleration off
#define PUCK_ACCEL_MAX   8
#define PUCK_ACCEL_DEF   4
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

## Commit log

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2026-07-19 v5: multi-host BLE firmware for new 4x3 landscape wiring
    Rewrite macropad_v5.ino for the re-pinned NodeMCU ESP32-S board:
    - 3-slot multi-host BLE (Logitech Easy-Switch style): per-slot bonds in
    NVS, accept-list filtered advertising per active slot, software
    rejection of wrong hosts, pairing mode via slot-key hold
    - New pinout: matrix rows 25/26/27/32 (driven), cols 33/13/14 (pullup);
    ST7789 on SCK18/MOSI23/CS5/DC21/RST22/BL19 - zero strapping pins
    - 4x3 matrix scan (hi-Z idle rows, per-key debounce, tap/hold events)
    replaces the 8 discrete buttons; FN key (K9) hold opens system menu
    - ST7789 320x240 landscape UI, direct drawing + small sprites only;
    status bar shows slot chips lik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
    [macropad_v5.ino]
2026-07-19 docs: bench board needs 40MHz flash freq + 115200 upload
    Boya flash (mfr 0x68) on this NodeMCU-32S crash-loops the 2nd-stage
    bootloader at the default 80MHz. Screen must be off 5V rail during
    flashing (rail sag kills flash writes).
2026-07-20 v5: WiFi Config Mode + OTA, rich key model, as-built matrix fixes
    Config Mode (Settings -> CONFIG): suspends BLE, raises a WiFi SoftAP
    (MacroPad-Setup / 192.168.4.1) serving a JSON config API + built-in web
    UI + OTA firmware upload. WiFi and BLE never run at once; entering and
    leaving Config Mode both reboot cleanly. Partition switched to min_spiffs
    (1.9MB dual OTA slots) and board FQBN to esp32:esp32:esp32 so OTA fits and
    future updates are wireless. Firmware now 1.29MB (65%).
    Rich key model - every key can be a built-in action, an arbitrary
    modifier+keycode chord, a media/consumer code, a typed ASCII string, or a
    multi-step macro. Backward-compatible aggregate initializers preserved.
    New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
    [macropad_v5.ino]
2026-07-20 v5: fix BLE reconnect after reboot + robust OTA upload
    Reconnection: advertise OPEN for bonded slots instead of whitelist-
    filtered. Controller accept-list advertising silently rejects a bonded
    host that reconnects from a Resolvable Private Address (phones + Windows
    default to RPAs), so after a reboot the device would only connect when
    forced back into open pairing. Easy-Switch is still enforced in software
    (onAuthenticationComplete disconnects a host that belongs to a different
    slot); a host that doesn't resolve to a known slot is now kept rather
    than wrongly rejected.
    OTA: the upload callback no longer does a full-screen SPI redraw per
    64KB chunk — that starved the TCP receive path and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
    [macropad_v5.ino]
2026-07-20 v5: stop screen stutter on refresh
    Every redraw called tft.fillScreen(), wiping 320x240 over SPI to black
    and then repainting all 12 cells one at a time - a visible flash-and-
    repaint stutter on any refresh (BLE connect/disconnect, pairing change,
    toast expiry). The cell and status-bar sprites already overwrite their
    own rectangles, so the clear is only needed when the layout actually
    changes.
    beginDraw(screenId) now clears only on a real screen transition, or when
    an overlay (toast / reconnect HUD) marked the screen dirty. Same-screen
    refreshes just re-push the sprites - no flash. The brightness/sleep
    editor clears its number band explicitly so a shorter value can't leave
    ghost digits, and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
    [macropad_v5.ino]
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2026-07-20 v5: fix face wake-press re-entry, make IDLE threshold configurable
    recordActivity() runs later in the same loop pass than the loop-top `now`,
    so the unsigned (now - lastActivityMs) in the face-entry check and the
    pre-sleep droop wrapped to ~4e9 and the face re-entered on the wake press.
    Both sites now read a fresh millis().
    FACE_IDLE_MS is replaced by faceCfg.idleS (3-120s, default 12) so the idle
    threshold ships in the expression pack and over the config API.
    [macropad_v5.ino]
2026-07-20 v5: ALWAYS-mode face types directly, with real tap/hold semantics
    Two bugs in ALWAYS mode. The face key-down path fired onKeyTap() on press
    unconditionally, so holding FN typed FN's tap action before the in-flight
    hold detector opened the menu. And every press exited to SCR_MAIN +
    drawMain() with the face re-entering 2s later, flashing the grid on each
    keystroke.
    ALWAYS mode now treats the face as the main screen: it shares the grid's
    key path (holdThresholdFor gains a SCR_FACE case mirroring SCR_MAIN), and
    onKeyTap/onKeyHold gain SCR_FACE cases that fire the preset action and open
    the FN menu without leaving the face. IDLE mode keeps its screensaver
    semantics — first press wakes, consume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
    [macropad_v5.ino]
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2026-07-20 v5: fix face layering — glance targets, saccade drift, emote stomping
    Three defects in the new personality layers, all found by reading the frame
    order back rather than on hardware.
    The resting pose was written every frame including its glance targets, which
    cancelled each idle glance one frame after it started — glances would never
    have moved the eyes. The resting pose is now lids and scale only; glance
    targets stay event-driven and persist, and only a full override (an emote or
    pairing mode) sets them.
    Micro-saccades accumulated into the glance target with nothing to bound them,
    so a long idle would random-walk the eyes into a corner. They are now clamped.
    Rapid typing restarted the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
    [macropad_v5.ino]
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2026-07-22 companion: MacroPadDeck tray app — BLE link, actions, profiles, foreground-follow
    BleLink auto-reacquires the host-link service with CCCD off->on cycling;
    DeckController maps pad key events to bindings and mirrors profiles both
    ways (foreground app auto-switch, 30s sticky manual override); ActionEngine
    does focus-or-launch, shell open, command run, and window snap/move; profiles
    hot-reload from %APPDATA%\MacroPadDeck\profiles.json.
2026-07-22 companion: fix BleLink acquire — use full GATT enumeration
    GetGattServicesForUuidAsync(Uncached) throws 0x80070016 ERROR_BAD_COMMAND
    on this stack; full GetGattServicesAsync + UUID filter (the spike's path)
    works. Adds deck.log step logging for link diagnostics.
2026-07-22 companion: Claude-design WPF editor + per-profile eye/accent color
    EditorWindow: warm-cream/terracotta profile editor mirroring the pad's 4x3
    grid — profile list with color dots, palette swatches + hex, per-key binding
    panel, save writes profiles.json (hot-reload pushes to pad). Tray gains
    open-on-double-click and a Start with Windows toggle. Firmware: PRESET_COLORS
    moves to RAM + HCMD_COLOR 0x85 recolors a preset's accent + eyes live;
    DeckController pushes all profile colors on hello and reload.
    [macropad_v5.ino]
2026-07-22 fix cell blanking after flash on rich key types; pastel preset palette
    Flash-expiry redraw still used the pre-rich-model 'id == A_NONE' emptiness
    test — every host/key/text key repainted as an empty cell after its press
    flash. Use kaEmpty(). Editor + defaults move to a pastel palette; default
    config now seeds all 8 pad presets so every preset is app-editable.
    [macropad_v5.ino]
2026-07-22 app-editable pad keys: shortcut/media/text types over host-link
    Firmware gains HCMD_KEY (full key reassignment: builtin/key/consumer/text/
    host), HCMD_TEXT (snippet payload) and HCMD_COMMIT (one NVS write per save).
    Editor's action list adds Keyboard shortcut (mod checkboxes + key picker),
    Media key, and Type text snippet; Save & push rewrites the app-managed keys
    on the pad and persists them. Macros stay web-UI-only (steps exceed MTU).
    [macropad_v5.ino]
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2026-07-22 app OTA updater, robotic-blue eye default, layout re-push on connect
    Tray gains Update firmware...: joins the pad's Config Mode hotspot via
    netsh, health-checks /api/info, streams the .bin to /api/update. Eyes
    default to robotic blue (#3ABEFF / 0x3DFF) instead of following the preset;
    HCMD_EYES 0x89 sets it from the app (persist flag; 'match preset' sends 0)
    with an editor picker. Full key layout + colors + eye color now re-push on
    every connect (RAM, no NVS wear) and commit on editor save, so a missed
    commit can no longer lose the layout.
    [macropad_v5.ino]
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2026-07-22 media: prefer native SMTC; Feishin remote fallback off by default
    Feishin's own 'mediaSession' setting was false — that, not a Windows quirk,
    was why it never appeared. With it on, Feishin publishes like any other
    player and the WebSocket workaround is redundant, so FeishinUrl now defaults
    to empty. The source stays in the tree for anyone running with mediaSession
    disabled. Poll cadence 1s and 2s position buckets so corrections land as
    small nudges rather than visible jumps.
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2026-07-22 cad: name v5 case parts (bottom / top plate / display mount)
    Part numbers replaced with what the parts actually are, plus the assembly
    stack-up order so the sandwich is obvious to anyone printing.
    [v5_case_bottom.stl, v5_case_top_plate.stl, v5_display_mount.stl]
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2026-07-22 media: age SMTC position by LastUpdatedTime — fixes bar jumping backward
    GlobalSystemMediaTransportControlsSession's TimelineProperties.Position is a
    snapshot captured at LastUpdatedTime, not a live clock: it only advances when
    the player pushes an update. Sending it raw meant the pad's own extrapolation
    crept ahead and then snapped back to the stale reading each poll — visible as
    the progress bar randomly reverting while playing, and looking correct only
    when paused (extrapolation stopped). Add the snapshot's age before sending,
    clamped to duration.
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2026-07-22 media: heart on favorited tracks + eyes react to music
    HCMD_MEDIA's playing byte becomes a flags byte (bit0 playing, bit1 favorited)
    so the pad can show a small heart beside the title; title and heart are
    centred as one unit so the text doesn't shift when a track is loved. SMTC has
    no favorites concept, so the flag is borrowed from the Feishin link when the
    titles clearly match (Feishin feeds SMTC, so they do).
    Eyes now react: EM_LOVE (warm deep squint) when a track is favorited,
    EM_EXCITED on a track change, and a slow lissajous bob while anything plays.
    The bob is applied after the state branches but before the emote layer, so
    emotes still override it. Edge events are flagged by the BLE h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
    [macropad_v5.ino]
2026-07-22 feishin: authenticate on connect + refuse mismatched favorites
    Feishin's own client sends {"event":"authenticate","header":<GET /credentials>}
    right after connecting. We never did, so Feishin treated us as a passive
    listener: we got the initial state snapshot and then no live song updates.
    The cached track went stale and a favorite press hit the wrong song.
    Now authenticate on every connect, and guard the write: ToggleFavorite takes
    the title the pad is displaying and refuses if Feishin disagrees, reporting
    TRACK MISMATCH instead. Silently editing the user's library is much worse
    than doing nothing. Also waits up to 3s for a reconnect rather than failing
    a press that landed while the socket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
2026-07-22 feishin: deliberate re-sync — the remote never pushes incremental events
    Feishin sends one full state on connect and then nothing: no song, position
    or playback events. It only ever appeared to work because the server dropped
    idle sockets and each reconnect delivered fresh state — so the previous
    'authenticate on connect' fix stabilised the socket and thereby removed the
    only refresh mechanism, freezing the cached track.
    Receive now waits with a 10s bounded token; timing out cycles the socket,
    which is the re-sync. ToggleFavorite additionally forces an immediate
    re-sync when the cached track disagrees with what the pad displays, waits up
    to 5s for it to agree, and only refuses if it sti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
2026-07-22 fix wrong hues everywhere: scope GIF byte-swap to its own pushImage
    setup() left tft.setSwapBytes(true) on for the GIF decoder, and the sprites
    are created right after — so every sprite push (grid cells, status bar, eyes,
    media strip) had its RGB565 bytes swapped, turning every colour into a
    different hue. Greys and white survived, being byte-symmetric, which is why
    text looked fine and only colours were wrong.
    Swap is now off globally and enabled only around GIFDraw's pushImage calls.
    Also log the SMTC source app, which proved Feishin is the player while its
    own remote reports a stale track.
    [macropad_v5.ino]
2026-07-22 display: panel is BGR — set TFT_RGB_ORDER
    Red and blue were swapped on every colour: robotic blue #3ABEFF rendered as
    orange (#FFBE3A). TFT_eSPI defaults ST7789 to RGB but this panel wires its
    subpixels BGR. Set in both the live User_Setup.h and the repo's canonical
    copy, so a rebuild from either doesn't regress.
    This is separate from the byte-swap fix in the previous commit; both had to
    land before colours matched what the app sends.
2026-07-22 feishin: restore authenticate — required for outbound commands
    Feishin streams state to any listener but silently drops favorite/play/next
    from clients that never authenticated, which is why reads worked while the
    favorite key appeared to succeed and changed nothing (the browser remote,
    which authenticates, could favorite the same track fine).
    The earlier removal was based on a wrong diagnosis: the 'frozen state' that
    prompted it was Feishin being paused — a paused player stops emitting state
    regardless of authentication. Confirmed by watching state resume updating the
    moment playback did.
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2026-08-01 puck: wireless ESP-NOW encoder puck + protocol v3
    Adds the standalone AS5600 dial that has been on the v5 next-steps list since the
    start: two puck sketches (ESP32-C3 and ESP-12E, functionally identical bar the
    radio API and pins) plus the receiver side in the pad. ESP-NOW interoperates
    8266<->ESP32 over the air, so either board talks to the same pad firmware.
    Protocol v3 — docs/PUCK_PROTOCOL.md is the source of truth. The struct is
    duplicated in three sketches because Arduino sketch folders cannot share a
    header; all three carry a KEEP IN SYNC marker. v3 grew it 7 -> 9 bytes and so is
    NOT wire-compatible with v2: the length check drops short packets before the
    version check runs, and the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
    [macropad_v5.ino, puck_encoder.ino, puck_encoder_8266.ino]
2026-08-01 companion: real volume source, pad-fetched action picker, music/video gating
    Three additions that all exist to feed the puck and the pad honest data.
    CoreAudioVolumeSource + VolumePusher push the true system volume to the pad
    (HCMD_VOLUME 0x8B), which relays it to the puck. BLE HID volume is relative —
    the pad sends up/down usages and is never told the level — so reading Windows
    Core Audio is the only way either device can know a real number. Tick-based
    estimation was considered and rejected: it desyncs the moment volume changes
    anywhere else, and a confidently wrong number is worse than none. The interop is
    hand-rolled IAudioEndpointVolume rather than a new NuGet dependency.
    VolumePus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
2026-08-03 firmware: leave the face screen when the host turns the face off
    HCMD_FACE only set faceMode, which stops the pad returning to the face but does not move it off. The wake-to-grid path is gated on faceMode != 2, so in ALWAYS mode a host that turned the face off to show the grid drew its labels behind the eyes, and it took a second, wasted key press to reveal them. Mode 0 now leaves SCR_FACE immediately.
    Also carries the puck OTA work: the request is latched into PK_STATE so a dozing puck picks it up on its next keepalive rather than missing a one-shot packet, and the link timeout rises to 90 s so a puck that only checks in every 60 s no longer reads as offline for most of each minute.
    [macropad_v5.ino, puck_encoder.ino]
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2026-08-03 docs: puck is complete - refresh handoff and CAD notes
    The handoff is rewritten as a completed build record rather than a blocker report. The C3 was never dead: the 2026-07-31 write-off after a lost decoupling cap was wrong or the fault cleared, and it has been the working puck on COM8 ever since, with the ESP-12E kept as a spare.
    cad/README no longer says the puck STLs are unprinted. Rev (3) is printed and test-fitted: the dial spins freely with no wobble and the AS5600 magnet pocket worked first time, despite that gap being flagged throughout as the fussy dimension.
2026-08-03 docs: add encoder puck section and build photos
    The puck had no section of its own in the README despite being a finished, separate device. Covers ESP-NOW, the AS5600, pad-owned dial mode, pushed volume, sleep and the spin-to-reboot gesture that lets the housing have no reset button.
    Photos are WhatsApp-compressed and carry no EXIF or GPS data.
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2026-08-24 companion: editor visual pass and the write key type (Windows)
    Imported from the Windows working tree (C:\claude_code), where it was left
    uncommitted on 2026-08-10.
    - Contrast: Muted was #87867F, 3.15:1 on the #F0EEE5 card and used at 11px,
    which fails WCAG AA. It becomes #6B6A63 (4.67:1). The link-status green
    and red and the unbound key label move for the same reason.
    - Hierarchy: one grouping device per level. Cards were fill + hairline
    border + shadow with bordered tiles nested inside; they keep fill and
    shadow only, and the border budget is spent on selection. Key tiles now
    carry a constant 2px border — ink when selected, transparent otherwise —
    so selecting never nudge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
2026-09-01 hardware: bring the KiCad project and ESP-12E datasheet into this clone
    These lived only in the home checkout, which forked at de5f1d5 and went its own
    way (it renamed v5 to v6 over an older snapshot of the firmware). This clone has
    the newer firmware, the companion and the puck, so it is the one that keeps
    going — the PCB sources and the datasheet are what the other side genuinely had
    that this one did not.
    Not carried over: macropad.zip, a 3.7 MB archive of the KiCad project with its
    own .git inside it, redundant with the loose sources; CONTEXT.md, a private
    working doc; and firmware/v6, which is firmware/v5 minus the mouth, the puck and
    the host-link opcodes.
    .gitattributes comes acro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
    [macropad-B_Cu.gbr, macropad-B_Mask.gbr, macropad-B_Paste.gbr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]
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2026-09-23 firmware: brows are short tapered arches, closer to the eye
    The flat 78%-wide bar 12px above the eye read as a floating dash, and
    when angry drew a second line parallel to the lid wedge. Now 62% wide,
    8px up, nudged toward the nose, 6px thick tapering to ~3; anger
    flattens the arch so it joins the lid into one scowl. Preview keeps
    the old bar as a comparison option. Compiled only.
    [macropad_v5.ino]
2026-09-23 firmware: 'bot' LED face look and a favourite heart
    FV2_BOT (on by default): round glowing eyes, a D-shaped mouth that opens
    into a flat-topped grin as valence rises, and a dot-matrix texture (2x2
    dots on a 3px screen-aligned pitch) with a 3px halo. Own geometry below
    the puck label; eye/mouth sprites are resized per look (bot 37 KB vs
    classic 31 KB) and fall back to classic if allocation fails.
    Favouriting now turns the whole face into an LED-matrix heart that pops
    in, beats lub-dub twice and shrinks into the LOVE squint (2.4 s),
    rendered in tiles through sprEye with windowed pushes - no extra RAM.
    Replaces the margin-particle hearts. Compiled only (70% flash).
    [macropad_v5.ino]
2026-09-23 firmware: give each host slot its own BLE address
    All three multi-host slots shared one BLE identity, which made the slots
    unusable for the case they exist to serve. Two OSes dual-booting a single
    machine present the *same* controller address (it is burned into the
    adapter), so slotForAddress() mapped them to one slot:
    - the second OS was kicked as EVT_WRONG_HOST and could never claim a
    slot of its own — "device 2 doesn't work"
    - both OSes shared the single stored LTK, so each re-pair staled the
    other's key — the endless forget-and-re-pair loop on every OS switch
    Each slot now advertises its own static-random address derived from the BT
    MAC, so every host stores an independ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
    [macropad_v5.ino]
2026-09-23 firmware: per-slot bond keys; slot ownership by advertised address
    Fixes slots 1 and 3 refusing the dual-boot laptop from either OS while
    only slot 2 worked. The per-slot address change fixed the HOST side of
    the "two OSes, one adapter MAC" collision; the pad still decided slot
    ownership from the PEER address (slotForAddress -> EVT_WRONG_HOST), so
    once one OS bonded on a slot, the same machine was rejected on every
    other slot. Underneath, NimBLE's bond store is keyed by peer address
    only and a re-pair replaces the entry, so even the one working slot
    needed a re-pair on every OS switch.
    - Slot ownership comes from the address the host connected to. Each
    slot advertises its own, so whoever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
    [macropad_v5.ino]
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2026-09-23 firmware: allocate face sprites once at boot so the look toggle can't fail
    Resizing sprEye/sprMouth per look at runtime failed on a fragmented heap:
    the bot set (~37 KB) would not allocate after boot, and the fallback
    quietly cleared FV2_BOT in RAM. Seen live: tray sent 'bot' (write=True)
    and the next hello reported faceV2=0x0F. Both sprites are now created in
    setup() at the larger look's size (eye 100x124, mouth 160x64, 45 KB) and
    each look pushes its own window; switching allocates nothing.
    [macropad_v5.ino]
2026-09-23 Revert "firmware: allocate face sprites once at boot so the look toggle can't fail"
    This reverts commit a6c0770b40015e36cc06d229ad1d2013ab64a442.
    [macropad_v5.ino]
2026-09-23 firmware: switching the face look reboots the pad instead of reallocating
    a6c0770 (allocate both looks' sprites at boot, 45 KB) crash-looped the
    pad once a host connected — ~8 KB more held during BLE than the build
    that ran fine. Reverted. The runtime resize it replaced fails on a
    fragmented heap, so setFaceV2 now persists and restarts when the look
    bit changes; the look is only ever set up at boot, which is proven.
    [macropad_v5.ino]
2026-09-23 face look is per firmware build; tray flashes bot or classic image
    Runtime look switching failed twice on the ESP32 heap (resize: bot
    sprites won't allocate once fragmented; both sizes up front: the pad
    crash-looped once a host connected). The look is now fixed at compile
    time (FACE_LOOK_BOT, classic via -DFACE_LOOK_BOT=0) and NVS can't
    override it. New HCMD_CONFIG 0x90 ['C''F'] puts the pad in config mode
    over BLE, so Tray -> Face style flashes the other image unattended:
    config mode, join hotspot, OTA, back to the previous WiFi.
    firmware/v5/build-face-images.sh builds and installs both images.
    [macropad_v5.ino]
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2026-09-23 firmware: face v3 — one visor face (SDF shapes in a 4-bit sprite, springs, emotes, beat dance)
    Replaces the classic/bot looks, brows, dot grid, tiled heart and particles
    with a single renderer: eyes and mouth are signed-distance shapes drawn
    into one 240x150 4-bit sprite (18 KB, allocated once in setup) with a
    16-level glow palette. Every shape number is a spring, so any expression
    morphs into any other.
    - 14 expressions, emotes with motion (hop, bounce, pulse, jolt, shake...)
    - pad-side trigger map (boot, connect, typing, idle, track, fave, flair...)
    with chance + cooldown, NVS 'emap'; HCMD_EMOTEMAP 0x92
    - HCMD_EMOTE 0x91 for host-side events, HCMD_DANCE 0x93 (level, flair bars)
    - danc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
    [macropad_v5.ino]
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2026-09-24 firmware: tighter eye boxes + early-out, render/push split in the profile log
    [macropad_v5.ino]
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
